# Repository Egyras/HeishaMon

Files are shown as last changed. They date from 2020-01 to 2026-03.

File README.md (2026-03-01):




# Panasonic H, J, K & L Series Aquarea air-water heat pump protocol

This project makes it possible to read information from Panasonic Aquarea heat pump and report the data either to an MQTT server or as JSON format over HTTP.

Eine deutschsprachige [README_DE.md](README_DE.md) findest du hier. \
Een nederlandse vertaling [README_NL.md](README_NL.md) vind je hier. \
Suomen kielellä [README_FI.md](README_FI.md) luettavissa täällä.

*Help on translation to other languages is welcome.*

# Current releases
Latest release is available [here](https://github.com/Egyras/HeishaMon/releases). The ESP8266 compiled binary can be installed on a Wemos D1 mini, on the HeishaMon PCB and generally on any ESP8266 based board compatible with Wemos build settings (at least 4MB flash). You can also download the code and compile it yourself (see required libraries below). The ESP32-S3 binary is for the newer, large, version of heishamon.

# Using the software
HeishaMon is able to communicate with the Panasonic Aquarea H, J, K and L&series. [Confirmed by users types of HP you can find here](HeatPumpType.md) \
If you want to compile this image yourself be sure to use the mentioned libraries and support for a filesystem on the esp8266 so select the correct flash option in arduino ide for that.

When starting, without a configured wifi, an open-wifi-hotspot will be visible allowing you to configure your wifi network and your MQTT server. Configuration page will be located at http://192.168.4.1 . \

After configuring and booting the image will be able to read and talk to your heatpump. The GPIO13/GPIO15 connection will be used for communications so you can keep your computer/uploader connected to the board if you want. \
Serial 1 (GPIO2) can be used to connect another serial line (GND and TX from the board only) to read some debugging data.

All received data will be sent to different MQTT topics (see below for topic descriptions). There is also a 'panasonic_heat_pump/log' MQTT topic which provides debug logging and a hexdump of the received packets (if enabled in the web portal).

You can connect a 1wire network on GPIO4 which will report in seperate MQTT topics (panasonic_heat_pump/1wire/sensorid).

The software is also able to measure Watt on a S0 port of two kWh meters. You only need to connect GPIO12 and GND to the S0 of one kWh meter and if you need a second kWh meter use GPIO14 and GND. It will report on MQTT topic panasonic_heat_pump/s0/Watt/1 and panasonic_heat_pump/s0/Watt/2 and also in the JSON output. You can replace 'Watt' in the previous topic with 'Watthour' to get consumption counter in WattHour (per mqtt message) or to 'WatthourTotal' to get the total consumption measured in WattHour. To sync the WatthourTotal with your kWh-meter, publish the correct value to MQTT to the panasonic_heat_pump/s0/WatthourTotal/1 or panasonic_heat_pump/s0/WatthourTotal/2 topic with the 'retain' option while heishamon is rebooting. Upon reboot, heishamon reads this value as the last known value to you can sync using this method.

Updating the firmware is as easy as going to the firmware menu and, after authentication with username 'admin' and password 'heisha' (or other provided during setup), uploading the binary there.

A json output of all received data (heatpump and 1wire) is available at the url http://heishamon.local/json (replace heishamon.local with the ip address of your heishamon device if MDNS is not working for you).

Within the 'integrations' folder you can find examples how to connect your automation platform to the HeishaMon.

# Rules functionality
The rules functionality allows you to control the heatpump from within the HeishaMon itself. Which makes it much more reliable then having to deal with external domotica over WiFi. When posting a new ruleset, it is immidiatly validated and when valid used. When a new ruleset is invalid it will be ignored and the old ruleset will be loaded again. You can check the console for feedback on this. If somehow a new valid ruleset crashes the HeishaMon, it will be automatically disabled the next reboot, allowing you to make changes. This prevents the HeishaMon getting into a boot loop.

The techniques used in the rule library allows you to work with very large rulesets, but best practice is to keep it below 10.000 bytes.

Notice that sending commands to the heatpump is done asynced. So, commands sent to the heatpump at the beginning of your syntax will not immediatly be reflected in the values from the heatpump later on. Therefor, heatpump values should be read from the heatpump itself instead of those based on the values you keep yourself.

## Syntax
Two general rules are that spaces are mandatory and semicolons are used as end-of-line character.

### Variables
The ruleset uses the following variable structure:

- `#`: Globals
These variables can be accessed throughout the ruleset but have to defined inside a rule block. Don't use globals for all your variables, because it will persistently use memory.

- `$`: Locals
These variables live inside a rule block. When a rule block finishes, these variables will be cleaned up, freeing any memory used.

- `@`: Heatpump parameters
These are the same as listed in the Manage Topics documentation page and as found on the HeishaMon homepage. The ruleset also follows the R/W logic as used through the MQTT and REST API. That means that the read topics differ from the write topics. So reading the heatpump state is done through `@Heatpump_State`, changing the heatpump state through `@SetHeatpump`.

- `%`: Datetime variables
These can be used for date and time based rules. Currently `%hour` (0 - 23), `%minute` (0 - 59), `%month` (1 - 12), and `day` (1 - 7)  are supported. All are plain integers. A proper NTP configuration is needed to set the correct system date and time on the HeishaMon.

- `?`: Thermostat parameters
These variables reflect parameters read from the connected thermostat when using the OpenTherm functionality. When OpenTherm is supported this documentation will be extended with more precise information. The can check the opentherm tab for the variables that can be used. The names are the same for reading and writing, but not all values support reading and/or writing. The opentherm tab also lists this.

- `ds18b20#2800000000000000`: Dallas 1-wire temperature values
Use these variables to read the temperature of the connected sensors. These values are of course readonly. The id of the sensor should be placed after the hashtag.

- `s0#watt[hour[total]]_?`: The S0 values for port 1 and 2. Replace the question mark with the port number.
For example s0#watt_1 to get watt from port 1 and s0#watthourtotal_2 to get total watthours from port 2

When a variable is called but not yet set to a value, the value will be `NULL`.

Variables can be of boolean (`1` or `0`), float (`3.14`), integer (`10`), and string type. Defining strings is done with single or double quotes.

### Events or functions
Rules are written in `event` or `function` blocks. These are blocks that are triggered when something happened; either a new heatpump or thermostat value has been received or a timer fired. Or can be used as plain functions

```
on [event] then
  [...]
end

on [name] then
  [...]
end
```

Events can be Heatpump or thermostat parameters or timers:
```
on @Heatpump_State then
  [...]
end

on ?setpoint then
  [...]
end

on timer=1 then
  [...]
end
```

When defining functions, you just name your block and then you can call it from anywhere else:
```
on foobar then
  [...]
end

on @Heatpump_State then
  foobar();
end
```

Functions can have parameters which you can call:
```
on foobar($a, $b, $c) then
  [...]

on @Heatpump_State then
  foobar(1, 2, 3);
end
```

If you call a function less values then the function takes, all other parameters will have a NULL value.

There is currently one special function that calls when the system is booted on when a new ruleset is saved:
```
on System#Boot then
  [...]
end
```

This special function can be used to initially set your globals or certain timers.

### Operators
Regular operators are supported with their standard associativity and precedence. This allows you to also use regular math.
- `&&`: And
- `||`: Or
- `==`: Equals`
- `>=`: Greater or equal then
- `>`: Greater then
- `<`: Lesser then
- `<=`: Lesser or equal then
- `-`: Minus
- `%`: Modulus
- `*`: Multiply
- `/`: Divide
- `+`: Plus
- `^`: Power

Parenthesis can be used to prioritize operators as it would work in regular math.

### Functions
- `coalesce`
Returns the first value not `NULL`. E.g., `$b = NULL; $a = coalesce($b, 1);` will return 1. This function accepts an unlimited number of arguments.

- `max`
Returns the maximum value of the input parameters.

- `min`
Returns the minimum value of the input parameters.

- `isset`
Return boolean true when the input variable is still `NULL` in any other cases it will return false.

- `round`
Rounds the input float to the nearest integer.

- `floor`
The largest integer value less than or equal to the input float.

- `ceil`
The smallest integer value greater than or equal to the input float.

- `setTimer`
Sets a timer to trigger in X seconds. The first parameter is the timer number and the second parameters the number of seconds before it fires. A timer only fires once so it has to be re-set for recurring events. When a timer triggers it will can the timer event as described above. E.g.

- `print`
Prints a value to the console.

- `concat`
Concatenates various values into a combined string. E.g.: `@SetCurves = concat('{zone1:{heat:{target:{high:', @Z1_Heat_Curve_Target_High_Temp, ',low:32}}}}');`

- `gpio`
Allows setting or getting a GPIO state. When called with a single argument, a GPIO state is returned. When called with two arguments the state of a GPIO is set. This function only sets digital pins so the state can only be 0 or 1. The two relays on the large heishamon are gpio21 and gpio47. See the example to switch them each two seconds.

```
on System#Boot then
   setTimer(10, 2);
end

on timer=10 then
   setTimer(20, 2);
   gpio(21,0);
   gpio(47,1);
end

on timer=20 then
   setTimer(10, 2);
   gpio(21,1);
   gpio(47,0);
end
```

### Conditions
The only supported conditions are `if`, `else`, and `elseif`:

```
if [condition] then
  [...]
else
  if [condition] then
    [...]
  end
end
```

```
if [condition] then
  [...]
elseif [condition] then
  if [condition] then
    [...]
  else
    [...]
  end
elseif [condition] then
  [...]
else
  [...]
end
```

### Examples
Once the rules system is in used by more and more users, additional examples will be added to the documentation.

*Calculating WAR*
```
on calcWar($Ta1, $Tb1, $Ta2, $Tb2) then
	#maxTa = $Ta1;

	if @Outside_Temp >= $Tb1 then
		#maxTa = $Ta1;
	elseif @Outside_Temp <= $Tb2 then
		#maxTa = $Ta2;
	else
		#maxTa = $Ta1 + (($Tb1 - @Outside_Temp) * ($Ta2 - $Ta1) / ($Tb1 - $Tb2));
	end
end
```

*Thermostat setpoint*
```
on ?roomTemp then
	calcWar(32, 14, 41, -4);

	$margin = 0.25;

	if ?roomTemp > (?roomTempSet + $margin) then
		if @Heatpump_State == 1 then
			@SetHeatpump = 0;
		end
	elseif ?roomTemp < (?roomTempSet - $margin) then
		if @Heatpump_State == 0 then
			@SetHeatpump = 1;
		end
	else
		@SetZ1HeatRequestTemperature = round(#maxTa);
	end
end
```

# Factory reset
A factory reset can be performed on the web interface but if the web interface is unavailable you can perform a double reset. The double reset should be performed not too fast but also not too slow. Usually halve a second between both resets should do the trick. To indicate that the double reset performed a factory reset, the blue led will flash rapidly (You need to press reset again now to restart HeishaMon back to normal where a WiFi hotspot should be visible again).

# Further information
Below you can find some technical details about the project. How to build your own cables. How to build your own PCB etc.

## Connection details:
Communication can be established thru one of the two sockets: CN-CNT or CN-NMODE. If you have an existing Panasonic CZ-TAW1 WiFi interface that you want to replace with HeishaMon, it is only a matter of plugging the cable out from CZ-TAW1 and reconnecting to your HeishaMon device. However it is not possible to use HeishaMon and the original CZ-TAW1 module together as an active device. It is however possible to put HeishaMon on "Listen Only" mode which will allow HeishaMon and the original CZ-TAW1 module to co-exist. The only downside to this is that HeishaMon is unable to send commands and use the optional PCB option.

Communication parameters: TTL 5V UART 9600,8,E,1  \
 \
CN-CNT Pin-out (from top to bottom) \
1 - +5V (250mA)  \
2 - 0-5V TX (from heatpump) \
3 - 0-5V RX (to heatpump)\
4 - +12V (250mA) \
5 - GND \
 \
CN-NMODE Pin-out (from left to right) \
"Warning! As printed on the PCB, the left pin is pin 4 and right pin is pin 1. Do not count 1 to 4 from left!  \
4 - +5V (250mA)  \
3 - 0-5V TX (from heatpump) \
2 - 0-5V RX (to heatpump) \
1 - GND

HeishaMon will receive power from the Panasonic over the cable (5v power).

## Long distance connection
It it possible to connect the HeishaMon over a long distance. Up to 5 meter is working with normal cabling. For longer distances a TTL-to-RS485 configuration as show in the picture below is possible. The however requires HeishaMon to be powered externally using 5v power (for example from an USB cable).

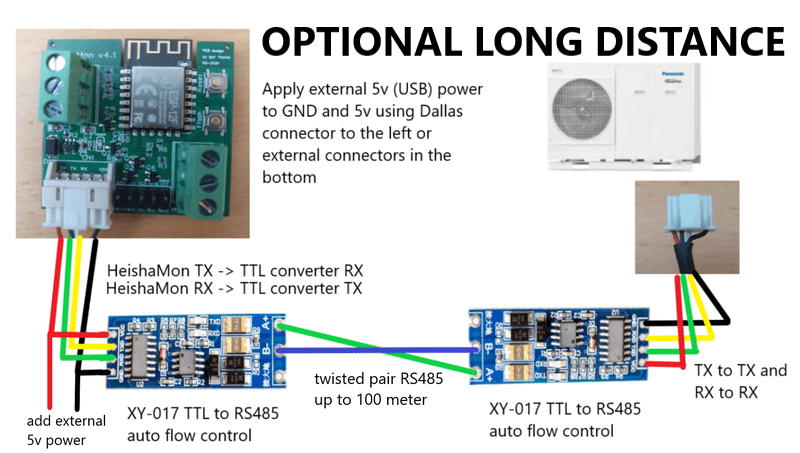
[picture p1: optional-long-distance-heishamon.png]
TTL-over-RS485 HeishaMon long distance


## Where to get connectors
[RS-Online orders](Connectors_RSO.md)

[Conrad orders](Connectors_Conrad.md)

Use some 24 AWG shielded 4-conductors cable.

## The HeishaMon hardware itself
The PCB's needed to connect to the heatpump are designed by project members and are listed below. The most important part of the hardware is a level shifting between 5v from the Panasonic to 3.3v of the HeishaMon and a GPIO13/GPIO15 enable line after boot. \
[PCD Designs from the project members](PCB_Designs.md) \
[Picture Wemos D1 beta](WEMOSD1.JPG) \
[Picture ESP12-F](NewHeishamon.JPG)

To make things easy you can order a completed PCB from some project members: \
[Tindie shop](https://www.tindie.com/stores/thehognl/) from Igor Ybema (aka TheHogNL) based in the Netherlands

## Building the arduino image yourself
boards: \
esp8266 by esp8266 community version 3.0.2 [Arduino](https://github.com/esp8266/Arduino/releases/tag/3.0.2)

All the [libs we use](LIBSUSED.md) necessary for compiling.

## MQTT topics
[Current list of documented MQTT topics can be found here](MQTT-Topics.md)

## Communication reliability
Messages from HeishaMon to the heatpump will occasionally be dropped, especially if multiple settings are changed within a short time. It's not feasible for HeishaMon to retry all dropped messages, so users should implement their own retry logic.

The suggested retry logic is as follows:
1. After changing a heatpump setting via HeishaMon, you should wait for HeishaMon to report that the setting has been changed.
2. If the setting isn't updated after 10 seconds, set it again.

This can be implemented on the HeishaMon itself using Rules if you wish, as in this example:
```
on StopExternalControl then
  if @External_Control != 0 then
    @SetExternalControl = 0;
    settimer(9,10);
  end
end

on timer=9 then
  if @External_Control != 0 then
    @SetExternalControl = 0;
  end
end
```

## EEPROM warning
As until today we don't know how the commands sent to the heatpump are processed in the heatpump itself. Most probably a lot of commands are written to EEPROM to be stored and available after a power failure, like setting the DHW temp. An EEPROM can facility a lot of writes but there is a limit. And we don't know the limit either. So make sure you don't overload the heatpump with too many commands. Every second is way too much. Just a few per hour, per settings, should probably be fine. Anyway, an heatpump is a slow heating(cooling) device so making changes that often is probably not even going to make any sense either.

## DS18b20 1-wire support
The software also supports ds18b20 1-wire temperature sensors reading. A proper 1-wire configuration (with 4.7kohm pull-up resistor) connected to GPIO4 will be read each configured secs (minimal 5) and send at the panasonic_heat_pump/1wire/"sensor-hex-address" topic. On the pre-made boards this 4.7kohm resistor is already installed.

## Large board relay control
The newer, large, heishamon contains two onboard relays which can be switched on and off using MQTT commands. The relays can be used for any contact switching, even 230V mains (max 5A). For example to switch the 230V contacts in the heatpump for controlling the 'external thermostat', switching a pump on or off or other lower power devices. I do not recommend to use the relay as a switch for a electric heater as they use too much power. To control the relay just send a value of 1 or 0 to the MQTT topic "panasonic_heat_pump/gpio/relay/one" for relay one or "panasonic_heat_pump/gpio/relay/two" for relay two.

## Opentherm support
If your heishamon board supports opentherm the software can also be used to bridge opentherm information from a compatible thermostat to your home automation over MQTT or JSON and as mentioned above it can also be connected directly in the rules to connect opentherm information to the heatpump and back, for example to display the outside temperature from the heatpump on your opentherm thermostat. If you enable opentherm support in settings there will be a new tab visible in the web page. On that tab you will see opentherm values. Some are of type R(ead) and some are W(rite), and some are both. Read means that the thermostat can read that information from the heishamon. You provide that information over MQTT (or using the rules) by updating this value on the mqtt 'opentherm/read' topic, for example 'panasonic_heat_pump/opentherm/read/outsideTemp'. The write values are information from the thermostat, like 'roomTemp'. These are available on mqtt topic 'opentherm/write'. You can use these values to change the heatpump behaviour in anyway you want using your home automation and mqtt set-commands to heishamon on using the internal rules.

The available opentherm variables are:
### WRITE values
- chEnable which is a boolean showing if central heating shoud be enabled. This is often used when the thermostat wants to heat up your house.
- dhwEnable which is a boolean showing if the dhw heating should be enabled. Often used as a user option on the thermostat to disable DHW heating during vacation
- coolingEnable which is a boolean showing if  cooling should be enabled. Amount of cooling is request in 'coolingControl', see below.
- roomTemp is the floating point value of the measured room temp by thermostat
- roomTempSet is the floating point value of the requested room temp setpoint on the thermostat
- chSetpoint is the floating point value of the calculated water setpoint by thermostat. Opentherm thermostats try to set this chSetpoint to not overshoot the room setpoint. Could be used to set the water setpoint on the heatpump but most thermostats are too fast responding compared to how heatpumps work
- maxRelativeModulation is the amount of modulation (0-100%) the heatpump (opentherm slave) is allowed to use (see relativeModulation in READ values, which should always be equal or lower than this max)
- coolingControl is the amount of cooling (0-100%) the thermostat requests from the heatpump. Requires an opentherm thermostat with cooling support.
### READ AND WRITE values
- dhwSetpoint is the floating point value which is the current DHW setpoint by thermostat, but can also be set by heishamon to override it. Not all thermostat support this though. It should not be set higher than dhwSetUppBound, see below.
- maxTSet is the floating point value which defines the maximum water setpoint. The user can set this on the thermostat or can also set from heishamon. It should not be set higher than chSetUppBound, see below.
### READ values
- chPressure is the floating point value which defines measured water pressure of central heating provided by heishamon
- outsideTemp is the floating point value which defines measured outside temperature of central heating provided by heishamon
- inletTemp is the floating point value which defines measured water inlet temperature of central heating provided by heishamon
- outletTemp is the floating point value which defines measured water outlet temperature of central heating provided by heishamon
- dhwTemp is the floating point value which defines measured dhw temperature of central heating provided by heishamon
- relativeModulation is the amount (0-100%) of modulation the heatpump (opentherm slave) is currently running on, should always be lower or equal than the maxRelativeModulation set by the thermostat
- flameState is a boolean value (send 'true', 'on' or '1' to enable) which defines if the central heating is providing heat central
- chState is a boolean value (send 'true', 'on' or '1' to enable) which defines if the heatpump is on room/central heating mode (for example 3-way valve on room, in heating mode)
- dhwState is a boolean value (send 'true', 'on' or '1' to enable) which defines if the heatpump is on DHW mode (for example 3-way valve on dhw)
- coolingState is a boolean value (send 'true', 'on' or '1' to enable) which defines if the heatpump is on room/central cooling mode (for example 3-way valve on room, in cooling mode)
- dhwSetUppBound is a integer value from 0 to 127 which sets the max DHW temperature supported so the thermostat can not request a dhwSetpoint higher than this. Default is set to 75. To override, send a MQTT message to this topic and make it retained so heishamon receives it again after reboot.
- dhwSetLowBound is a integer value from 0 to 127 which sets the min DHW temperature supported so the thermostat can not request a dhwSetpoint lower than this. Default is set to 40. To override, send a MQTT message to this topic and make it retained so heishamon receives it again after reboot.
- chSetUppBound is a integer value from 0 to 127 which sets the max CH (heating water) temperature supported so the thermostat can not request a chSetpoint higher than this. Default is set to 65. To override, send a MQTT message to this topic and make it retained so heishamon receives it again after reboot.
- chSetLowBound is a integer value from 0 to 127 which sets the min CH (heating water) temperature supported so the thermostat can not request a chSetpoint lower than this. Default is set to 20. To override, send a MQTT message to this topic and make it retained so heishamon receives it again after reboot.

## Protocol byte decrypt info:
[Current list of documented bytes decrypted can be found here](ProtocolByteDecrypt.md)

## MQTT TLS support:
TLS support or MQTT is currently implemented only for the ESP32 version. TLS is disabled by default and can be enabled in the settings. When enabling, make sure that your MQTT broker accepts secure connection from heishamon, including setting up a PEM CA certificate (e.g. self-signed). Such a certificate will roughly look as follows (the x's being seemingly random characters... the BEGIN and END lines belong to the certificate):
-----BEGIN CERTIFICATE-----
xxxxxxxxxxxxxxxxxxxxxxxxxxxxxxxxxxxxxxxxxxxxxxxxxxxxxxxxxxxxxxxxxxxxxxxxxxxxxxxx
xxxxxxxxxxxxxxxxxxxxxxxxxxxxxxxxxxxxxxxxxxxxxxxxxxxxxxxxxxxxxxxxxxxxxxxxxxxxxxxx
xxxxxxxxxxxxxxxxxxxxxxxxxxxxxxxxxxxxxxxxxxxxxxxxxxxxxxxxxxxxxxxxxxxxxxxxxxxxxxxx
===========THIS=====IS====JUST===A====PLACEHOLDER===============================
xxxxxxxxxxxxxxxxxxxxxxxxxxxxxxxxxxxxxxxxxxxxxxxxxxxxxxxxxxxxxxxxxxxxxxxxxxxxxxxx
xxxxxxxxxxxxxxxxxxxxxxxxxxxxxxxxxxxxxxxxxxxxxxxxxxxxxxxxxxxxxxxxxxxxxxxxxxxxxxxx
xxxxxxxxxxxxxxxxxxxxxxxxxxxxxxxxxxxxxxxxxxxxxxxxxxxxxxxxxxxxxxxxxxxxxxxxxxxxxxxx
-----END CERTIFICATE-----
Upolad a text file (plain text with suffix pem, e.g. "CA.pem") of the certificate to heishamon in the setting screen. If the syntaxt is correct it will be stored, otherwise discarded. After having uploaded the certificate, activate TLS support and (in usual setups) switch the MQTT port to 8883. !!There will be no support for TLS problems!! Google can help you with problems. In case of problems, first try without TLS support and only after that works try to switch TLS support on.
Currently, there is no possibility to delete a once-uploaded CA certificate. So if you want to remove your certificate, simply upload the dummy/sample above.

## Integration Examples for Opensource automation systems
[Openhab2](Integrations/Openhab2)

[Home Assistant](Integrations/Home%20Assistant)

[IOBroker Manual](Integrations/ioBroker_manual)

[Domoticz](Integrations/Domoticz)

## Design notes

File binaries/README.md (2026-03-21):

This directory contains released and test versions for the HeishaMon software. 

The latest production release is v4.1. 

Make sure you use the correct firmware for your model. The 'small' version is for the HeishaMon PCB which has the ESP8266 chip. The 'large' version is for the newer ESP32-S3 HeishaMon PCB. You can recognize the 'large' version as the one with optional ethernet support and the two blue relays. The large board is about 10x10cm while the small version is about 4x4cm (without OT) or 4x5cm(with OT).

If you upload the wrong firmware you can brick your HeishaMon and you need to recover it using a USB-TTL cable for the small version and a USB-C cable for the large version.

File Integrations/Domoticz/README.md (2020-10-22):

# Heishamon in Domoticz

There are two options to integrate HeishaMon into Domoticz. You can choose for the domoticz plugin or a nodered flow. The domoticz plugin is plug-and-play but the nodered flow will allow you to more fine tune your system to your needs.

## Plugin option

A domoticz plugin (https://github.com/MarFanNL/HeishamonMQTT) is available which, once installed, will create the necessary device and will talk to mqtt for you.

## Nodered option

Prerequisite:
- Domoticz with mqtt setup
- node-red with mosquitto (optionally with https://flows.nodered.org/node/node-red-contrib-influxdb installed)
- Working PCB with Heishamon firmware installed

Installation instructions:

In Influx:
- create a database called "Panasonic" (go to SSH console -> typ "influx" -> typ "create database Panasonic" -> typ "show databases" and see if Panasonic is listed)

In Node-red:
- import the 'json' file 
- adjust the IDX values in the Node-Red function 'global setup' to the IDX values of your install. 
- note: you have to adjust values under "SensorMapping" (values from Panasonic to Domoticz) and "ActionMapping" (Domoticz commands to Panasonic). These IDX values can be the same. 
- If nodered is on other server then the influx or MQTT server then change these IP addresses in the outgoing and incoming nodes.
- If you are not using influx out open the "influx out" node and disable it (bottom of the screen)

For example create these devices in Domoticz:
- Create the following dummy sensors in Domoticz and use the IDX values in the corresponding lines in the setup node.
  Temperature:
  - Outlet
  - Inlet
  - Outdoor
  Percentage:
  - Pumpspeed 
  - Compressor frequency
  Counter:
  - startstops 
  - working hours
  
- Create the following switches:
  - On Off switch (switch heatpump on/off)
  - Selector switch (to set the silent mode: Off, silent 1, Silent 2, Silent 3)
  - Thermostat Setpoint (to set the heatpump setpoint or temperature shift)

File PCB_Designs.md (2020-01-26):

## PCB designs

### (beta) production 2019 / 2020

| Soldering technique | Type | Link | Status |
| ----- | ---- | --- | ---: |
| Through hole soldering | Wemos shield type. With basic components (resistors and transistors)| https://easyeda.com/igor_6537/panasonic-cn-cnt-to-wemos-through-hole | beta |
| SMD+PCB delivering, only pin headers soldering | Wemos shield type. With SMD components (mosfet instead of transistors) | https://easyeda.com/igor_6537/panasonic-cn-cnt-to-wemos | beta |
| SMD+PCB delivering, only pin headers soldering  | Wemos shield type. Adding extra features (1wire, s0, relay) | https://easyeda.com/igor_6537/panasonic-cn-cnt-to-wemos_copy  | beta |
| Requires SMD soldering | ESP-12f type | https://easyeda.com/kompiuteriu/new-cn-cnt| beta |
| Requires SMD soldering | ESP-12f type with 1wire support| https://easyeda.com/kompiuteriu/new-cn-cnt_copy | beta |

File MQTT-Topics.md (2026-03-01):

# MQTT Topics for HeishaMon

## Availability Topic:

ID | Topic | Response
--- | --- | ---
|| LWT | Online/Offline (automatically returns to Offline if connection with the HeishaMon lost)

## Log Topic:

ID | Topic | Response
--- | --- | ---
LOG1 | log | response from headpump (level switchable)

## Sensor Topics:

ID | Topic | Response/Description
:--- | --- | ---
TOP0 | main/Heatpump_State | Heatpump state (0=off, 1=on)
TOP1 | main/Pump_Flow | Pump flow (l/min)
TOP2 | main/Force_DHW_State | DHW status (0=off, 1=on)
TOP3 | main/Quiet_Mode_Schedule | Quiet mode schedule (0=inactive, 1=active)
TOP4 | main/Operating_Mode_State | Operating mode (0=Heat only, 1=Cool only, 2=Auto(Heat), 3=DHW only, 4=Heat+DHW, 5=Cool+DHW, 6=Auto(Heat)+DHW, 7=Auto(Cool), 8=Auto(Cool)+DHW)
TOP5 | main/Main_Inlet_Temp | Main inlet water temperature (°C)
TOP6 | main/Main_Outlet_Temp | Main outlet water temperature (°C)
TOP7 | main/Main_Target_Temp | Main outlet water target temperature (°C)
TOP8 | main/Compressor_Freq | Compressor frequency (Hz)
TOP9 | main/DHW_Target_Temp | DHW target temperature (°C)
TOP10 | main/DHW_Temp | Actual DHW temperature (°C)
TOP11 | main/Operations_Hours | Heatpump operating time (Hours)
TOP12 | main/Operations_Counter | Heatpump starts (counter)
TOP13 | main/Main_Schedule_State | Main thermostat schedule state (0=inactive, 1=active)
TOP14 | main/Outside_Temp | Outside ambient temperature (°C)
TOP15 | main/Heat_Power_Production | Thermal heat power production (Watt)
TOP16 | main/Heat_Power_Consumption | Elektrical heat power consumption at heat mode (Watt)
TOP17 | main/Powerful_Mode_Time | Powerful state in minutes (0, 1, 2 or 3 x 30min)
TOP18 | main/Quiet_Mode_Level | Quiet mode level (0=off, 1=less power, 2=even less power, 3=least power)
TOP19 | main/Holiday_Mode_State | Holiday mode (0=off, 1=scheduled, 2=active)
TOP20 | main/ThreeWay_Valve_State | 3-way valve mode (0=Room, 1=DHW)
TOP21 | main/Outside_Pipe_Temp | Outside pipe temperature (°C)
TOP22 | main/DHW_Heat_Delta | DHW heating delta (-12 to -2) (K)
TOP23 | main/Heat_Delta | Heat delta (K)
TOP24 | main/Cool_Delta | Cool delta (K)
TOP25 | main/DHW_Holiday_Shift_Temp | DHW Holiday shift temperature  (-15 to +15)
TOP26 | main/Defrosting_State | Defrost state (0=off, 1=on)
TOP27 | main/Z1_Heat_Request_Temp | Zone 1 Heat Requested shift temp (-5 to 5) or direct heat temp (20 to max)
TOP28 | main/Z1_Cool_Request_Temp | Zone 1 Cool Requested shift temp (-5 to 5) or direct cool temp (5 to 20)
TOP29 | main/Z1_Heat_Curve_Target_High_Temp | Target temperature at lowest point on the heating curve (°C)
TOP30 | main/Z1_Heat_Curve_Target_Low_Temp | Target temperature at highest point on the heating curve (°C)
TOP31 | main/Z1_Heat_Curve_Outside_High_Temp | Lowest outside temperature on the heating curve (°C)
TOP32 | main/Z1_Heat_Curve_Outside_Low_Temp | Highest outside temperature on the heating curve (°C)
TOP33 | main/Room_Thermostat_Temp | Remote control thermostat temp (°C)
TOP34 | main/Z2_Heat_Request_Temp | Zone 2 Heat Requested shift temp (-5 to 5) or direct heat temp (20 to max)
TOP35 | main/Z2_Cool_Request_Temp | Zone 2 Cool Requested shift temp (-5 to 5) or direct cool temp (5 to 20)
TOP36 | main/Z1_Water_Temp | Zone 1 Water outlet temperature (°C)
TOP37 | main/Z2_Water_Temp | Zone 2 Water outlet temperature (°C)
TOP38 | main/Cool_Power_Production | Thermal cooling power production (Watt)
TOP39 | main/Cool_Power_Consumption | Elektrical cooling power consumption (Watt)
TOP40 | main/DHW_Power_Production | Thermal DHW power production (Watt)
TOP41 | main/DHW_Power_Consumption | Elektrical DHW power consumption (Watt)
TOP42 | main/Z1_Water_Target_Temp | Zone 1 water target temperature (°C)
TOP43 | main/Z2_Water_Target_Temp | Zone 2 water target temperature (°C)
TOP44 | main/Error | Last active Error from Heat Pump
TOP45 | main/Room_Holiday_Shift_Temp | Room heating Holiday shift temperature (-15 to 15)
TOP46 | main/Buffer_Temp | Actual Buffer temperature (°C)
TOP47 | main/Solar_Temp | Actual Solar temperature (°C)
TOP48 | main/Pool_Temp | Actual Pool temperature (°C)
TOP49 | main/Main_Hex_Outlet_Temp | Outlet 2, after heat exchanger water temperature (°C)
TOP50 | main/Discharge_Temp | Discharge Temperature (°C)
TOP51 | main/Inside_Pipe_Temp | Inside pipe temperature (°C)
TOP52 | main/Defrost_Temp | Defrost temperature (°C)
TOP53 | main/Eva_Outlet_Temp | Eva Outlet temperature (°C)
TOP54 | main/Bypass_Outlet_Temp | Bypass Outlet temperature (°C)
TOP55 | main/Ipm_Temp | Ipm temperature (°C)
TOP56 | main/Z1_Temp | Zone1: Actual Temperature (°C) 
TOP57 | main/Z2_Temp | Zone2: Actual Temperature (°C) 
TOP58 | main/DHW_Heater_State | When enabled, backup/booster heater can be used for DHW heating (0=disabled, 1=enabled)
TOP59 | main/Room_Heater_State | When enabled, backup heater can be used for room heating (0=disabled, 1=enabled)
TOP60 | main/Internal_Heater_State | Internal backup heater state (0=inactive, 1=active)
TOP61 | main/External_Heater_State | External backup/booster heater state (0=inactive, 1=active)
TOP62 | main/Fan1_Motor_Speed | Fan 1 Motor rotation speed (R/Min)
TOP63 | main/Fan2_Motor_Speed | Fan 2 Motor rotation speed (R/Min)
TOP64 | main/High_Pressure | High Pressure (Kgf/Cm2)
TOP65 | main/Pump_Speed | Pump Rotation Speed (R/Min)
TOP66 | main/Low_Pressure | Low Pressure (Kgf/Cm2)
TOP67 | main/Compressor_Current | Compressor/Outdoor unit Current (Ampere)
TOP68 | main/Force_Heater_State | Force heater status (0=inactive, 1=active)
TOP69 | main/Sterilization_State | Sterilisation State (0=inactive, 1=active)
TOP70 | main/Sterilization_Temp | Sterilisation Temperature (°C)
TOP71 | main/Sterilization_Max_Time | Sterilisation maximum time (minutes)
TOP72 | main/Z1_Cool_Curve_Target_High_Temp | Target temperature at highest point on the cooling curve (°C)
TOP73 | main/Z1_Cool_Curve_Target_Low_Temp | Target temperature at lowest point on the cooling curve (°C)
TOP74 | main/Z1_Cool_Curve_Outside_High_Temp | Highest outside temperature on the cooling curve (°C)
TOP75 | main/Z1_Cool_Curve_Outside_Low_Temp | Lowest outside temperature on the cooling curve (°C)
TOP76 | main/Heating_Mode | Compensation / Direct mode for heat (0 = compensation curve, 1 = direct)
TOP77 | main/Heating_Off_Outdoor_Temp | Above this outdoor temperature all heating is turned off(5 to 35 °C)
TOP78 | main/Heater_On_Outdoor_Temp | Below this temperature the backup heater is allowed to be used by heatpump heating logic(-15 to 20 °C)
TOP79 | main/Heat_To_Cool_Temp | Outdoor temperature to switch from heat to cool mode when in auto setting(°C)
TOP80 | main/Cool_To_Heat_Temp | Outdoor temperature to switch from cool to heat mode when in auto setting (°C)
TOP81 | main/Cooling_Mode | Compensation / Direct mode for cool (0 = compensation curve, 1 = direct)
TOP82 | main/Z2_Heat_Curve_Target_High_Temp | Target temperature at lowest point on the heating curve (°C)
TOP83 | main/Z2_Heat_Curve_Target_Low_Temp | Target temperature at highest point on the heating curve (°C)
TOP84 | main/Z2_Heat_Curve_Outside_High_Temp | Lowest outside temperature on the heating curve (°C)
TOP85 | main/Z2_Heat_Curve_Outside_Low_Temp | Highest outside temperature on the heating curve (°C)
TOP86 | main/Z2_Cool_Curve_Target_High_Temp | Target temperature at highest point on the cooling curve (°C)
TOP87 | main/Z2_Cool_Curve_Target_Low_Temp | Target temperature at lowest point on the cooling curve (°C)
TOP88 | main/Z2_Cool_Curve_Outside_High_Temp | Highest outside temperature on the cooling curve (°C)
TOP89 | main/Z2_Cool_Curve_Outside_Low_Temp | Lowest outside temperature on the cooling curve (°C)
TOP90 | main/Room_Heater_Operations_Hours | Electric heater operating time for Room (Hour)
TOP91 | main/DHW_Heater_Operations_Hours | Electric heater operating time for DHW (Hour)
TOP92 | main/Heat_Pump_Model | Heat pump model, all values in HeatPumpType.md
TOP93 | main/Pump_Duty | Pump duty
TOP94 | main/Zones_State | Zones state (0 = zone1 active, 1 = zone2 active, 2 = zone1 and zone2 active)
TOP95 | main/Max_Pump_Duty | Max pump duty configured
TOP96 | main/Heater_Delay_Time | Heater delay time (J-series only)
TOP97 | main/Heater_Start_Delta | Heater start delta (J-series only)
TOP98 | main/Heater_Stop_Delta | Heater stop delta (J-series only)
TOP99 | main/Buffer_Installed | Buffer tank installed
TOP100 | main/DHW_Installed | DHW tank installed
TOP101 | main/Solar_Mode | Solar mode (disabled, to buffer, to DHW)
TOP102 | main/Solar_On_Delta | Solar heating delta on
TOP103 | main/Solar_Off_Delta | solar heating delta off
TOP104 | main/Solar_Frost_Protection | Solar frost protection temp
TOP105 | main/Solar_High_Limit | Solar max temp limit
TOP106 | main/Pump_Flowrate_Mode | Settings for pump flow rate (0=DeltaT, 1=Maximum flow, J-series only)
TOP107 | main/Liquid_Type | Type of liquid in settings (Water / Glycol)
TOP108 | main/Alt_External_Sensor | If external outdoor sensor is selected
TOP109 | main/Anti_Freeze_Mode | Is anti freeze mode enabled or disabled
TOP110 | main/Optional_PCB | If the optional PCB is enabled (if installed)
TOP111 | main/Z2_Sensor_Settings | Setting of the sensor for zone 2 (0=water, 1=ext thermostat, 2=int. thermostat or thermistor)
TOP112 | main/Z1_Sensor_Settings | Setting of the sensor for zone 1 (0=water, 1=ext thermostat, 2=int. thermostat or thermistor)
TOP113 | main/Buffer_Tank_Delta | Delta of buffer tank setting in Kelvin
TOP114 | main/External_Pad_Heater | If the external pad heater is enabled (if installed)
TOP115 | main/Water_Pressure | Water Pressure in bar (K/L series)
TOP116 | main/Second_Inlet_Temp | Water Inlet 2 Temperature(K/L series)
TOP117 | main/Economizer_Outlet_Temp | Economizer Outlet Temperature (K/L series)
TOP118 | main/Second_Room_Thermostat_Temp | Remote control 2 thermostat temp (°C)
TOP119 | main/External_Control | Is the external control switch enabled
TOP120 | main/External_Heat_Cool_Control | Is the heat/cool control switch enabled (optional pcb setting)
TOP121 | main/External_Error_Signal | Is the external error signal enabled
TOP122 | main/External_Compressor_Control | Is the external compressor control enabled (optional pcb setting)
TOP123 | main/Z1_Pump_State | Zone 1 Pump State
TOP124 | main/Z2_Pump_State | Zone 2 Pump State
TOP125 | main/TwoWay_Valve_State | 2-Way Valve State
TOP126 | main/ThreeWay_Valve_State2 | 3-Way Valve State (2nd definition)
TOP127 | main/Z1_Valve_PID | PID Value for Zone 1 mixing valve
TOP128 | main/Z2_Valve_PID | PID Value for Zone 2 mixing valve
TOP129 | main/Bivalent_Control | Bivalent control (0=disable, 1=enable)
TOP130 | main/Bivalent_Mode	 | Bivalent mode (0=Alternative, 1=Parallel, 2=Advanced Parallel)
TOP131 | main/Bivalent_Start_Temp		 | Bivalent start temperature
TOP132 | main/Bivalent_Advanced_Heat	 | Bivalent adv. par. heat control (disable/enable)
TOP133 | main/Bivalent_Advanced_DHW	 	 | Bivalent adv. par. DHW control (disable/enable)
TOP134 | main/Bivalent_Advanced_Start_Temp	 | Bivalent adv. par. heat start temp
TOP135 | main/Bivalent_Advanced_Stop_Temp	 | Bivalent adv. par. heat stop temp
TOP136 | main/Bivalent_Advanced_Start_Delay	 | Bivalent adv. par. heat start delay
TOP137 | main/Bivalent_Advanced_Stop_Delay	 | Bivalent adv. par. heat stop delay
TOP138 | main/Bivalent_Advanced_DHW_Delay	 | Bivalent adv. par. DHW delay
TOP139 | main/Heating_Control | Heating Control
TOP140 | main/Smart_DHW | Smart DHW
TOP141 | main/Quiet_Mode_Priority | Quiet Mode Priority (0=sound, 1=capacity)
TOP142 | main/Expansion_Valve | Expansion Valve (Steps)

All Topics related with state can have also value -1 - unknown - but only in abnormal situations.

## Option PCB Topics:
The following topics are actions from the heatpump to the optional pcb (for example, start pump on zone 2). This is only available if you have enable optional pcb emulation.
These values are not visible if you have the real optional pcb installed.

ID | Topic | Response/Description
:--- | --- | ---
OPT0 | optional/Z1_Water_Pump | Z1 water pump action request (0=off, 1=on)
OPT1 | optional/Z1_Mixing_Valve | Z1 mixing valve action request (0=off, 1=decrease, 2=increase)
OPT2 | optional/Z2_Water_Pump | Z2 water pump action request (0=off, 1=on)
OPT3 | optional/Z2_Mixing_Valve | Z2 mixing valve action request (0=off, 1=decrease, 2=increase)
OPT4 | optional/Pool_Water_Pump | Pool water pump action request (0=off, 1=on)
OPT5 | optional/Solar_Water_Pump | Solar water pump action request (0=off, 1=on)
OPT6 | optional/Alarm_State | Alarm state (0=off, 1=on)

## Command Topics:

These topics are commands through heishamon to set modes and values on the heatpump and they can be set by either using:

MQTT: send mqtt message to base_topic/commands/SetTopic (e.g.: panasonic_heat_pump/commands/SetHeatpump)

HTTP REST API: http://x.x.x.x/command?[topic]=[value]&[topic]=[value] (e.g.: http://x.x.x.x/command?SetQuietMode=3&SetZ1HeatRequestTemperature=21_

 ID |Topic | Description | Value/Range
:--- | :--- | --- | ---
SET1  | SetHeatpump | Set heatpump on or off | 0=off, 1=on
SET2  | SetHolidayMode | Set holiday mode on or off | 0=off, 1=on
SET3  | SetQuietMode | Set quiet mode level | 0=off, 1=less power, 2=even less power, 3=least power
SET4  | SetPowerfulMode | Set powerful mode run time in minutes | 0=off, 1=30, 2=60 or 3=90
SET5  | SetZ1HeatRequestTemperature | Set Z1 heat shift or direct heat temperature | -5 to 5 or 20 to max
SET6  | SetZ1CoolRequestTemperature | Set Z1 cool shift or direct cool temperature | -5 to 5 or 20 to max
SET7  | SetZ2HeatRequestTemperature | Set Z2 heat shift or direct heat temperature | -5 to 5 or 20 to max
SET8  | SetZ2CoolRequestTemperature | Set Z2 cool shift or direct cool temperature | -5 to 5 or 20 to max
SET9  | SetOperationMode | Sets operating mode | 0=Heat only, 1=Cool only, 2=Auto, 3=DHW only, 4=Heat+DHW, 5=Cool+DHW, 6=Auto+DHW
SET10 | SetForceDHW | Forces DHW (Operating mode should be set first to inlcude DWH mode (operation mode 3,4,5 or 6) to be effective. Please look at SET9 )  | 0, 1
SET11 | SetDHWTemp | Set DHW target temperature | 40 - 75
SET12 | SetForceDefrost | Forces defrost routine | 0, 1
SET13 | SetForceSterilization | Forces DHW sterilization routine | 0, 1
SET14 | SetPump | Set Water Pump to service mode, max speed | 0, 1
SET15 | SetMaxPumpDuty | Set max Water Pump duty in service menu | decimal value translate to hexadecimal in service menu <br/>64 to 254
SET16 | SetCurves | Set zones heat/cool curves | JSON document (see below)
SET17 | SetZones | Set zones to active | 0 = zone 1 active, 1 = zone2 active, 2 = zone1 and zone2 active
SET18 | SetFloorHeatDelta | Set floor heating delta in Kelvin | 1-15
SET19 | SetFloorCoolDelta | Set floor cooling delta in Kelvin | 1-15
SET20 | SetDHWHeatDelta | Set DHW heating delta in Kelvin | -12 to -2 (negative value)
SET21 | SetHeaterDelayTime | Set heater start delay time (only J-series) | in minutes
SET22 | SetHeaterStartDelta | Set heater start delta T (only J-series) | in kelvin
SET23 | SetHeaterStopDelta | Set heater stop delta T (only J-series) | in kelvin
SET24 | SetMainSchedule | Set weekly schedule | 0=off, 1=on
SET25 | SetAltExternalSensor | Set the alternative external outdoor sensor | 0=disabled, 1=enabled
SET26 | SetExternalPadHeater | Set the external pad heater | 0=disabled, 1=type-A, 2=type-B
SET27 | SetBufferDelta | Set buffer tank delta | 0 - 10
SET28 | SetBuffer | Set buffer installed | 0=not installed, 1=installed
SET29 | SetHeatingOffOutdoorTemp | Set Outdoor Temperature to stop heating | 5 to 35
SET30 | SetExternalControl | Set external control switch | 0=disabled, 1=enabled
SET31 | SetExternalError | Set external error signal| 0=disabled, 1=enabled
SET32 | SetExternalCompressorControl | Set external compressor control switch | 0=disabled, 1=enabled
SET33 | SetExternalHeatCoolControl | Set external heat/cool control switch | 0=disabled, 1=enabled
SET34 | SetBivalentControl | Set bivalent control switch | 0=disabled, 1=enabled
SET35 | SetBivalentMode | Set bivalent mode | 0=alternative, 1=parallel, 2=advanced parallel
SET36 | SetBivalentStartTemp | Set bivalent start temp | -15 to 35
SET37 | SetBivalentAPStartTemp | Set bivalent adv. par. start temp | -15 to 35
SET38 | SetBivalentAPStopTemp | Set bivalent adv. par. stop temp | -15 to 35
SET39 | SetHeatingControl | Set heating control | 0=comfort, 1=efficiency
SET40 | SetSmartDHW | Set SmartDHW | 0=variable, 1=standard
SET41 | SetQuietModePriority | Set Quiet Mode Priority | 0=sound, 1=capacity
SET42 | SetPumpFlowrateMode | Set Pump Flowrate Mode | 0=deltaT, 1=max. duty

*If you operate your heatpump in water mode with direct temperature setup: topics ending xxxRequestTemperature will set the absolute target temperature.*

*But if you operature your heatpump in internal/external thermostat or thermistor mode with direct temperature, you can not use these SET15 and other topics to set the direct temperature. The direct temperature in that modes is stored in the high target compenstation curve value. So to change the requested direct temperature in those modes, use the SET16 to set this value. Maybe this weird behaviour is different for newer heatpump types. So if your heatpump works different, please feel free to updates this note in github.*

*To send Heating/Cooling Curves on topic SET16 you need to send a flattened JSON document. For example:*

```{"zone1":{"heat":{"target":{"high":35,"low":25},"outside":{"high":15,"low":-15}},"cool":{"target":{"high":35,"low":25},"outside":{"high":15,"low":-15}}},"zone2":{"heat":{"target":{"high":35,"low":25},"outside":{"high":15,"low":-15}},"cool":{"target":{"high":35,"low":25},"outside":{"high":15,"low":-15}}}}```

*The structure of the JSON document:*

```json
{
	"zone1": {
		"heat": {
			"target": {
				"high": 35,
				"low": 25
			},
			"outside": {
				"high": 15,
				"low": -15
			}
		},
		"cool": {
			"target": {
				"high": 35,
				"low": 25
			},
			"outside": {
				"high": 15,
				"low": -15
			}
		}
	},
	"zone2": {
		"heat": {
			"target": {
				"high": 35,
				"low": 25
			},
			"outside": {
				"high": 15,
				"low": -15
			}
		},
		"cool": {
			"target": {
				"high": 35,
				"low": 25
			},
			"outside": {
				"high": 15,
				"low": -15
			}
		}
	}
}
```
*But you are free to set only the value you need, for example:*

```json
{
  "zone1": {
    "heat": {
      "outside": {
        "low": -15
      }
    }
  }
}
```

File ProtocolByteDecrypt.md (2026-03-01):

## Protocol byte decrypt info:

|  Topic# | Byte# | Possible Value | Value decrypt | Value Description |
| :---- | ---- | ---- | ----- | ----:|
| | 00 | 71 | | Header  |
| | 01 | c8 | Data length ( Packet length = Data length + 3 )  |  Header |
| | 02 | 01| | Header  |
| | 03 | 10 | | Header |
|  TOP0+TOP2 | 04 | 56 | Force DHW status 56=off,96=on, 55 = heat pump off, 56= heat pump on, Service Setup: Water pump on=65, Air Purge=75, Pump Down=F0?| Force dhw, Heat pump on/off, Service setup (Water Flow, Air Purge , Pump Down) |
|  TOP19+TOP13+TOP68 | 05 | 55 | Holiday mode off/on (bit3and4), weekly shedule off/on (bit 1and2) force heater off/on (bit5and6) Dry Concrete off/on (bit7and8) | Holiday mode, Sheduler status, force heater state , Dry Concrete |
|  TOP94+TOP4 | 06 | 62 | 1st Bit = Zone2<br/> 2nd Bit = Zone1<br/>3rd & 4th bit = b01 DHW off ,b10 DHW on<br/> 5th ,6th,7th & 8th bit = b0001 - only DHW , b0010 - Heat , b0011 - Cool , b1001 - Auto(Heat) , b1010 - Auto(Cool) | Zone on/off <br/>Mode status |
|  TOP18+TOP17 | 07 | 49 | Left 5 bits = quiet level (0b01001 = Off, 0b01010 = level 1, 0b01011 = level 2, 0b01100 - level 3, 0b10001 = scheduled) last 3 bits is powermode level (0b001= Off, 0b010 - power mode 30min, 0b011 -60min, 0b100-90 min) | Quiet Mode status + Powerful mode status |
|  TOP | 08 | 00 | | 0 byte |
|  TOP58+TOP59 | 09 | 05 | 3rd & 4th bit = b01 Standard, b10 - DHW Standard/Variable (J-series only)<br/>5th & 6th bit = b01 DHW heater off, b10 - DHW heater on<br/>7rd & 8th bit = b01 Water heater off, b10 - Water heater on | DHW capacity (J-series only)<br/>Heaters enable allowed status|
|  TOP | 10 | 00 | | 0 byte |
|  TOP141 | 11 | 00 | 3rd & 4th bit = b01 - Sound , b10 - Capacity <br/> 7th & 8th bit = b01 - DHW Top sensor , b10 - DHW Center Sensor | Quiet Mode Priority (K/L series) <br/> Only All-In-One |
|  TOP | 12 | 00 | | 0 byte |
|  TOP | 13 | 00 | | 0 byte |
|  TOP | 14 | 00 | | 0 byte |
|  TOP | 15 | 00 | | 0 byte |
|  TOP | 16 | 00 | | 0 byte |
|  TOP | 17 | 00 | | 0 byte |
|  TOP | 18 | 00 | | 0 byte |
|  TOP | 19 | 00 | | 0 byte |
|  TOP107/108/109/110 | 20 | 19 | 1st Bit = b0 Water , b1 Glycol<br/>3rd & 4th bit = b01 Alternative Sensor Off ,b10 Alternative Sensor On<br/>5rd & 6th bit = b01 Antifreezing Off ,b10 Antifreezing on<br/>7rd & 8th bit = b01 Optional PCB Off ,b10 Optional PCB on<br/>| Circulation liquid<br/> ,Alternative outdoor temp sensor<br/> Anti freezing<br/> Optional PCB |
|  TOP | 21 | 15 |  (hex) 15 - One  Zone and Z1 as room , 19 - One Zone and Z1 as pool, 16 - Two Zones and Z2 as room, 26 - Two Zones ,Z2 as pool| No. of Zones and Zone Destination |
|  TOP111+TOP112 | 22 | 11 |First digit -Z2 ,Second digit Z1 (hex) 1 - water temperature,2 - External Thermostat, 3 - Internal Thermostat, , 4 - Thermistor  | Zone & sensor settings ( system setup - Installer ) | 
| TOP119/120/121/122 | 23 | 55 | 1st/2nd bit = external compressor control, 3rd/4th bit = external error signal, 5th/6h bit = heat/cool-switch, 7th/8th bit = external control switch | External control, heat/cool switch, error signal and External compressor control switch (menu settings)|
|  TOP140+TOP99+TOP100+TOP101 | 24 | 16 | 1st & 2nd bit Smart DHW (L series) (b01=Variable, b10=Standard) <br/> 3rd & 4th bit = solar buffer (0b01=no solar, 0b10=solar buffer, 0b11=solar dhw) <br/> 5th & 6th bit = buffer installed <br/> 7th & 8th bit = DHW installed |
|  TOP114 | 25 | 5e | 1st & 2nd bit = 10 <br/> 3rd & 4th bit = b01 no Pad Heater, b10 - Type A, b11 Type B <br/> 5th & 6th bit = b01 - Internal Heater 3kW, b10 - 6kW, b11 - 9kW <br/> 7th & 8th bit = b01 DHW Internal Heater , b10 - DHW External Heater | External Pad Heater <br/> Power of internal heater <br/> DHW heater Internal/External |
|  TOP129/130/13/132 | 26 | 55 | (hex) Bivalent control, mode and ap settings. | Bivalent settings |
|  TOP | 27 | 05 | SG Ready Control on/off (bit5and6) ,Demand Control on/off (bit7and8)  | SG Ready Control, Demand Control |
|  TOP76+TOP81 | 28 | 09 | (hex) 09 - Compensation curve heat and direct cool, 05 - both compensation curves , 0a - direct heat and direct cool, 06 - heat direct, cool compensation curve  | Operation Setup -Installer -water temperature heating on status and cooling |
|  TOP106 | 29 | 00 | 3rd & 4th bit = b01 - deltaT , b10 - Max. Duty | Pump flowrate (J/K/L series) |
|  TOP139 | 30 | 00 |  5th & 6th bit = Heating Control (b01=Comfort, b10=Efficiency) <br/> 7th & 8th bit = DHW Defrost (b01=No, b10=Yes) | Heating Control (K/L series) <br/> DHW Defrost (K/L series) |
|  TOP | 31 | 00 | | 0 byte |
|  TOP | 32 | 00 | | 0 byte |
|  TOP | 33 | 00 | | 0 byte |
|  TOP | 34 | 00 | | 0 byte |
|  TOP | 35 | 00 | | 0 byte |
|  TOP | 36 | 00 | | 0 byte |
|  TOP | 37 | 00 | | 0 byte |
|  TOP27 | 38 | 80 | Convert to DEC 128-128 = 0  | Zone 1 water shift set or direct mode value Temperature For Heat Mode [°C] |
|  TOP28 | 39 | 8f | Convert to DEC 143-128 = 15 in direct mode set temp or shift value  | Zone 1 water shift set Temperature For Cool Mode [°C] |
|  TOP34 | 40 | 80 | Convert to DEC 128-128 = 0  | Zone 2 water shift or direct mode set Temperature For Heat Mode [°C] |
|  TOP35 | 41 | 8a | Convert to DEC 138-128 = 10  | Zone 2 water shift or direct mode set Temperature For Cool Mode [°C] |
|  TOP9 | 42 | b2 | Convert to DEC 178-128 = 50  | DHW Target Temperature [°C] |
|  TOP45 | 43 | 71 | Convert to DEC 113-128 =-15 | Heat Shift for Holiday mode [°K]  |
|  TOP25 | 44 | 71 | Convert to DEC 113-128 =-15  | Heat Shift for DHW mode [°K] |
|  TOP95 | 45 | 97 | (hex) 96 = 97  | Maximum set pump speed |
|  TOP | 46 | 99 | Convert to DEC 153-128 = 25  | Dry concrete target temperature for actual stage [°C] |
|  TOP | 47 | 00 | | 0 byte |
|  TOP | 48 | 00 | | 0 byte |
|  TOP | 49 | 00 | | 0 byte |
|  TOP | 50 | 00 | | 0 byte |
|  TOP | 51 | 00 | | 0 byte |
|  TOP | 52 | 00 | | 0 byte |
|  TOP | 53 | 00 | | 0 byte |
|  TOP | 54 | 00 | | 0 byte |
|  TOP | 55 | 00 | | 0 byte |
|  TOP | 56 | 00 | | 0 byte |
|  TOP | 57 | 00 | | 0 byte |
|  TOP | 58 | 80 | Convert to DEC-128 | Delta T for Pool [°K] |
|  TOP113 | 59 | 85 | Convert to DEC-128  | Delta T for buffer tank [°K]|
|  TOP | 60 | 15 | Convert to DEC X-1 | Time set for external heaters 20min-3h, step 5min. |
|  TOP102 | 61 | 8a | Convert to DEC-128  | Solar Connection Set delta T for tank ON (DHW or Buffer) |
|  TOP103 | 62 | 85 | Convert to DEC-128 | Solar Connection Set delta T for tank OFF (DHW or Buffer)| 
|  TOP104 | 63 | 85 | Convert to DEC-128 | Set Antifreeze for solar |
|  TOP105 | 64 | d0 | Convert to DEC-128 | Set Hi limit for solar |
|  TOP131 | 65 | 7b | Convert to DEC-128  | Outdoor Temperature to turn on Bivalent device -15-35[°C]|
|  TOP134 | 66 | 78 | Convert to DEC-128  | Control pattern in Bivalent set temperature source to start the bivalent heat source |
|  TOP135 | 67 | 1f | Convert to DEC X-1  | Bivalent Delay timer to start the bivalent heat source |
|  TOP136 | 68 | 7e | Convert to DEC-128  | Control pattern in Bivalent set temperature source to stop the bivalent heat source |
|  TOP137 | 69 | 1f | Convert to DEC X-1  | Bivalent Delay timer to stop the bivalent heat source |
|  TOP138 | 70 | 1f | Convert to DEC X-1  | Bivalent Control pattern for DHW delay timer to start the bivalent source  |
|  TOP | 71 | 79 | Convert to DEC X-1  |SG Setting 1 Heating Capacity  |
|  TOP | 72 | 79 | Convert to DEC X-1  |SG Setting 1 DHW Capacity  |
|  TOP | 73 | 8d | Convert to DEC X-1  |SG Setting 2 Heating Capacity  |
|  TOP | 74 | 8d | Convert to DEC X-1  |SG Setting 2 DHW Capacity  |
|  TOP29 | 75 | 9e | Convert to DEC 158-128 =30 | Z1 Heating Curve Outlet Water Temperature Highest Set [°C] |
|  TOP30 | 76 | 96 | Convert to DEC 150-128 =22 | Z1 Heating Curve Outlet Water Temperature Lowest Set [°C] |
|  TOP32 | 77 | 71 | Convert to DEC 113-128 =-15 | Z1 Heating Curve Outside Temperature Lowest Set [°C] |
|  TOP31 | 78 | 8f | Convert to DEC 143-128 =15  | Z1 Heating Curve Outside Temperature Highest Set [°C] |
|  TOP82 | 79 | b7 | Convert to DEC 183-128 =55  | Z2 Heating Curve Outlet Water Temperature Highest Set [°C] |
|  TOP84 | 80 | a3 | Convert to DEC-128 | Z2 Heating Curve Outlet Water Temperature Lowest Set [°C] |
|  TOP83 | 81 | 7b | Convert to DEC-128 | Z2 Heating Curve Outside Temperature Lowest Set [°C] |
|  TOP85 | 82 | 8f | Convert to DEC-128 | Z2 Heating Curve Outside Temperature Highest Set [°C] |
|  TOP77 | 83 | 8e | Convert to DEC-128  | Outdoor Temperature to stop heating 5-35 [°C] |
|  TOP23 | 84 | 80 | Convert to DEC 133-128 =5 | Floor heating set Delta [°K] |
|  TOP78 | 85 | 80 | Convert to DEC 128-128=0 | Outdoor temperature for heater ON [°C]  |
|  TOP72 | 86 | 8f | Convert to DEC-128 | Z1 Cooling Curve Outlet Water Temperature Highest Set [°C]|
|  TOP73 | 87 | 8a | Convert to DEC-128 | Z1 Cooling Curve Outlet Water Temperature Lowest Set [°C]|
|  TOP75 | 88 | 94 | Convert to DEC-128 | Z1 Cooling Curve Outside Temperature Lowest Set [°C] |
|  TOP74 | 89 | 9e | Convert to DEC-128 | Z1 Cooling Curve Outside Temperature Highest Set [°C] |
|  TOP86 | 90 | 8a | Convert to DEC-128 | Z2 Cooling Curve Outlet Water Temperature Highest Set [°C]|
|  TOP87 | 91 | 8a | Convert to DEC-128 | Z2 Cooling Curve Outlet Water Temperature Lowest Set [°C]|
|  TOP89 | 92 | 94 | Convert to DEC-128 | Z2 Cooling Curve Outside Temperature Lowest Set [°C] |
|  TOP88 | 93 | 9e | Convert to DEC-128 | Z2 Cooling Curve Outside Temperature Highest Set [°C] |
|  TOP24 | 94 | 82 | Convert to DEC 130-128 =2  | Floor cooling set delta [°C] |
|  TOP79 | 95 |  90  | Convert to DEC 144-128=16|  Outdoor temperature for (heat to cool) [°C]  |
|  TOP80 | 96 | 8b | Convert to DEC 139-128=11|  Outdoor temperature for (cool to heat) [°C] |
|  TOP | 97 | 05 | Donvert to DEC (X-1) x 30 | DHW settings - Room operation max time [min] |
|  TOP | 98 | 65 | Convert to DEC 101-1=100 | DHW heat up time (max) [min] |
|  TOP22 | 99 | 78 | Convert to DEC 120-128=-8 | DHW Delta for re-heat  [°K] |
|  TOP70 | 100 | c1 |  Convert to DEC 193-128=65  | Sterilization boiling temperature [°C] |
|  TOP71 | 101 | 0b |  Convert to DEC 11 - 1 = 10 | Sterilization max operation time [min] |
|  TOP | 102 | 00 | | 0 byte |
|  TOP | 103 | 00 | | 0 byte |
|  TOP96 | 104 | 00 | Convert to DEC X-1  | Delay timer to start internal heater (J/K/L series) |
|  TOP97 | 105 | 00 | Convert to DEC-128 | Delta to start internal heater for room heating (J/K/L series) |  
|  TOP98 | 106 | 00 | Convert to DEC-128 | Delta to stop internal heater for room heating (J/K/L series) |
|  TOP | 107 | 00 | | 0 byte |
|  TOP | 108 | 00 | | 0 byte |
|  TOP | 109 | 00 | | 0 byte |
|  TOP | 110 | 55 | 1st & 2nd bit - Quiet mode <br/> 3rd&4th bit -  Powerful <br/> 5th & 6th bit - Heat-Cool SW b10 - Cool <br/> 7th & 8th bit - External SW b10-Open  | Actual/Real states of <br/> Quiet <br/> Powerful <br/> Heat-Cool SW <br/> External SW |
|  TOP20+TOP26 | 111 | 56 |  right 2 bits: 0b10=DHW 0b01=Room 3-Way Valve. Next 2 bits (from right) is defrosting state (0b01 = defrosting not active, 0b10 = defrosting active) | 3 way valve + Defrost status |
|  TOP60+TOP61 | 112 | 55 | 1st & 2nd bit - Boiler Contact  <br/> 5th & 6th bit - External Heater <br/> 7th & 8th bit - Internal Heater (room or DHW)  <br/> ( b01 - OFF, b10 - ON )| Real status of Bivalent Boiler contact and Heaters relays (Line under icons)  |
|  TOP44 | 113 | 21 | Hex B1 - F type error, A1 - H type error. After H error reset value 21, F error reset 31  | Error code type |
|  TOP44 | 114 | 53 | F45 error in HEX 56, calulation 45 treat as HEX and convert to DEC 69 + 17 = 86 (Hex 56) | Error code number |
|  TOP | 115 | 15 | | ? |
|  TOP123/124/125/126 | 116 | 5a | 1st & 2nd bit Zone 2 Pump ( b01 - OFF, b10 - ON ) ,  3rd & 4th bit = Zone 1 Pump ( b01 - OFF, b10 - ON ), 5th & 6th bit = 2way Valve ( b01 - Cooling, b10 - Heating) , 7th & 8th bit = 3way Valve ( b01 - Room, b10 - Tank)  | Z1 & Z2 Pump 2way & 3wa Valve staus |
|  TOP69 | 117 | 05 | Sterilization on/off (bit5and6)  , Z2 active (bit7) ,Z1 active (bit8)| Sterilization status Zone active information (look byte #6) |
|  TOP | 118 | 12 | | fractional info for TOP5 and TOP6 values |
|  TOP | 119 | 12 | | ? |
|  TOP | 120 | 19 | 3rd & 4th bit = b01 Heater Inactive ,b10 Heater Active<br/> 5th & 6th bit = b01 Cooling Inactive ,b10 Cooling Active<br/> | Custom menu settings<br/>Back-up Heater<br/>Cool Mode |
|  TOP | 121 | 00 | | 0 byte |
|  TOP | 122 | 00 | | 0 byte |
|  TOP | 123 | 00 | | 0 byte |
|  TOP | 124 | 00 | | 0 byte |
|  TOP | 125 | 00 | Convert to (DEC-1)/50  | Water Pressure [bar] (K/L series) |
|  TOP | 126 | 00 | Convert to DEC-128 | Water Inlet 2 Temperature [°C] (L series) |
|  TOP | 127 | 00 | Convert to DEC-128 | Economizer Outlet Temperature [°C] (K/L series) |
|  TOP | 128 | 00 | | 0 byte |
|  TOP92 | 129 | e2 | look in HeatPumpType.md  | Heat pump model |
|  TOP92 | 130 | ce | look in HeatPumpType.md  | Heat pump model |
|  TOP92 | 131 | 0d | look in HeatPumpType.md  | Heat pump model |
|  TOP92 | 132 | 71 |  look in HeatPumpType.md | Heat pump model |
|  TOP92 | 133 | 81 | look in HeatPumpType.md  | Heat pump model |
|  TOP92 | 134 | 72 | look in HeatPumpType.md  | Heat pump model |
|  TOP92 | 135 | ce | look in HeatPumpType.md  | Heat pump model |
|  TOP92 | 136 | 0c | look in HeatPumpType.md  | Heat pump model |
|  TOP92 | 137 | 92 | look in HeatPumpType.md  | Heat pump model |
|  TOP92 | 138 | 81 | look in HeatPumpType.md  | Heat pump model |
|  TOP56 | 139 | b0 |  Convert to DEC-128 | Zone1: Actual (Zone 1) Temperature [°C] |
|  TOP57 | 140 | 00 |  Convert to DEC-128 |  Zone2: Actual (Zone 2) Temperature [°C] |
|  TOP10 | 141 | aa |  Convert to DEC-128 | Actual DHW Temperature [°C] |
|  TOP14 | 142 | 7c |  Convert to DEC-128 | Actual Outdoor Temperature [°C] |
|  TOP5 | 143 | ab |  Convert to DEC-128 | Inlet Water Temperature [°C] |
|  TOP6 | 144 | b0 |  Convert to DEC-128 | Outlet Water Temperature [°C] |
|  TOP36 | 145 | 32 |  Convert to DEC-128 | Zone1: Water Temperature [°C] |
|  TOP37 | 146 | 32 |  Convert to DEC-128 | Zone2: Water Temperature [°C] |
|  TOP42 | 147 | 9c |  Convert to DEC-128 | Zone1: Water Temperature (Target) [°C] |
|  TOP43 | 148 | b6 |  Convert to DEC-128 | Zone2: Water Temperature (Target) [°C]  |
|  TOP46 | 149 | 32 |  Convert to DEC-128 | Buffer: Water Temperature [°C] |
|  TOP47 | 150 | 32 |  Convert to DEC-128 | Solar: Water Temperature [°C]  |
|  TOP48 | 151 | 32 |  Convert to DEC-128| Pool: Water Temperature [°C] |
|  TOP | 152 | 80 | Convert to DEC 128-128 = 0  | Water shift set or direct mode value Temperature For Heat Mode [°C] including Delta T for Buffer |
|  TOP7 | 153 | b7 |  Convert to DEC-128 | Outlet Water Temperature (Target) [°C] |
|  TOP49 | 154 | af |  Convert to DEC-128 | Outlet 2 heat exchanger water temperature [°C] |
|  TOP50 | 155 | cd |  Convert to DEC-128 | Discharge Temperature [°C] |
|  TOP33 | 156 | 9a |  Convert to DEC-128 | RC-1:Room Thermostat Internal Sensor Temperature [°C] |
|  TOP51 | 157 | ac |  Convert to DEC-128 | Indoor Piping Temperature [°C] |
|  TOP21 | 158 | 79 |  Convert to DEC-128 | Outdoor Piping Temperature [°C] |
|  TOP52 | 159 | 80 |  Convert to DEC-128 | Defrost Temperature [°C] |
|  TOP53 | 160 | 77 |  Convert to DEC-128 | Eva Outlet Temperature [°C] |
|  TOP54 | 161 | 80 |  Convert to DEC-128 | Bypass Outlet Temperature [°C] |
|  TOP55 | 162 | ff |  Convert to DEC-128 | Ipm Temperature [°C]  |
|  TOP64 | 163 | 91 |  Convert to DEC (x-1)/5 | High Pressure [kgf/cm2] |
|  TOP66 | 164 | 01 |  Convert to DEC (x-1)/5 | Low Pressure [kgf/cm2] |
|  TOP67 | 165 | 29 |  Convertto DEC (X-1)/5 | Outdoor Current [A] |
|  TOP8 | 166 | 59 | Convert to DEC x-1  | Compressor Frequency [Hz] |
|  TOP | 167 | 00 | | 0 byte |
|  TOP | 168 | 00 | | 0 byte |
|  TOP1 | 169 | 3b | Convert to DEC (X -1)/256 | 2nd Value for Pump Flow Rate [L/Min]  |
|  TOP1 | 170 | 0b | Convert to DEC | 1st Value for Pump Flow Rate [L/Min] |
|  TOP65 | 171 | 1c | Convert to DEC (X-1) X 50 | Pump Speed [R/Min] |
|  TOP93 | 172 | 51 | Convert to DEC X-1 | Pump Duty [duty] |
|  TOP62 | 173 | 59 | Convert to DEC (X-1) X10  | Fan 1 Motor Speed [R/Min] |
|  TOP63 | 174 | 01 | Convert to DEC (X-1) X10  | Fan 2 Motor Speed [R/Min] |
|  TOP142 | 175 | 36 | Convert to DEC -1  | Expansion Valve [Steps] |
|  TOP | 176 | 79 | Convert to DEC -1  | ?Possible ByPass valve |
|  TOP127 | 177 | 01 | Convert to DEC -1  | 2 Zone mixing valve PID |
|  TOP128 | 178 | 01 | Convert to DEC -1  | 1 Zone mixing valve PID |
|  TOP12 | 179 | c3 | combine both bytes (180 byte) 08 (179 byte) be = 08be= 2238(DEC) - 1 = 2237  | number of operations |
|  TOP12 | 180 | 02 |  look at 179 | number of operations |
|  TOP | 181 | 00 | | 0 byte |
|  TOP11 | 182 | dd | combine both bytes (183) 0b  (182) 25 = 2853 - 1 = 2852  | Operating time in h |
|  TOP11 | 183 | 02 | look at 182  | Operating time in h |
|  TOP | 184 | 00 | | 0 byte |
|  TOP90 | 185 | 05 | combine both bytes (186) 00  (185) 0005 = 5 - 1 = 4  | Room Heater operation time in h |
|  TOP90 | 186 | 00 |  look at 185 | Room Heater operation time in h |
|  TOP | 187 | 00 | | 0 byte |
|  TOP91 | 188 | 01 | combine both bytes (189) 00  (188) 0001 = 1 - 1 = 0 | DHW Heater operation time in h  |
|  TOP91 | 189 | 00 | look at 188 | DHW Heater operation time in h |
|  TOP | 190 | 00 | | 0 byte |
|  TOP | 191 | 06 | Convert to DEC X-1  | Heat pump power in Kw |
|  TOP | 192 | 01 | (hex) simple model=1, T-CAP=2  | ? Possible Heat pump indicator for T-CAP  |
|  TOP16 | 193 | 01 | Convert to DEC (x-1) / 5 | Power Consumption for Heat in [kw]  |
|  TOP15 | 194 | 01 | Convert to DEC (x-1) / 5 | Power Generation for Heat in [kw] |
|  TOP38 | 195 | 01 | Convert to DEC (x-1) / 5 | Power Consumption for Cool in [kw] |
|  TOP39 | 196 | 01 | Convert to DEC (x-1) / 5 | Power Generation for Cool in [kw] |
|  TOP40 | 197 | 0a | Convert to DEC (x-1) / 5 | Power Consumption for DHW in [kw] |
|  TOP41 | 198 | 14 | Convert to DEC (x-1) / 5 | Power Generation for DHW in [kw] |
|  TOP | 199 | 00 | | If value equal or greather '=>' then 0x03 CZ-TAW1 starts asking for <a href="https://github.com/Egyras/HeishaMon/blob/master/ProtocolByteDecrypt-extra.md">extra query</a> |
|  TOP | 200 | 00 |  Convert to DEC-128 | RC-2:Room Thermostat Internal Sensor Temperature [°C] (K/L series) |
|  TOP | 201 | 00 | | byte 0 |
|  TOP | 202 | 79 |  CHECKSUM |  |

To get decimal values you must convert from hexadecimal and do some calulation depending on value. Most of them need just -128(DEC). \
As example 43 byte value to get DHW set temperature b1 (HEX) = 177(DEC) - 128 = 49 C  \s
Panasonic query, answer and commands are using 8-bit Checksum to verify serial data ( sum(all bytes) & 0xFF == 0 ). Last byte is checksum value.

## Query Examples:

Panasonic query:

`71 6c 01 10 00 00 00 00 00 00 00 00 00 00 00 00
00 00 00 00 00 00 00 00 00 00 00 00 00 00 00 00
00 00 00 00 00 00 00 00 00 00 00 00 00 00 00 00
00 00 00 00 00 00 00 00 00 00 00 00 00 00 00 00
00 00 00 00 00 00 00 00 00 00 00 00 00 00 00 00
00 00 00 00 00 00 00 00 00 00 00 00 00 00 00 00
00 00 00 00 00 00 00 00 00 00 00 00 00 00 12`

Panasonic answer example:

`71 c8 01 10 56 55 62 49 00 05 00 00 00 00 00 00
00 00 00 00 19 15 11 55 16 5e 55 05 09 00 00 00
00 00 00 00 00 00 80 8f 80 8a b2 71 71 97 99 00
00 00 00 00 00 00 00 00 00 00 80 85 15 8a 85 85
d0 7b 78 1f 7e 1f 1f 79 79 8d 8d 9e 96 71 8f b7
a3 7b 8f 8e 85 80 8f 8a 94 9e 8a 8a 94 9e 82 90
8b 05 65 78 c1 0b 00 00 00 00 00 00 00 00 55 56
55 21 53 15 5a 05 12 12 19 00 00 00 00 00 00 00
00 e2 ce 0d 71 81 72 ce 0c 92 81 b0 00 aa 7c ab
b0 32 32 9c b6 32 32 32 80 b7 af cd 9a ac 79 80
77 80 ff 91 01 29 59 00 00 3b 0b 1c 51 59 01 36
79 01 01 c3 02 00 dd 02 00 05 00 00 01 00 00 06
01 01 01 01 01 0a 14 00 00 00 77`

Quiet mode 1

`f1 6c 01 10 00 00 00 10 00 00 00 00 00 00 00 00
00 00 00 00 00 00 00 00 00 00 00 00 00 00 00 00
00 00 00 00 00 00 00 00 00 00 00 00 00 00 00 00
00 00 00 00 00 00 00 00 00 00 00 00 00 00 00 00
00 00 00 00 00 00 00 00 00 00 00 00 00 00 00 00
00 00 00 00 00 00 00 00 00 00 00 00 00 00 00 00
00 00 00 00 00 00 00 00 00 00 00 00 00 00 82`

Quiet mode 2

`f1 6c 01 10 00 00 00 18 00 00 00 00 00 00 00 00
00 00 00 00 00 00 00 00 00 00 00 00 00 00 00 00
00 00 00 00 00 00 00 00 00 00 00 00 00 00 00 00
00 00 00 00 00 00 00 00 00 00 00 00 00 00 00 00
00 00 00 00 00 00 00 00 00 00 00 00 00 00 00 00
00 00 00 00 00 00 00 00 00 00 00 00 00 00 00 00
00 00 00 00 00 00 00 00 00 00 00 00 00 00 7a`

Quiet mode 3

`f1 6c 01 10 00 00 00 20 00 00 00 00 00 00 00 00
00 00 00 00 00 00 00 00 00 00 00 00 00 00 00 00
00 00 00 00 00 00 00 00 00 00 00 00 00 00 00 00
00 00 00 00 00 00 00 00 00 00 00 00 00 00 00 00
00 00 00 00 00 00 00 00 00 00 00 00 00 00 00 00
00 00 00 00 00 00 00 00 00 00 00 00 00 00 00 00
00 00 00 00 00 00 00 00 00 00 00 00 00 00 72`

Quiet off

`f1 6c 01 10 00 00 00 08 00 00 00 00 00 00 00 00
00 00 00 00 00 00 00 00 00 00 00 00 00 00 00 00
00 00 00 00 00 00 00 00 00 00 00 00 00 00 00 00
00 00 00 00 00 00 00 00 00 00 00 00 00 00 00 00
00 00 00 00 00 00 00 00 00 00 00 00 00 00 00 00
00 00 00 00 00 00 00 00 00 00 00 00 00 00 00 00
00 00 00 00 00 00 00 00 00 00 00 00 00 00 8a`

Set -2C

`f1 6c 01 10 00 00 00 00 00 00 00 00 00 00 00 00
00 00 00 00 00 00 00 00 00 00 00 00 00 00 00 00
00 00 00 00 00 00 7e 00 00 00 00 00 00 00 00 00
00 00 00 00 00 00 00 00 00 00 00 00 00 00 00 00
00 00 00 00 00 00 00 00 00 00 00 00 00 00 00 00
00 00 00 00 00 00 00 00 00 00 00 00 00 00 00 00
00 00 00 00 00 00 00 00 00 00 00 00 00 00 14`

set -1C

`f1 6c 01 10 00 00 00 00 00 00 00 00 00 00 00 00
00 00 00 00 00 00 00 00 00 00 00 00 00 00 00 00
00 00 00 00 00 00 7f 00 00 00 00 00 00 00 00 00
00 00 00 00 00 00 00 00 00 00 00 00 00 00 00 00
00 00 00 00 00 00 00 00 00 00 00 00 00 00 00 00
00 00 00 00 00 00 00 00 00 00 00 00 00 00 00 00
00 00 00 00 00 00 00 00 00 00 00 00 00 00 13`

Set 0C

`f1 6c 01 10 00 00 00 00 00 00 00 00 00 00 00 00
00 00 00 00 00 00 00 00 00 00 00 00 00 00 00 00
00 00 00 00 00 00 80 00 00 00 00 00 00 00 00 00
00 00 00 00 00 00 00 00 00 00 00 00 00 00 00 00
00 00 00 00 00 00 00 00 00 00 00 00 00 00 00 00
00 00 00 00 00 00 00 00 00 00 00 00 00 00 00 00
00 00 00 00 00 00 00 00 00 00 00 00 00 00 12`

set -3C

`f1 6c 01 10 00 00 00 00 00 00 00 00 00 00 00 00
00 00 00 00 00 00 00 00 00 00 00 00 00 00 00 00
00 00 00 00 00 00 7d 00 00 00 00 00 00 00 00 00
00 00 00 00 00 00 00 00 00 00 00 00 00 00 00 00
00 00 00 00 00 00 00 00 00 00 00 00 00 00 00 00
00 00 00 00 00 00 00 00 00 00 00 00 00 00 00 00
00 00 00 00 00 00 00 00 00 00 00 00 00 00 15`

set -4C

`f1 6c 01 10 00 00 00 00 00 00 00 00 00 00 00 00
00 00 00 00 00 00 00 00 00 00 00 00 00 00 00 00
00 00 00 00 00 00 7c 00 00 00 00 00 00 00 00 00
00 00 00 00 00 00 00 00 00 00 00 00 00 00 00 00
00 00 00 00 00 00 00 00 00 00 00 00 00 00 00 00
00 00 00 00 00 00 00 00 00 00 00 00 00 00 00 00
00 00 00 00 00 00 00 00 00 00 00 00 00 00 16`

Set -5C

`f1 6c 01 10 00 00 00 00 00 00 00 00 00 00 00 00
00 00 00 00 00 00 00 00 00 00 00 00 00 00 00 00
00 00 00 00 00 00 7b 00 00 00 00 00 00 00 00 00
00 00 00 00 00 00 00 00 00 00 00 00 00 00 00 00
00 00 00 00 00 00 00 00 00 00 00 00 00 00 00 00
00 00 00 00 00 00 00 00 00 00 00 00 00 00 00 00
00 00 00 00 00 00 00 00 00 00 00 00 00 00 17`

set +1C

`f1 6c 01 10 00 00 00 00 00 00 00 00 00 00 00 00
00 00 00 00 00 00 00 00 00 00 00 00 00 00 00 00
00 00 00 00 00 00 81 00 00 00 00 00 00 00 00 00
00 00 00 00 00 00 00 00 00 00 00 00 00 00 00 00
00 00 00 00 00 00 00 00 00 00 00 00 00 00 00 00
00 00 00 00 00 00 00 00 00 00 00 00 00 00 00 00
00 00 00 00 00 00 00 00 00 00 00 00 00 00 11`

set +2C

`f1 6c 01 10 00 00 00 00 00 00 00 00 00 00 00 00
00 00 00 00 00 00 00 00 00 00 00 00 00 00 00 00
00 00 00 00 00 00 82 00 00 00 00 00 00 00 00 00
00 00 00 00 00 00 00 00 00 00 00 00 00 00 00 00
00 00 00 00 00 00 00 00 00 00 00 00 00 00 00 00
00 00 00 00 00 00 00 00 00 00 00 00 00 00 00 00
00 00 00 00 00 00 00 00 00 00 00 00 00 00 10`

set +3C

`f1 6c 01 10 00 00 00 00 00 00 00 00 00 00 00 00
00 00 00 00 00 00 00 00 00 00 00 00 00 00 00 00
00 00 00 00 00 00 83 00 00 00 00 00 00 00 00 00
00 00 00 00 00 00 00 00 00 00 00 00 00 00 00 00
00 00 00 00 00 00 00 00 00 00 00 00 00 00 00 00
00 00 00 00 00 00 00 00 00 00 00 00 00 00 00 00
00 00 00 00 00 00 00 00 00 00 00 00 00 00 0f`

set +4C

`f1 6c 01 10 00 00 00 00 00 00 00 00 00 00 00 00
00 00 00 00 00 00 00 00 00 00 00 00 00 00 00 00
00 00 00 00 00 00 84 00 00 00 00 00 00 00 00 00
00 00 00 00 00 00 00 00 00 00 00 00 00 00 00 00
00 00 00 00 00 00 00 00 00 00 00 00 00 00 00 00
00 00 00 00 00 00 00 00 00 00 00 00 00 00 00 00
00 00 00 00 00 00 00 00 00 00 00 00 00 00 0e`

set +5C

`f1 6c 01 10 00 00 00 00 00 00 00 00 00 00 00 00
00 00 00 00 00 00 00 00 00 00 00 00 00 00 00 00
00 00 00 00 00 00 85 00 00 00 00 00 00 00 00 00
00 00 00 00 00 00 00 00 00 00 00 00 00 00 00 00
00 00 00 00 00 00 00 00 00 00 00 00 00 00 00 00
00 00 00 00 00 00 00 00 00 00 00 00 00 00 00 00
00 00 00 00 00 00 00 00 00 00 00 00 00 00 0d`

set DHW to 48C

`f1 6c 01 10 00 00 00 00 00 00 00 00 00 00 00 00
00 00 00 00 00 00 00 00 00 00 00 00 00 00 00 00
00 00 00 00 00 00 00 00 00 00 b0 00 00 00 00 00
00 00 00 00 00 00 00 00 00 00 00 00 00 00 00 00
00 00 00 00 00 00 00 00 00 00 00 00 00 00 00 00
00 00 00 00 00 00 00 00 00 00 00 00 00 00 00 00
00 00 00 00 00 00 00 00 00 00 00 00 00 00 e2`

set DHW to 47C

`f1 6c 01 10 00 00 00 00 00 00 00 00 00 00 00 00
00 00 00 00 00 00 00 00 00 00 00 00 00 00 00 00
00 00 00 00 00 00 00 00 00 00 af 00 00 00 00 00
00 00 00 00 00 00 00 00 00 00 00 00 00 00 00 00
00 00 00 00 00 00 00 00 00 00 00 00 00 00 00 00
00 00 00 00 00 00 00 00 00 00 00 00 00 00 00 00
00 00 00 00 00 00 00 00 00 00 00 00 00 00 e3`

set DHW to 49C

`f1 6c 01 10 00 00 00 00 00 00 00 00 00 00 00 00
00 00 00 00 00 00 00 00 00 00 00 00 00 00 00 00
00 00 00 00 00 00 00 00 00 00 b1 00 00 00 00 00
00 00 00 00 00 00 00 00 00 00 00 00 00 00 00 00
00 00 00 00 00 00 00 00 00 00 00 00 00 00 00 00
00 00 00 00 00 00 00 00 00 00 00 00 00 00 00 00
00 00 00 00 00 00 00 00 00 00 00 00 00 00 e1`

set DHW to 40C

`f1 6c 01 10 00 00 00 00 00 00 00 00 00 00 00 00
00 00 00 00 00 00 00 00 00 00 00 00 00 00 00 00
00 00 00 00 00 00 00 00 00 00 a8 00 00 00 00 00
00 00 00 00 00 00 00 00 00 00 00 00 00 00 00 00
00 00 00 00 00 00 00 00 00 00 00 00 00 00 00 00
00 00 00 00 00 00 00 00 00 00 00 00 00 00 00 00
00 00 00 00 00 00 00 00 00 00 00 00 00 00 ea`

set DHW to max 75C

`f1 6c 01 10 00 00 00 00 00 00 00 00 00 00 00 00
00 00 00 00 00 00 00 00 00 00 00 00 00 00 00 00
00 00 00 00 00 00 00 00 00 00 ca 00 00 00 00 00
00 00 00 00 00 00 00 00 00 00 00 00 00 00 00 00
00 00 00 00 00 00 00 00 00 00 00 00 00 00 00 00
00 00 00 00 00 00 00 00 00 00 00 00 00 00 00 00
00 00 00 00 00 00 00 00 00 00 00 00 00 00 c8`

heat on - DHW off

`f1 6c 01 10 02 00 52 00 00 00 00 00 00 00 00 00
00 00 00 00 00 00 00 00 00 00 00 00 00 00 00 00
00 00 00 00 00 00 00 00 00 00 00 00 00 00 00 00
00 00 00 00 00 00 00 00 00 00 00 00 00 00 00 00
00 00 00 00 00 00 00 00 00 00 00 00 00 00 00 00
00 00 00 00 00 00 00 00 00 00 00 00 00 00 00 00
00 00 00 00 00 00 00 00 00 00 00 00 00 00 3e`

heat off - DHW off (all off command)

`f1 6c 01 10 01 00 00 00 00 00 00 00 00 00 00 00
00 00 00 00 00 00 00 00 00 00 00 00 00 00 00 00
00 00 00 00 00 00 00 00 00 00 00 00 00 00 00 00
00 00 00 00 00 00 00 00 00 00 00 00 00 00 00 00
00 00 00 00 00 00 00 00 00 00 00 00 00 00 00 00
00 00 00 00 00 00 00 00 00 00 00 00 00 00 00 00
00 00 00 00 00 00 00 00 00 00 00 00 00 00 91`

heat off - DHW on

`f1 6c 01 10 02 00 21 00 00 00 00 00 00 00 00 00
00 00 00 00 00 00 00 00 00 00 00 00 00 00 00 00
00 00 00 00 00 00 00 00 00 00 00 00 00 00 00 00
00 00 00 00 00 00 00 00 00 00 00 00 00 00 00 00
00 00 00 00 00 00 00 00 00 00 00 00 00 00 00 00
00 00 00 00 00 00 00 00 00 00 00 00 00 00 00 00
00 00 00 00 00 00 00 00 00 00 00 00 00 00 6f`

heat on - DHW on

`f1 6c 01 10 02 00 62 00 00 00 00 00 00 00 00 00
00 00 00 00 00 00 00 00 00 00 00 00 00 00 00 00
00 00 00 00 00 00 00 00 00 00 00 00 00 00 00 00
00 00 00 00 00 00 00 00 00 00 00 00 00 00 00 00
00 00 00 00 00 00 00 00 00 00 00 00 00 00 00 00
00 00 00 00 00 00 00 00 00 00 00 00 00 00 00 00
00 00 00 00 00 00 00 00 00 00 00 00 00 00 2e`

set cool to 19C

`f1 6c 01 10 00 00 00 00 00 00 00 00 00 00 00 00
00 00 00 00 00 00 00 00 00 00 00 00 00 00 00 00
00 00 00 00 00 00 00 93 00 00 00 00 00 00 00 00
00 00 00 00 00 00 00 00 00 00 00 00 00 00 00 00
00 00 00 00 00 00 00 00 00 00 00 00 00 00 00 00
00 00 00 00 00 00 00 00 00 00 00 00 00 00 00 00
00 00 00 00 00 00 00 00 00 00 00 00 00 00 ff`

set cool to 18C

`f1 6c 01 10 00 00 00 00 00 00 00 00 00 00 00 00
00 00 00 00 00 00 00 00 00 00 00 00 00 00 00 00
00 00 00 00 00 00 00 92 00 00 00 00 00 00 00 00
00 00 00 00 00 00 00 00 00 00 00 00 00 00 00 00
00 00 00 00 00 00 00 00 00 00 00 00 00 00 00 00
00 00 00 00 00 00 00 00 00 00 00 00 00 00 00 00
00 00 00 00 00 00 00 00 00 00 00 00 00 00 00`

set cool to 6C 

`f1 6c 01 10 00 00 00 00 00 00 00 00 00 00 00 00
00 00 00 00 00 00 00 00 00 00 00 00 00 00 00 00
00 00 00 00 00 00 00 86 00 00 00 00 00 00 00 00
00 00 00 00 00 00 00 00 00 00 00 00 00 00 00 00
00 00 00 00 00 00 00 00 00 00 00 00 00 00 00 00
00 00 00 00 00 00 00 00 00 00 00 00 00 00 00 00
00 00 00 00 00 00 00 00 00 00 00 00 00 00 0c`

cool mode

`f1 6c 01 10 00 00 03 00 00 00 00 00 00 00 00 00
00 00 00 00 00 00 00 00 00 00 00 00 00 00 00 00
00 00 00 00 00 00 00 00 00 00 00 00 00 00 00 00
00 00 00 00 00 00 00 00 00 00 00 00 00 00 00 00
00 00 00 00 00 00 00 00 00 00 00 00 00 00 00 00
00 00 00 00 00 00 00 00 00 00 00 00 00 00 00 00
00 00 00 00 00 00 00 00 00 00 00 00 00 00 8f`

auto mode

`f1 6c 01 10 00 00 08 00 00 00 00 00 00 00 00 00
00 00 00 00 00 00 00 00 00 00 00 00 00 00 00 00
00 00 00 00 00 00 00 00 00 00 00 00 00 00 00 00
00 00 00 00 00 00 00 00 00 00 00 00 00 00 00 00
00 00 00 00 00 00 00 00 00 00 00 00 00 00 00 00
00 00 00 00 00 00 00 00 00 00 00 00 00 00 00 00
00 00 00 00 00 00 00 00 00 00 00 00 00 00 8a`

heat mode

`f1 6c 01 10 00 00 02 00 00 00 00 00 00 00 00 00
00 00 00 00 00 00 00 00 00 00 00 00 00 00 00 00
00 00 00 00 00 00 00 00 00 00 00 00 00 00 00 00
00 00 00 00 00 00 00 00 00 00 00 00 00 00 00 00
00 00 00 00 00 00 00 00 00 00 00 00 00 00 00 00
00 00 00 00 00 00 00 00 00 00 00 00 00 00 00 00
00 00 00 00 00 00 00 00 00 00 00 00 00 00 90`

From service cloud commands:

DHW mode only

`f1 6c 01 10 42 54 21 49 00 05 00 00 00 00 00 00
00 00 00 00 00 00 00 00 00 00 00 00 00 00 00 00
00 00 00 00 00 00 80 94 00 00 b1 71 71 00 00 00
00 00 00 00 00 00 00 00 00 00 00 00 00 00 00 00
00 00 00 00 00 00 00 00 00 00 00 00 00 00 00 00
00 00 00 00 00 00 00 00 00 00 00 00 00 00 00 00
00 00 00 00 00 00 00 00 00 00 00 00 00 00 e6`

heat only

`f1 6c 01 10 42 54 12 49 00 05 00 00 00 00 00 00
00 00 00 00 00 00 00 00 00 00 00 00 00 00 00 00
00 00 00 00 00 00 80 94 00 00 b1 71 71 00 00 00
00 00 00 00 00 00 00 00 00 00 00 00 00 00 00 00
00 00 00 00 00 00 00 00 00 00 00 00 00 00 00 00
00 00 00 00 00 00 00 00 00 00 00 00 00 00 00 00
00 00 00 00 00 00 00 00 00 00 00 00 00 00 f5`

cool only

`f1 6c 01 10 42 54 13 49 00 05 00 00 00 00 00 00
00 00 00 00 00 00 00 00 00 00 00 00 00 00 00 00
00 00 00 00 00 00 80 94 00 00 b1 71 71 00 00 00
00 00 00 00 00 00 00 00 00 00 00 00 00 00 00 00
00 00 00 00 00 00 00 00 00 00 00 00 00 00 00 00
00 00 00 00 00 00 00 00 00 00 00 00 00 00 00 00
00 00 00 00 00 00 00 00 00 00 00 00 00 00 f4`

auto

`f1 6c 01 10 42 54 18 49 00 05 00 00 00 00 00 00
00 00 00 00 00 00 00 00 00 00 00 00 00 00 00 00
00 00 00 00 00 00 80 94 00 00 b1 71 71 00 00 00
00 00 00 00 00 00 00 00 00 00 00 00 00 00 00 00
00 00 00 00 00 00 00 00 00 00 00 00 00 00 00 00
00 00 00 00 00 00 00 00 00 00 00 00 00 00 00 00
00 00 00 00 00 00 00 00 00 00 00 00 00 00 ef`

heat + dhw

`f1 6c 01 10 42 54 22 49 00 05 00 00 00 00 00 00
00 00 00 00 00 00 00 00 00 00 00 00 00 00 00 00
00 00 00 00 00 00 80 94 00 00 b1 71 71 00 00 00
00 00 00 00 00 00 00 00 00 00 00 00 00 00 00 00
00 00 00 00 00 00 00 00 00 00 00 00 00 00 00 00
00 00 00 00 00 00 00 00 00 00 00 00 00 00 00 00
00 00 00 00 00 00 00 00 00 00 00 00 00 00 e5`

cool + dhw

`f1 6c 01 10 42 54 23 49 00 05 00 00 00 00 00 00
00 00 00 00 00 00 00 00 00 00 00 00 00 00 00 00
00 00 00 00 00 00 80 94 00 00 b1 71 71 00 00 00
00 00 00 00 00 00 00 00 00 00 00 00 00 00 00 00
00 00 00 00 00 00 00 00 00 00 00 00 00 00 00 00
00 00 00 00 00 00 00 00 00 00 00 00 00 00 00 00
00 00 00 00 00 00 00 00 00 00 00 00 00 00 e4`

auto + dhw

`f1 6c 01 10 42 54 28 49 00 05 00 00 00 00 00 00
00 00 00 00 00 00 00 00 00 00 00 00 00 00 00 00
00 00 00 00 00 00 80 94 00 00 b1 71 71 00 00 00
00 00 00 00 00 00 00 00 00 00 00 00 00 00 00 00
00 00 00 00 00 00 00 00 00 00 00 00 00 00 00 00
00 00 00 00 00 00 00 00 00 00 00 00 00 00 00 00
00 00 00 00 00 00 00 00 00 00 00 00 00 00 df`

holiday mode ON

`f1 6c 01 10 42 64 22 49 00 05 00 00 00 00 00 00
00 00 00 00 00 00 00 00 00 00 00 00 00 00 00 00
00 00 00 00 00 00 80 94 00 00 b1 71 71 00 00 00
00 00 00 00 00 00 00 00 00 00 00 00 00 00 00 00
00 00 00 00 00 00 00 00 00 00 00 00 00 00 00 00
00 00 00 00 00 00 00 00 00 00 00 00 00 00 00 00
00 00 00 00 00 00 00 00 00 00 00 00 00 00 d5`

holiday mode OFF

`f1 6c 01 10 42 54 22 49 00 05 00 00 00 00 00 00
00 00 00 00 00 00 00 00 00 00 00 00 00 00 00 00
00 00 00 00 00 00 80 94 00 00 b1 71 71 00 00 00
00 00 00 00 00 00 00 00 00 00 00 00 00 00 00 00
00 00 00 00 00 00 00 00 00 00 00 00 00 00 00 00
00 00 00 00 00 00 00 00 00 00 00 00 00 00 00 00
00 00 00 00 00 00 00 00 00 00 00 00 00 00 e5`

powerful 30 min

`f1 6c 01 10 42 54 22 4a 00 05 00 00 00 00 00 00
00 00 00 00 00 00 00 00 00 00 00 00 00 00 00 00
00 00 00 00 00 00 80 94 00 00 b1 71 71 00 00 00
00 00 00 00 00 00 00 00 00 00 00 00 00 00 00 00
00 00 00 00 00 00 00 00 00 00 00 00 00 00 00 00
00 00 00 00 00 00 00 00 00 00 00 00 00 00 00 00
00 00 00 00 00 00 00 00 00 00 00 00 00 00 e4`

powerful 60 min

`f1 6c 01 10 42 54 22 4b 00 05 00 00 00 00 00 00
00 00 00 00 00 00 00 00 00 00 00 00 00 00 00 00
00 00 00 00 00 00 80 94 00 00 b1 71 71 00 00 00
00 00 00 00 00 00 00 00 00 00 00 00 00 00 00 00
00 00 00 00 00 00 00 00 00 00 00 00 00 00 00 00
00 00 00 00 00 00 00 00 00 00 00 00 00 00 00 00
00 00 00 00 00 00 00 00 00 00 00 00 00 00 e3`

powerful 90 min

`f1 6c 01 10 42 54 22 4c 00 05 00 00 00 00 00 00
00 00 00 00 00 00 00 00 00 00 00 00 00 00 00 00
00 00 00 00 00 00 80 94 00 00 b1 71 71 00 00 00
00 00 00 00 00 00 00 00 00 00 00 00 00 00 00 00
00 00 00 00 00 00 00 00 00 00 00 00 00 00 00 00
00 00 00 00 00 00 00 00 00 00 00 00 00 00 00 00
00 00 00 00 00 00 00 00 00 00 00 00 00 00 e2`

powerful off

`f1 6c 01 10 42 54 22 49 00 05 00 00 00 00 00 00
00 00 00 00 00 00 00 00 00 00 00 00 00 00 00 00
00 00 00 00 00 00 80 94 00 00 b1 71 71 00 00 00
00 00 00 00 00 00 00 00 00 00 00 00 00 00 00 00
00 00 00 00 00 00 00 00 00 00 00 00 00 00 00 00
00 00 00 00 00 00 00 00 00 00 00 00 00 00 00 00
00 00 00 00 00 00 00 00 00 00 00 00 00 00 e5`

force DHW on

`f1 6c 01 10 82 54 21 49 00 05 00 00 00 00 00 00
00 00 00 00 00 00 00 00 00 00 00 00 00 00 00 00
00 00 00 00 00 00 80 94 00 00 b1 71 71 00 00 00
00 00 00 00 00 00 00 00 00 00 00 00 00 00 00 00
00 00 00 00 00 00 00 00 00 00 00 00 00 00 00 00
00 00 00 00 00 00 00 00 00 00 00 00 00 00 00 00
00 00 00 00 00 00 00 00 00 00 00 00 00 00 a6`

Force DHW OFF

`f1 6c 01 10 42 54 21 49 00 05 00 00 00 00 00 00
00 00 00 00 00 00 00 00 00 00 00 00 00 00 00 00
00 00 00 00 00 00 80 94 00 00 b1 71 71 00 00 00
00 00 00 00 00 00 00 00 00 00 00 00 00 00 00 00
00 00 00 00 00 00 00 00 00 00 00 00 00 00 00 00
00 00 00 00 00 00 00 00 00 00 00 00 00 00 00 00
00 00 00 00 00 00 00 00 00 00 00 00 00 00 e6`

Heat pump Power ON

`f1 6c 01 10 42 54 12 49 00 05 00 00 00 00 00 00
00 00 00 00 00 00 00 00 00 00 00 00 00 00 00 00
00 00 00 00 00 00 94 9c 00 00 b1 80 80 00 00 00
00 00 00 00 00 00 00 00 00 00 00 00 00 00 00 00
00 00 00 00 00 00 00 00 00 00 00 00 00 00 00 00
00 00 00 00 00 00 00 00 00 00 00 00 00 00 00 00
00 00 00 00 00 00 00 00 00 00 00 00 00 00 bb`

Heat pump Power OFF

`f1 6c 01 10 41 54 22 49 00 05 00 00 00 00 00 00
00 00 00 00 00 00 00 00 00 00 00 00 00 00 00 00
00 00 00 00 00 00 80 8a 00 00 b1 80 80 00 00 00
00 00 00 00 00 00 00 00 00 00 00 00 00 00 00 00
00 00 00 00 00 00 00 00 00 00 00 00 00 00 00 00
00 00 00 00 00 00 00 00 00 00 00 00 00 00 00 00
00 00 00 00 00 00 00 00 00 00 00 00 00 00 d2`

Command sequence to set Zone & Sensor

Set Internal Thermostat

`f1 6c 01 10 01 00 00 00 00 00 00 00 00 00 00 00
00 00 00 00 00 00 00 00 00 00 00 00 00 00 00 00
00 00 00 00 00 00 00 00 00 00 00 00 00 00 00 00
00 00 00 00 00 00 00 00 00 00 00 00 00 00 00 00
00 00 00 00 00 00 00 00 00 00 00 00 00 00 00 00
00 00 00 00 00 00 00 00 00 00 00 00 00 00 00 00
00 00 00 00 00 00 00 00 00 00 00 00 00 00 91`

`f1 6c 01 10 00 00 00 00 00 00 00 00 00 00 00 00
00 00 00 00 19 05 03 55 16 12 55 05 00 00 00 00
00 00 00 00 00 00 00 00 00 00 00 00 00 00 00 00
00 00 00 00 00 00 00 00 00 00 00 00 15 8a 85 85
d0 7b 78 1f 7e 1f 1f 79 79 8d 8d 00 00 00 00 00
00 00 00 00 00 00 00 00 00 00 00 00 00 00 00 00
00 00 00 00 00 00 00 00 00 00 00 00 00 00 47`

`f1 6c 01 10 00 00 00 00 00 00 00 00 00 00 00 00
00 00 00 00 19 05 03 55 16 12 55 05 00 00 00 00
00 00 00 00 00 00 00 00 00 00 00 00 00 00 00 00
00 00 00 00 00 00 00 00 00 00 00 00 15 8a 85 85
d0 7b 78 1f 7e 1f 1f 79 79 8d 8d 00 00 00 00 00
00 00 00 00 00 00 00 00 00 00 00 00 00 00 00 00
00 00 00 00 00 00 00 00 00 00 00 00 00 00 47`

`f1 6c 01 10 00 00 00 00 00 00 00 00 00 00 00 00
00 00 00 00 00 00 00 00 00 00 00 00 00 00 00 00
00 00 00 00 00 00 00 00 00 00 00 00 00 00 00 00
00 00 00 00 00 00 00 00 00 00 00 00 00 00 00 00
00 00 00 00 00 00 00 00 00 00 00 00 00 00 00 00
00 00 00 00 00 00 00 00 00 00 00 00 00 00 00 00
00 00 00 00 00 00 00 00 00 00 00 00 00 00 92`

Set Water Temperature

sends off command  (same pattern with other setting commands)

`f1 6c 01 10 01 00 00 00 00 00 00 00 00 00 00 00
00 00 00 00 00 00 00 00 00 00 00 00 00 00 00 00
00 00 00 00 00 00 00 00 00 00 00 00 00 00 00 00
00 00 00 00 00 00 00 00 00 00 00 00 00 00 00 00
00 00 00 00 00 00 00 00 00 00 00 00 00 00 00 00
00 00 00 00 00 00 00 00 00 00 00 00 00 00 00 00
00 00 00 00 00 00 00 00 00 00 00 00 00 00 91`

sets value

`f1 6c 01 10 00 00 00 00 00 00 00 00 00 00 00 00
00 00 00 00 19 05 01 55 16 12 55 05 00 00 00 00
00 00 00 00 00 00 00 00 00 00 00 00 00 00 00 00
00 00 00 00 00 00 00 00 00 00 00 00 15 8a 85 85
d0 7b 78 1f 7e 1f 1f 79 79 8d 8d 00 00 00 00 00
00 00 00 00 00 00 00 00 00 00 00 00 00 00 00 00
00 00 00 00 00 00 00 00 00 00 00 00 00 00 49`

this should be confirmation (same pattern with other setting commands)

`f1 6c 01 10 00 00 00 00 00 00 00 00 00 00 00 00
00 00 00 00 00 00 00 00 00 00 00 00 00 00 00 00
00 00 00 00 00 00 00 00 00 00 00 00 00 00 00 00
00 00 00 00 00 00 00 00 00 00 00 00 00 00 00 00
00 00 00 00 00 00 00 00 00 00 00 00 00 00 00 00
00 00 00 00 00 00 00 00 00 00 00 00 00 00 00 00
00 00 00 00 00 00 00 00 00 00 00 00 00 00 92`

Room Sensor External

`f1 6c 01 10 00 00 00 00 00 00 00 00 00 00 00 00
00 00 00 00 19 05 02 55 16 12 55 05 00 00 00 00
00 00 00 00 00 00 00 00 00 00 00 00 00 00 00 00
00 00 00 00 00 00 00 00 00 00 00 00 15 8a 85 85
d0 7b 78 1f 7e 1f 1f 79 79 8d 8d 00 00 00 00 00
00 00 00 00 00 00 00 00 00 00 00 00 00 00 00 00
00 00 00 00 00 00 00 00 00 00 00 00 00 00 48`

Room Sensor Thermistor

`f1 6c 01 10 00 00 00 00 00 00 00 00 00 00 00 00
00 00 00 00 19 05 04 55 16 12 55 05 00 00 00 00
00 00 00 00 00 00 00 00 00 00 00 00 00 00 00 00
00 00 00 00 00 00 00 00 00 00 00 00 15 8a 85 85
d0 7b 78 1f 7e 1f 1f 79 79 8d 8d 00 00 00 00 00
00 00 00 00 00 00 00 00 00 00 00 00 00 00 00 00
00 00 00 00 00 00 00 00 00 00 00 00 00 00 46`

Operation Setup --> Installer

Water temperature for heating on Compensationio Curve

`f1 6c 01 10 00 00 00 00 00 00 00 00 00 00 00 00
00 00 00 00 00 00 00 00 00 00 00 00 09 00 00 00
00 00 00 00 00 00 00 00 00 00 00 00 00 00 00 00
00 00 00 00 00 00 00 00 00 00 00 00 00 00 00 00
00 00 00 00 00 00 00 00 00 00 00 9e 96 71 8f 00
00 00 00 89 85 80 8a 8a 94 9e 8a 00 00 00 82 94
8b 05 65 78 c1 0b 00 00 00 00 00 00 00 00 a8`

Heat Direct

`f1 6c 01 10 00 00 00 00 00 00 00 00 00 00 00 00
00 00 00 00 00 00 00 00 00 00 00 00 0a 00 00 00
00 00 00 00 00 00 00 00 00 00 00 00 00 00 00 00
00 00 00 00 00 00 00 00 00 00 00 00 00 00 00 00
00 00 00 00 00 00 00 00 00 00 00 9e 96 71 8f b7
00 00 00 89 85 80 8a 8a 94 9e 8a 00 00 00 82 94
8b 05 65 78 c1 0b 00 00 00 00 00 00 00 00 f0`

Water temperature for Cooling on Compensation curve set

`f1 6c 01 10 00 00 00 00 00 00 00 00 00 00 00 00
00 00 00 00 00 00 00 00 00 00 00 00 05 00 00 00
00 00 00 00 00 00 00 00 00 00 00 00 00 00 00 00
00 00 00 00 00 00 00 00 00 00 00 00 00 00 00 00
00 00 00 00 00 00 00 00 00 00 00 9e 96 71 8f 00
00 00 00 89 85 80 8a 8a 94 9e 00 00 00 00 82 94
8b 05 65 78 c1 0b 00 00 00 00 00 00 00 00 36`

Cool Direct

`f1 6c 01 10 00 00 00 00 00 00 00 00 00 00 00 00
00 00 00 00 00 00 00 00 00 00 00 00 09 00 00 00
00 00 00 00 00 00 00 00 00 00 00 00 00 00 00 00
00 00 00 00 00 00 00 00 00 00 00 00 00 00 00 00
00 00 00 00 00 00 00 00 00 00 00 9e 96 71 8f 00
00 00 00 89 85 80 8a 8a 94 9e 8f 00 00 00 82 94
8b 05 65 78 c1 0b 00 00 00 00 00 00 00 00 a3`

set Delta T for heating 6c

`f1 6c 01 10 00 00 00 00 00 00 00 00 00 00 00 00
00 00 00 00 00 00 00 00 00 00 00 00 09 00 00 00
00 00 00 00 00 00 00 00 00 00 00 00 00 00 00 00
00 00 00 00 00 00 00 00 00 00 00 00 00 00 00 00
00 00 00 00 00 00 00 00 00 00 00 9e 96 71 8f 00
00 00 00 89 86 80 8a 8a 94 9e 8f 00 00 00 82 94
8b 05 65 78 c1 0b 00 00 00 00 00 00 00 00 a2`

outdoor temperature for heating off 10C

`f1 6c 01 10 00 00 00 00 00 00 00 00 00 00 00 00
00 00 00 00 00 00 00 00 00 00 00 00 09 00 00 00
00 00 00 00 00 00 00 00 00 00 00 00 00 00 00 00
00 00 00 00 00 00 00 00 00 00 00 00 00 00 00 00
00 00 00 00 00 00 00 00 00 00 00 9e 96 71 8f 00
00 00 00 8a 85 80 8a 8a 94 9e 8f 00 00 00 82 94
8b 05 65 78 c1 0b 00 00 00 00 00 00 00 00 a2`

delta T for cooling 3C

`f1 6c 01 10 00 00 00 00 00 00 00 00 00 00 00 00
00 00 00 00 00 00 00 00 00 00 00 00 09 00 00 00
00 00 00 00 00 00 00 00 00 00 00 00 00 00 00 00
00 00 00 00 00 00 00 00 00 00 00 00 00 00 00 00
00 00 00 00 00 00 00 00 00 00 00 9e 96 71 8f 00
00 00 00 8a 85 80 8a 8a 94 9e 8f 00 00 00 83 94
8b 05 65 78 c1 0b 00 00 00 00 00 00 00 00 a1`

cool zone1 temperature set dircet 20C

`f1 6c 01 10 00 00 00 00 00 00 00 00 00 00 00 00
00 00 00 00 00 00 00 00 00 00 00 00 09 00 00 00
00 00 00 00 00 00 00 00 00 00 00 00 00 00 00 00
00 00 00 00 00 00 00 00 00 00 00 00 00 00 00 00
00 00 00 00 00 00 00 00 00 00 00 9e 96 71 8f 00
00 00 00 8a 85 80 94 8a 94 9e 8f 00 00 00 83 94
8b 05 65 78 c1 0b 00 00 00 00 00 00 00 00 97`

Auto mode
Outdoor temperature mode for (heat to cool) 21C

`f1 6c 01 10 00 00 00 00 00 00 00 00 00 00 00 00
00 00 00 00 00 00 00 00 00 00 00 00 09 00 00 00
00 00 00 00 00 00 00 00 00 00 00 00 00 00 00 00
00 00 00 00 00 00 00 00 00 00 00 00 00 00 00 00
00 00 00 00 00 00 00 00 00 00 00 9e 96 71 8f 00
00 00 00 8a 85 80 8a 8a 94 9e 8f 00 00 00 83 95
8b 05 65 78 c1 0b 00 00 00 00 00 00 00 00 a0`

for cool to heat set 12C

`f1 6c 01 10 00 00 00 00 00 00 00 00 00 00 00 00
00 00 00 00 00 00 00 00 00 00 00 00 09 00 00 00
00 00 00 00 00 00 00 00 00 00 00 00 00 00 00 00
00 00 00 00 00 00 00 00 00 00 00 00 00 00 00 00
00 00 00 00 00 00 00 00 00 00 00 9e 96 71 8f 00
00 00 00 8a 85 80 8a 8a 94 9e 8f 00 00 00 83 95
8c 05 65 78 c1 0b 00 00 00 00 00 00 00 00 9f`

DHW settings

Room Operation time maximum 90 min

`f1 6c 01 10 00 00 00 00 00 00 00 00 00 00 00 00
00 00 00 00 00 00 00 00 00 00 00 00 09 00 00 00
00 00 00 00 00 00 00 00 00 00 00 00 00 00 00 00
00 00 00 00 00 00 00 00 00 00 00 00 00 00 00 00
00 00 00 00 00 00 00 00 00 00 00 9e 96 71 8f 00
00 00 00 8a 85 80 8a 8a 94 9e 8f 00 00 00 83 95
8c 04 65 78 c1 0b 00 00 00 00 00 00 00 00 a0`

DHW heat up DHW maximum 105 min

`f1 6c 01 10 00 00 00 00 00 00 00 00 00 00 00 00
00 00 00 00 00 00 00 00 00 00 00 00 09 00 00 00
00 00 00 00 00 00 00 00 00 00 00 00 00 00 00 00
00 00 00 00 00 00 00 00 00 00 00 00 00 00 00 00
00 00 00 00 00 00 00 00 00 00 00 9e 96 71 8f 00
00 00 00 8a 85 80 8a 8a 94 9e 8f 00 00 00 83 95
8c 05 6a 78 c1 0b 00 00 00 00 00 00 00 00 9a`

sterilization boiling temp set 66C

`f1 6c 01 10 00 00 00 00 00 00 00 00 00 00 00 00
00 00 00 00 00 00 00 00 00 00 00 00 09 00 00 00
00 00 00 00 00 00 00 00 00 00 00 00 00 00 00 00
00 00 00 00 00 00 00 00 00 00 00 00 00 00 00 00
00 00 00 00 00 00 00 00 00 00 00 9e 96 71 8f 00
00 00 00 8a 85 80 8a 8a 94 9e 8f 00 00 00 83 95
8c 05 6a 78 c2 0b 00 00 00 00 00 00 00 00 99`

set sterilization time 15 min

`f1 6c 01 10 00 00 00 00 00 00 00 00 00 00 00 00
00 00 00 00 00 00 00 00 00 00 00 00 09 00 00 00
00 00 00 00 00 00 00 00 00 00 00 00 00 00 00 00
00 00 00 00 00 00 00 00 00 00 00 00 00 00 00 00
00 00 00 00 00 00 00 00 00 00 00 9e 96 71 8f 00
00 00 00 8a 85 80 8a 8a 94 9e 8f 00 00 00 83 95
8c 05 6a 78 b7 10 00 00 00 00 00 00 00 00 9f`

better to use these instead from user cloud

quiet off

`f1 6c 01 10 42 54 22 49 00 05 00 00 00 00 00 00
00 00 00 00 00 00 00 00 00 00 00 00 00 00 00 00
00 00 00 00 00 00 80 94 00 00 b1 71 71 00 00 00
00 00 00 00 00 00 00 00 00 00 00 00 00 00 00 00
00 00 00 00 00 00 00 00 00 00 00 00 00 00 00 00
00 00 00 00 00 00 00 00 00 00 00 00 00 00 00 00
00 00 00 00 00 00 00 00 00 00 00 00 00 00 e5`

quiet 1

`f1 6c 01 10 42 54 22 51 00 05 00 00 00 00 00 00
00 00 00 00 00 00 00 00 00 00 00 00 00 00 00 00
00 00 00 00 00 00 80 94 00 00 b1 71 71 00 00 00
00 00 00 00 00 00 00 00 00 00 00 00 00 00 00 00
00 00 00 00 00 00 00 00 00 00 00 00 00 00 00 00
00 00 00 00 00 00 00 00 00 00 00 00 00 00 00 00
00 00 00 00 00 00 00 00 00 00 00 00 00 00 dd`

quiet 2

`f1 6c 01 10 42 54 22 59 00 05 00 00 00 00 00 00
00 00 00 00 00 00 00 00 00 00 00 00 00 00 00 00
00 00 00 00 00 00 80 94 00 00 b1 71 71 00 00 00
00 00 00 00 00 00 00 00 00 00 00 00 00 00 00 00
00 00 00 00 00 00 00 00 00 00 00 00 00 00 00 00
00 00 00 00 00 00 00 00 00 00 00 00 00 00 00 00
00 00 00 00 00 00 00 00 00 00 00 00 00 00 d5`

quiet 3

`f1 6c 01 10 42 54 22 61 00 05 00 00 00 00 00 00
00 00 00 00 00 00 00 00 00 00 00 00 00 00 00 00
00 00 00 00 00 00 80 94 00 00 b1 71 71 00 00 00
00 00 00 00 00 00 00 00 00 00 00 00 00 00 00 00
00 00 00 00 00 00 00 00 00 00 00 00 00 00 00 00
00 00 00 00 00 00 00 00 00 00 00 00 00 00 00 00
00 00 00 00 00 00 00 00 00 00 00 00 00 00 cd`

Force defrost request

`f1 6c 01 10 42 54 22 49 02 05 00 00 00 00 00 00
00 00 00 00 00 00 00 00 00 00 00 00 00 00 00 00
00 00 00 00 00 00 80 94 00 00 b1 71 71 00 00 00
00 00 00 00 00 00 00 00 00 00 00 00 00 00 00 00
00 00 00 00 00 00 00 00 00 00 00 00 00 00 00 00
00 00 00 00 00 00 00 00 00 00 00 00 00 00 00 00
00 00 00 00 00 00 00 00 00 00 00 00 00 00 e3`

Sterilization request

`f1 6c 01 10 42 54 22 49 04 05 00 00 00 00 00 00
00 00 00 00 00 00 00 00 00 00 00 00 00 00 00 00
00 00 00 00 00 00 80 94 00 00 b1 71 71 00 00 00
00 00 00 00 00 00 00 00 00 00 00 00 00 00 00 00
00 00 00 00 00 00 00 00 00 00 00 00 00 00 00 00
00 00 00 00 00 00 00 00 00 00 00 00 00 00 00 00
00 00 00 00 00 00 00 00 00 00 00 00 00 00 e1`

Weekly timer on (byte 5 changes)

`f1 6c 01 10 42 94 22 49 00 05 00 00 00 00 00 00
00 00 00 00 00 00 00 00 00 00 00 00 00 00 00 00
00 00 00 00 00 00 7b 94 00 00 b1 71 71 00 00 00
00 00 00 00 00 00 00 00 00 00 00 00 00 00 00 00
00 00 00 00 00 00 00 00 00 00 00 00 00 00 00 00
00 00 00 00 00 00 00 00 00 00 00 00 00 00 00 00
00 00 00 00 00 00 00 00 00 00 00 00 00 00 aa`

Weekly timer off (byte 5 changes)

`f1 6c 01 10 42 54 22 49 00 05 00 00 00 00 00 00
00 00 00 00 00 00 00 00 00 00 00 00 00 00 00 00
00 00 00 00 00 00 7b 94 00 00 b1 71 71 00 00 00
00 00 00 00 00 00 00 00 00 00 00 00 00 00 00 00
00 00 00 00 00 00 00 00 00 00 00 00 00 00 00 00
00 00 00 00 00 00 00 00 00 00 00 00 00 00 00 00
00 00 00 00 00 00 00 00 00 00 00 00 00 00 ea`

Quiet timer on (byte 7 changes)

`f1 6c 01 10 42 94 22 89 00 05 00 00 00 00 00 00
00 00 00 00 00 00 00 00 00 00 00 00 00 00 00 00
00 00 00 00 00 00 7b 94 00 00 b1 71 71 00 00 00
00 00 00 00 00 00 00 00 00 00 00 00 00 00 00 00
00 00 00 00 00 00 00 00 00 00 00 00 00 00 00 00
00 00 00 00 00 00 00 00 00 00 00 00 00 00 00 00
00 00 00 00 00 00 00 00 00 00 00 00 00 00 6a`

Quiet timer off (byte 7 changes)

`f1 6c 01 10 42 54 22 49 00 05 00 00 00 00 00 00
00 00 00 00 00 00 00 00 00 00 00 00 00 00 00 00
00 00 00 00 00 00 7b 94 00 00 b1 71 71 00 00 00
00 00 00 00 00 00 00 00 00 00 00 00 00 00 00 00
00 00 00 00 00 00 00 00 00 00 00 00 00 00 00 00
00 00 00 00 00 00 00 00 00 00 00 00 00 00 00 00
00 00 00 00 00 00 00 00 00 00 00 00 00 00 ea`

DHW heater on (byte 9 changes)

`f1 6c 01 10 42 54 22 49 00 09 00 00 00 00 00 00
00 00 00 00 00 00 00 00 00 00 00 00 00 00 00 00
00 00 00 00 00 00 7b 94 00 00 b1 71 71 00 00 00
00 00 00 00 00 00 00 00 00 00 00 00 00 00 00 00
00 00 00 00 00 00 00 00 00 00 00 00 00 00 00 00
00 00 00 00 00 00 00 00 00 00 00 00 00 00 00 00
00 00 00 00 00 00 00 00 00 00 00 00 00 00 e6`

DHW heater off (byte 9 changes)

`f1 6c 01 10 42 54 22 49 00 05 00 00 00 00 00 00
00 00 00 00 00 00 00 00 00 00 00 00 00 00 00 00
00 00 00 00 00 00 7b 94 00 00 b1 71 71 00 00 00
00 00 00 00 00 00 00 00 00 00 00 00 00 00 00 00
00 00 00 00 00 00 00 00 00 00 00 00 00 00 00 00
00 00 00 00 00 00 00 00 00 00 00 00 00 00 00 00
00 00 00 00 00 00 00 00 00 00 00 00 00 00 ea`

Error reset (reboot)

`f1 6c 01 10 00 00 00 00 01 00 00 00 00 00 00 00
00 00 00 00 00 00 00 00 00 00 00 00 00 00 00 00
00 00 00 00 00 00 00 00 00 00 00 00 00 00 00 00
00 00 00 00 00 00 00 00 00 00 00 00 00 00 00 00
00 00 00 00 00 00 00 00 00 00 00 00 00 00 00 00
00 00 00 00 00 00 00 00 00 00 00 00 00 00 00 00
00 00 00 00 00 00 00 00 00 00 00 00 00 00 91
`

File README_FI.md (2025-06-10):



# Panasonic Aquarea H-, J-, K- ja L-sarjan vesi-ilmalämpöpumpun protokollaa lukeva IoT-laite

Tämä ESP8266-projekti mahdollistaa Panasonic Aquarea vesi-ilmalämpöpumppujen toimittamien tietojen raportoimisen MQTT-palvelimelle. Se tarjoaa myös JSON-muotoisen tiedon, jota voit pollata, jos et halua käyttää MQTT:tä. Myös ESP32 on tuettu.

Ajantasainen, englanninkielinen [README.md](README.md) löytyy täältä.

# Julkaistu versio

Viimeisin julkaistu versio on saatavilla [täältä](https://github.com/Egyras/HeishaMon/releases) Se voidaan asentaa Wemos D1 minille, Heishamon PCB:lle tai luultavasti mille tahansa muulle ESP8266-pohjaiselle kehitysalustalle (ei takuita toimivuudesta, joidenkin Wemos-kopioiden kanssa ollut ongelmia). Voit myös ladata lähdekoodin ja kääntää omat binäärit (katso tarvittavat kirjastot alta). ESP32-S3 binääri on tarkoitettu uudelle, hieman suuremmalle Heishamon PCB:lle.

# Käyttö

Nykyinen Arduino-softa pystyy kommunikoimaan Panasonicin Aquarea H/J/K/L-sarjan vesi-ilmalämpöpumppujen kanssa. \
Jos haluat kääntää softan itse, niin lataa kaikki tarvittavat kirjastot ja muista myös filesystem-tuki ESP8266:lle Arduino IDE:ssä.

Kun ensimmäisen kerran kytket virrat laitteeseen, kytkeydy HeishaMonin tarjoamaan avoimeen WiFi-hotspotiin, jota käytetään ensimmäisen käynnistyksen yhteydessä asetusten tekemiseen. Asetussivu löytyy osoitteesta http://192.168.4.1 ja sieltä voit määrittää WiFi-verkon ja MQTT-palvelimen asetukset.

Laitteen voi palauttaa tehdasasetuksille painamalla kaksi kertaa reset-nappia nopeasti. Silloin tiedostojärjestelmä tyhjennetään ja WiFi-asetukset palautetaan ennalleen ja voit taas liittyä avoimeen WiFi-verkkoon asetusten tekemistä varten.

Kun olet tehnyt asetukset, laite käynnistyy uudestaan ja liittyy määrittelemääsi WiFi-verkkoon. Se alkaa kyselemään lämpöpumpulta tietoja säännöllisesti ja raportoi tiedot MQTT-palvelimelle. GPIO13/GPIO15-pinnejä käytetään tiedonsiirtoon ja voit pitää tietokoneesi kytkettynä USB-portissa, jos haluat lukea debug-tietoja tai päivittää firmwarea.

Kaikki vastaanotettu tieto raportoidaan eri MQTT-aiheiden alle (katso koko lista alempaa). Web UI:n kautta voi myös kytkeä päälle lokituksen ja viestien hexadumppauksen, jolloin nämä tiedot raportoidaan aiheen 'panasonic_heat_pump/log' alle.

Voit myös liittää 1-wire sensorin GPIO4-liitäntään ja sen arvo raporoidaan omassa MQTT-aiheessaan (panasonic_heat_pump/1wire/sensorid).

HeishaMon voi myös lukea kahden kWh-mittarin S0-portista sähkönkulutusta. Kytke GPIO12 ja GND kWh-mittarin S0-liitäntään ja jos tarvitset vielä toisen liitännän käytä GPIO14:ta siihen. Kulutus raportoidaan MQTT-aiheiden 'panasonic_heat_pump/s0/Watt/1' ja 'panasonic_heat_pump/s0/Watt/2' alla sekä JSON-tulosteessa. Hetkellisen tehon sijasta näet kulutuksen (kWh), jos vaihdat topiciin 'Watt'in sijasta 'Watthour'.

Firmwaren voi päivittää laitteen konfigurointisivun kautta kirjautumalla tunnuksella 'admin' ja valitsemallasi salasanalla (oletus on heisha).

JSON-muodossa lämpöpumpun tilan voi hakea osoitteesta http://heishamon.local/json (korvaa heishamon.local laitteesi IP-osoitteella, jos MDNS ei toimi verkossasi).

'integrations' hakemistosta löydät esimerkkejä laitteen integroimisesta erilaisiin kotiautomaatiojärjestelmiin.

# Lisätietoa

Alla vielä hieman teknisiä lisätietoja projektista, kuten esimerkiksi kaapelinrakennusohjeet ja apua piirilevyn suunnitteluun.

## Yhteys lämpöpumppuun

Yhteys voidaan muodostaa CN-CNT tai CN-NMODE liitäntöjen kautta. Molempia ei voida käyttää samanaikaisesti. Huomaa, että jos sinulla on Panasonicin CZ-TAW1 WiFi-sovitin käytössäsi, voit vain kytkeä HeishaMon-laitteen sen sijasta käyttäen samaa kaapelia.

Yhteysasetukset: TTL 5V UART 9600,8,E,1 \
\
CN-CNT Pin-out (ylhäältä alas) \
1 - +5V (250mA)  \
2 - 0-5V TX  \
3 - 0-5V RX  \
4 - +12V (250mA) \
5 - GND \
 \
CN-NMODE Pin-out (vasemmalta oikealle) \
"Huom! Kuten piirilevyllä sanotaan, vasen pinni on numero 4 ja oikealla reunassa on pinni 1. \
4 - +5V (250mA)  \
3 - 0-5V TX  \
2 - 0-5V RX  \
1 - GND

Heishamon saa virtansa Aquarea-lämpöpumpulta, erillistä virtalähdettä ei tarvita.

## Mistä ostaa liittimiä 
[RS-Online orders](Connectors_RSO.md)

[Conrad orders](Connectors_Conrad.md)

Käytä 24 AWG suojattua 4-johtimista kaapelia.

## Piirilevyn valmistaminen 
The PCB's needed to connect to the heatpump are designed by project members and are listed below. \
[PCD Designs from the project members](PCB_Designs.md) \
[Picture Wemos D1 beta](WEMOSD1.JPG) \
[Picture ESP12-F](NewHeishamon.JPG)

Jos haluat päästä helpolla, voit myös ostaa valmiin piirilevyn tai kaapelin, joita projektin jäsenet ovat tehneet: \
[Tindie shop](https://www.tindie.com/stores/thehognl/) - Igor Ybema (aka TheHogNL) Hollannissa

## Arduino-imagen kääntäminen 
boards: \
esp8266 by esp8266 community version 3.0.2 [Arduino](https://github.com/esp8266/Arduino/releases/tag/3.0.2)

[Käytetyt kirjastot](LIBSUSED.md)

## MQTT-aiheet 
[Lista tämän hetkisistä MQTT-aiheista](MQTT-Topics.md)

## DS18b20 1-wire tuki

Softa tukee myös DS18B20 1-wire lämpötilasensoreita. Kunnollinen 1-wire sensori (sis. 4.7 kOhm pull-up vastuksen) liitettynä GPIO4-liitäntään luetaan joka 30 sekunnin välein ja tieto palautetaan 'panasonic_heat_pump/1wire/"sensor-hex-address"' aiheessa.
 
## Protocol info -paketti:
Saadaksesi tietoa pumpulta, täytyy sille lähettää "magic" paketti:

`71 6c 01 10 00 00 00 00 00 00 00 00 00 00 00 00 00 00 00 00 00 00 00 00 00 00 00 00 00 00 00 00 00 00 00 00 00 00 00 00 00 00 00 00 00 00 00 00 00 00 00 00 00 00 00 00 00 00 00 00 00 00 00 00 00 00 00 00 00 00 00 00 00 00 00 00 00 00 00 00 00 00 00 00 00 00 00 00 00 00 00 00 00 00 00 00 00 00 00 00 00 00 00 00 00 00 00 00 00 00 12`

## Viestin formaatti: 
[Current list of documented bytes decrypted can be found here](ProtocolByteDecrypt.md)

## Integraatio-esimerkkejä Open Source -kotiautomaatioon
[Openhab2](Integrations/Openhab2)

[Home Assistant](https://github.com/Egyras/HeishaMon/tree/master/Integrations/Home%20Assistant)

[IOBroker Manual](Integrations/ioBroker_manual)

[Domoticz](Integrations/Domoticz)

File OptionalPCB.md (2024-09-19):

## Optional PCB:

Optional PCB is also connected to HP via the CN-CNT ( in case using it and CZ-TAW1 ,Optional PCB is connected to HP , and on Optional PCB there is another CN-CNT to connect CZ-TAW1).
In this way Optional PCB communicate with HP in similar way to CZ-TAW1 - Next to(between) standard Magic Packets there specific commands from Optional PCB to HP ,and next to (between) answers from HP there is a answer/confirmation to Optional PCB.

### Optional PCB emulation support:
Recent firmware allows (experimental) support for optional PCB emulation. This allows you to set SmartGrid or Demand Control values without having the optional pcb installed. Also you can send the temperatures normally connected to that board to the heatpump.

You can publish mqtt messages towards the 'topic base/commands/pcb_topic', so for example "panasonic_heat_pump/commands/SetSolarTemp". For temperatures you just send the real temperature (the hexadecimal value will be calculated for your). For SmartGrid and Demand control you send the decimal representation of the hex value you want to send (see below for the possible hex values).

Remark 1: You need to set in HP Service settings Optional PCB to YES ,and appropriate function as well to have effect in sending MQTT topics.

Remark 2: Turning on Optional PCB in HP's options will couse ,that Room Thermo 1 input will not work anymore (H/J series only). It is now possible to use PCB topics "SetExternalThermostat1State" (with substitute Room Thermo 1 now)  and "SetExternalThermostat2State".

Remark 3: Setting in HP Service settings Optional PCB to YES gives expectation ,that Optional PCB emulator ( HeishaMon) will sent continuously Optional PCB Set Command. When communication disappear (for around 40s) HP generates H74 error and switches off to StandBy. So ensure continiues communication is very important , be aware during switch off , factory default of HeishaMon , or similar action.

Remark 4: If you enable optional pcb emulation the HeishaMon not boot into a wifi config hotspot if it can not connect to your previously configured wifi during boot. Also during wifi failures it will keep running and try to reconnect to the wifi instead of rebooting into wifi hotspotconfig. It is important to send often optional pcb commands to the heatpump and therefore it can not react on wifi failures like that. So if you have a running wifi and heishamon and need to reconfigure your wifi ssid or password you first need to factory reset your heishamon. Or if you need to reconfigure your HeishaMon in such situation you need the double reset factory reset trick to clear the config on the Heishamon.

### Set command byte decrypt:

| PCB Topic |Topic value| Byte# | Possible Value | Value decrypt | Value Description |
|:---- | ---- | ---- | ---- | ----- | ----:|
| |-| 00 | F1 | | Header  |
| |-| 01 | 11 | Data length ( Packet length = Data length + 3 ) |  Header |
| |-| 02 | 01 | | Header  |
| |-| 03 | 50 | | Header  |
| |-| 04 | 00 | | Acknowledge for Z1/Z2/Pool Water Pump & Mixing valves state  |
| |-| 05 | 00 | | Acknowledge for Alarm  |
| SetHeatCoolMode<br/>SetCompressorState<br/>SetSmartGridMode<br/>SetExternalThermostat1State<br/>SetExternalThermostat2State |0/1<br/>0/1<br/>0/1/2/3<br/>0/1/2/3<br/>0/1/2/3<br/>| 06 | 40 | 1st bit = Heat/Cool<br/>2nd bit = Compressor state<br/>3rd/4th bit == SmartGrid Mode (00 = normal, 10 = HP/DHW off, 01 = Capacity 1, 11 = Capacity 2)<br/>5th/6th bit = Thermostat 1 (00 = no demand, 01 = cool demand, 10 = heat demand, 11 = heat and cool demand)<br/>7th/8th bit = Thermostat 2 (00 = no demand, 01 = cool demand, 10 = heat demand, 11 = heat and cool demand)  | SG ready values , External Compressor SW , Heat/Cool SW, Thermostat 1 (H/J series only), Thermostat 2 |
| SetPoolTemp |Temp [C]| 07 | FF |  NTC 6,5kOhm resistance characteristic value | Temp. Pool  |
| SetBufferTemp |Temp [C]| 08 | FF |  NTC 6,5kOhm resistance characteristic value | Temp. Buffer<br/>(H/J series only) |
| |-| 09 | E5 but also93,92,91 (90) ,A2 | | ?  |
| SetZ1RoomTemp |Temp [C]| 10 | FF |  NTC 6,5kOhm resistance characteristic value | Temp. Z1_Room<br/>(H/J series only)  |
| SetZ2RoomTemp |Temp [C]| 11 | FF |  NTC 6,5kOhm resistance characteristic value | Temp. Z2_Room |
| |-| 12 | 00 | | 0 byte  |
| SetSolarTemp |Temp [C]| 13 | FF |  NTC 6,5kOhm resistance characteristic value | Temp. Solar  |
| SetDemandControl |from<br/>43 -5%<br/> to <br/>234 - 100%| 14 | EA | HEX:  EB-100% ,B8 - 75% ,85 -50%,52 - 25% ,2B - 5% | Demand Control |
| SetZ2WaterTemp |Temp [C]| 15 | FF |  NTC 6,5kOhm resistance characteristic value | Temp. Z2_Water |
| SetZ1WaterTemp |Temp [C] | 16 | FF |  NTC 6,5kOhm resistance characteristic value | Temp. Z1_Water |
| |-| 17 | 00 | | 0 byte  |
| |-| 18 | 00 | | 0 byte  |
| |-| 19 | 2C |  CHECKSUM |  |

### Answer/confirmation from HP to Optional PCB 

Answer/confirmation contains also steering parameters :

`71 11 01 50 00 00 00 00 00 00 00 00 00 00 00 00 00 00 00 2D`

| Byte# | Possible Value | Value decrypt | Value Description |
|:---- | ---- | ----- | ----:|
| 04 | C4 |1st bit = Z1 Water pump <br/> 2nd bit = Z1 Mixing Valve + <br/> 3rd bit = Z1 Mixing Valve - <br/> 4th bit = Z2 Water pump <br/> 5th bit = Z2 Mixing Valve + <br/> 6th bit = Z2 Mixing Valve - <br/> 7th bit = Pool Water pump <br/> 8th bit = Solar Water pump <br/> |  |
| 05 | 01 | 00 - No Alarm </br> 01 - Alarm | |

## NTC 6,5kOhm characteristic:

Values are direct measurement of NTC thermistor conected to Optional PCB.
It can be approximate by function : Uref * (RT / (Rf + RT)) where Uref = 255 and Rf=6480. RT is calculated as R25 * exp(constant * (1 / (temp + K) - 1 / (T25 + K))) where R25 = 6340, T25=25, K=273.15, constant=3695 and temp the input temperature.

#### Exact values table 

| HEX Val. | Temp [C] | HEX Val. | Temp [C] | Hex Val. | Temp [C] | Hex Val. | Temp [C] |
|--- | --- | --- | --- | --- | --- | ---- | --- |
| 00 | 120 | 40 | 53 | 80 | 24 | C0 | 0 |
| 01 | 120 | 41 | 53 | 81 | 24 | C1 | 0 |
| 02 | 120 | 42 | 52 | 82 | 24 | C2 | -1 |
| 03 | 120 | 43 | 51 | 83 | 23 | C3 | -1 |
| 04 | 120 | 44 | 51 | 84 | 23 | C4 | -2 |
| 05 | 120 | 45 | 50 | 85 | 22 | C5 | -2 |
| 06 | 120 | 46 | 50 | 86 | 22 | C6 | -3 |
| 07 | 120 | 47 | 49 | 87 | 22 | C7 | -3 |
| 08 | 120 | 48 | 49 | 88 | 21 | C8 | -4 |
| 09 | 120 | 49 | 48 | 89 | 21 | C9 | -4 |
| 0A | 120 | 4A | 48 | 8A | 21 | CA | -4 |
| 0B | 120 | 4B | 47 | 8B | 20 | CB | -5 |
| 0C | 117 | 4C | 47 | 8C | 20 | CC | -5 |
| 0D | 114 | 4D | 46 | 8D | 19 | CD | -6 |
| 0E | 111 | 4E | 45 | 8E | 19 | CE | -6 |
| 0F | 108 | 4F | 45 | 8F | 19 | CF | -7 |
| 10 | 106 | 50 | 44 | 90 | 18 | D0 | -7 |
| 11 | 103 | 51 | 44 | 91 | 18 | D1 | -8 |
| 12 | 101 | 52 | 44 | 92 | 18 | D2 | -8 |
| 13 | 99 | 53 | 43 | 93 | 17 | D3 | -9 |
| 14 | 97 | 54 | 43 | 94 | 17 | D4 | -9 |
| 15 | 95 | 55 | 42 | 95 | 17 | D5 | -10 |
| 16 | 93 | 56 | 42 | 96 | 16 | D6 | -10 |
| 17 | 92 | 57 | 41 | 97 | 16 | D7 | -11 |
| 18 | 90 | 58 | 41 | 98 | 15 | D8 | -12 |
| 19 | 88 | 59 | 40 | 99 | 15 | D9 | -12 |
| 1A | 87 | 5A | 40 | 9A | 15 | DA | -13 |
| 1B | 86 | 5B | 39 | 9B | 14 | DB | -13 |
| 1C | 84 | 5C | 39 | 9C | 14 | DC | -14 |
| 1D | 83 | 5D | 38 | 9D | 14 | DD | -15 |
| 1E | 82 | 5E | 38 | 9E | 13 | DE | -15 |
| 1F | 80 | 5F | 38 | 9F | 13 | DF | -16 |
| 20 | 79 | 60 | 37 | A0 | 12 | E0 | -16 |
| 21 | 78 | 61 | 37 | A1 | 12 | E1 | -17 |
| 22 | 77 | 62 | 36 | A2 | 12 | E2 | -18 |
| 23 | 76 | 63 | 36 | A3 | 11 | E3 | -18 |
| 24 | 75 | 64 | 35 | A4 | 11 | E4 | -19 |
| 25 | 74 | 65 | 35 | A5 | 11 | E5 | -20  |
| 26 | 73 | 66 | 35 | A6 | 10 | E6 | -21 |
| 27 | 72 | 67 | 34 | A7 | 10 | E7 | -21 |
| 28 | 71 | 68 | 34 | A8 | 9 | E8 | -22 |
| 29 | 70 | 69 | 33 | A9 | 9 | E9 | -23 |
| 2A | 69 | 6A | 33 | AA | 9 | EA | -24 |
| 2B | 68 | 6B | 32 | AB | 8 | EB | -25 |
| 2C | 67 | 6C | 32 | AC | 8 | EC | -26 |
| 2D | 66 | 6D | 32 | AD | 8 | ED | -27 |
| 2E | 66 | 6E | 31 | AE | 7 | EE | -28 |
| 2F | 65 | 6F | 31 | AF | 7 | EF | -29 |
| 30 | 64 | 70 | 30 | B0 | 6 | F0 | -30 |
| 31 | 63 | 71 | 30 | B1 | 6 | F1 | -31 |
| 32 | 62 | 72 | 30 | B2 | 6 | F2 | -32 |
| 33 | 62 | 73 | 29 | B3 | 5 | F3 | -33 |
| 34 | 61 | 74 | 29 | B4 | 5 | F4 | -35 |
| 35 | 60 | 75 | 28 | B5 | 4 | F5 | -36 |
| 36 | 60 | 76 | 28 | B6 | 4 | F6 | -38 |
| 37 | 59 | 77 | 28 | B7 | 4 | F7 | -40 |
| 38 | 58 | 78 | 27 | B8 | 3 | F8 | -41 |
| 39 | 58 | 79 | 27 | B9 | 3 | F9 | -44 |
| 3A | 57 | 7A | 27 | BA | 2 | FA | -46 |
| 3B | 56 | 7B | 26 | BB | 2 | FB | -49 |
| 3C | 56 | 7C | 26 | BC | 2 | FC | -53 |
| 3D | 55 | 7D | 25 | BD | 1 | FD | -57 |
| 3E | 54 | 7E | 25 | BE | 1 | FE | -64 |
| 3F | 54 | 7F | 25 | BF | 0 | FF | -78 |

### To do:

- Byte #9 decode ( probably connected with Buffer)

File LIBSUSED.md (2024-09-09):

## libs used

**Note:** 

This is just a user friendly display of commands used in build action https://github.com/Egyras/HeishaMon/blob/master/.github/workflows/main.yml

Only actual code in build action is relevant!

| lib | version | download |
| ---- | ---- | ---- |
|pubsubclient by nick o'leary | 2.8.0 | https://github.com/knolleary/pubsubclient/releases/tag/v2.8 |
|arduinojson by benoit blanchon | 6.19.4 | https://github.com/bblanchon/ArduinoJson/releases/tag/v6.19.4 |
|dallastemperature | 3.9.0 | https://github.com/milesburton/Arduino-Temperature-Control-Library/releases/tag/3.9.0 |
|onewire | 2.3.5 | https://www.pjrc.com/teensy/td_libs_OneWire.html |

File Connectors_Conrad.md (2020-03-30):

## For Conrad orders

| JST Type | Conrad article number | Description |
| ----- | ----: | ----- |
|B05B-XASK-1| 741366 | Header matching CZ-TAW1, for soldering on PCB. S05B-XASK-1 (not orderable at conrad) is the side-ways version	|
|B05B-PASK-1| 1426194 | Header matching CN-CNT (that what is on the heatpump itself). Only need this if you want to build a proxy-forward PCB|
|XAP-05V-1| 741233 | Cable connector on CZ-TAW1/PCB side |
|PAP-05V-1| 1426227 | Cable connector on CN-CNT side | 
|BXA-01T-P0.6| 741295 |Connector pins on CZ-TAW1/PCB side|
|SPHD-002T-P0.5| 1426240 | Connector pins on CN-CNT side |
|PHR-4| 740614 | CN-NMode 4-pin connector housing |
|SPH-002T-P0.5S| 741135 | CN-NMode connector pins |

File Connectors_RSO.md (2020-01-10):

## For RS-Online orders

| JST Type | RS-Online article number | Description |
| ----- | ---- | ----- |
|CN-CNT female connector PAP-05V-S | [4766768](https://uk.rs-online.com/web/p/pcb-connector-housings/4766798/) | JST Female Connector Housing - PA, 2mm Pitch, 5 Way, 1 Row |
|CZ-TAW1 male header JST B05B-XASK-1 | [6027679](https://uk.rs-online.com/web/p/pcb-headers/6027679/) |  |
|Pre-made crimp leads 150 mm | [5128726](https://uk.rs-online.com/web/p/pre-crimped-leads/5128721/)| crimp-free end lead PA 2.0 can be used |

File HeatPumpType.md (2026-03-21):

## HeatPumpType:

Assuming that bytes from #129 to #138 are unique for each model of Aquarea heat pump:

| Value |  Bytes 129 - 138 | IDU | ODU | KIT | Power [kW] | 1ph/3ph | T-CAP/HP |
| ---| --- | --- | --- | --- | --- | --- | ---|
| 0 | E2 CF 0B 13 33 32 D1 0C 16 33 | Monoblock | WH-MDC05H3E5 | Monoblock | 5 | 1ph | HP |
| 1 | E2 CF 0B 14 33 42 D1 0B 17 33 | Monoblock | WH-MDC07H3E5 | Monoblock | 7 | 1ph | HP |
| 2 | E2 CF 0D 77 09 12 D0 0B 05 11 | WH-SXC09H3E5 | WH-UX09HE5 | KIT-WXC09H3E5 | 9 | 1ph | T-CAP |
| 3 | E2 CF 0C 88 05 12 D0 0B 97 05 | WH-SDC09H3E8 | WH-UD09HE8 | KIT-WC09H3E8 | 9 | 3ph | HP |
| 4 | E2 CF 0D 85 05 12 D0 0C 94 05 | WH-SXC09H3E8 | WH-UX09HE8 | KIT-WXC09H9E8 | 9 | 3ph | T-CAP |
| 5 | E2 CF 0D 86 05 12 D0 0C 95 05 | WH-SXC12H9E8 | WH-UX12HE8 | KIT-WXC12H9E8 | 12 | 3ph | T-CAP |
| 6 | E2 CF 0D 87 05 12 D0 0C 96 05 | WH-SXC16H9E8 | WH-UX16HE8 | KIT-WXC16H9E8 | 16 | 3ph | T-CAP |
| 7 | E2 CE 0D 71 81 72 CE 0C 92 81 | WH-SDC05H3E5 | WH-UD05HE5 | KIT-WC05H3E5  | 5 | 1ph | HP |
| 8 | 62 D2 0B 43 54 42 D2 0B 72 66 | WH-SDC0709J3E5 | WH-UD09JE5 | KIT-WC09J3E5 | 9 | 1ph | HP |
| 9 | C2 D3 0B 33 65 B2 D3 0B 94 65 | Monoblock | WH-MDC05J3E5 | Monoblock | 5 | 1ph | HP |
|10 | E2 CF 0B 15 33 42 D1 0B 18 33 | Monoblock | WH-MDC09H3E5 | Monoblock | 9 | 1ph | HP |
|11 | E2 CF 0B 41 34 82 D1 0B 31 35 | Monoblock | WH-MXC09H3E5 | Monoblock | 9 | 1ph | T-CAP |
|12 | 62 D2 0B 45 54 42 D2 0B 47 55 | WH-ADC0309J3E5 | WH-UD09JE5 | KIT-ADC09JE5 | 9 | 1ph | HP - All-In-One |
|13 | E2 CF 0C 74 09 12 D0 0D 95 05 | WH-ADC0916H9E8 | WH-UX12HE8 | KIT-AXC12HE8 | 12 | 3ph | T-CAP - All-In-One |
|14 | E2 CF 0B 82 05 12 D0 0C 91 05 | WH-SQC09H3E8 | WH-UQ09HE8 | KIT-WQC09H3E8 | 9 | 3ph | T-CAP - Super Quiet |
|15 | E2 CF 0C 55 14 12 D0 0B 15 08 | WH-SDC09H3E5 | WH-UD09HE5 | KIT-WC09H3E5 | 9 | 1 ph | HP |
|16 | E2 CF 0C 43 00 12 D0 0B 15 08 | WH-ADC0309H3E5 | WH-UD09HE5 | KIT-ADC09HE5 | 9 | 1 ph | HP - All-In-One |
|17 | 62 D2 0B 45 54 32 D2 0C 45 55 | WH-ADC0309J3E5 | WH-UD05JE5 | KIT-ADC05JE5 | 5 | 1ph | HP - All-In-One |
|18 | 62 D2 0B 43 54 42 D2 0C 46 55 | WH-SDC0709J3E5 | WH-UD07JE5 | KIT-WC07J3E5 | 7 | 1 ph | HP |
|19 | E2 CF 0C 54 14 12 D0 0B 14 08 | WH-SDC07H3E5-1 | WH-UD07HE5-1 | KIT-WC07H3E5-1 | 7 | 1 ph | HP |
|20 | C2 D3 0B 34 65 B2 D3 0B 95 65 | Monoblock | WH-MDC07J3E5 | Monoblock | 7 | 1ph | HP |
|21 | C2 D3 0B 35 65 B2 D3 0B 96 65 | Monoblock | WH-MDC09J3E5 | Monoblock | 9 | 1ph | HP |
|22 | 62 D2 0B 41 54 32 D2 0C 45 55 | WH-SDC0305J3E5 | WH-UD05JE5 | KIT-WC05J3E5 | 5 | 1ph | HP |
|23 | 32 D4 0B 87 84 73 90 0C 84 84 | Monoblock | WH-MXC09J3E8 | Monoblock | 9 | 3ph | T-CAP |
|24 | 32 D4 0B 88 84 73 90 0C 85 84 | Monoblock | WH-MXC12J9E8 | Monoblock | 12 | 3ph | T-CAP |
|25 | E2 CF 0B 75 09 12 D0 0C 06 11 | WH-ADC1216H6E5 | WH-UD12HE5 | KIT-ADC12HE5 | 12 | 1ph | T-CAP |
|26 | 42 D4 0B 83 71 42 D2 0C 46 55 | WH-ADC0309J3E5C | WH-UD07JE5 | KIT-ADC07JE5C | 7 | 1ph | HP - All-In-One Compact |
|27 | C2 D3 0C 34 65 B2 D3 0B 95 65 | Monoblock | WH-MDC07J3E5 | Monoblock | 7 | 1ph | HP (new version) |
|28 | C2 D3 0C 33 65 B2 D3 0B 94 65 | Monoblock | WH-MDC05J3E5 | Monoblock | 5 | 1ph | HP (new version) |
|29 | E2 CF 0B 83 05 12 D0 0D 92 05 | WH-SQC12H9E8 | WH-UQ12HE8 | KIT-WQC12H9E8 | 12 | 3ph | T-CAP - Super Quiet |
|30 | E2 CF 0C 78 09 12 D0 0B 06 11 | WH-SXC12H6E5 | WH-UX12HE5 | KIT-WXC12H6E5 | 12 | 1ph | T-CAP |
|31 | C2 D3 0C 35 65 B2 D3 0B 96 65 | Monoblock | WH-MDC09J3E5 | Monoblock | 9 | 1ph | HP (new version?) |
|32 | 32 D4 0B 99 77 62 90 0B 01 78 | Monoblock | WH-MXC09J3E5 | Monoblock | 9 | 1ph | T-CAP |
|33 | 42 D4 0B 15 76 12 D0 0B 10 11 | WH-ADC1216H6E5C | WH-UD12HE5 | KIT-ADC12HE5C-CL | 12 | 1ph| HP - All-In-One Compact |
|34 | E2 D5 0C 29 99 83 92 0C 28 98 | WH-ADC0509L3E5 | WH-WDG07LE5 | KIT-ADC07L3E5 | 7 | 1ph | HP - All-In-One L-series |
|35 | E2 CF 0D 85 05 12 D0 0E 94 05 | WH-SXC09H3E8 | WH-UX09HE8 | KIT-WXC09H3E8 | 9 | 3ph | T-CAP - new version |
|36 | E2 D5 0D 36 99 02 D6 0F 67 95 | WH-ADC0309K3E5AN | WH-UDZ07KE5 | KIT-ADC07K3E5AN | 7 | 1ph | HP - All-In-One K-series - AN |
|37 | E2 D5 0B 08 95 02 D6 0E 66 95 | WH-SDC0309K3E5 | WH-UDZ05KE5 | KIT-WC05K3E5 | 5 | 1ph | HP - split K-series |
|38 | E2 D5 0B 34 99 83 92 0C 29 98 | WH-SDC0509L3E5 |  WH-WDG09LE5 | KIT-WC09L3E5 | 9 | 1 ph | HP - split L-series 3kW elec heating |
|39 | E2 CF 0C 89 05 12 D0 0C 98 05 | WH-SDC12H9E8 | WH-UD12HE8 | KIT-WC12H9E8 | 12 | 3ph | HP |
|40 | E2 D5 0B 08 95 02 D6 0E 67 95 | WH-SDC0309K3E5 | WH-UDZ07KE5 | KIT-WC07K3E5 | 7 | 1ph | HP - split K-series |
|41 | E2 CF 0C 74 09 12 D0 0C 96 05 | WH-ADC0916H9E8 | WH-UX16HE8 | KIT-AXC16HE8 | 16 | 3ph | T-CAP - All-In-One |
|42 | E2 CF 0C 74 09 12 D0 0E 95 05 | WH-ADC0912H9E8 | WH-UX12HE8 | KIT-AXC12HE8 | 12 | 3ph | T-CAP - All-In-One |
|43 | 32 D4 0B 89 84 73 90 0C 86 84 | Monoblock | WH-MXC16J9E8 | Monoblock | 16 | 3ph | T-CAP |
|44 | 32 D4 0B 00 78 62 90 0B 02 78 | Monoblock | WH-MXC12J6E5 | Monoblock | 12 | 1ph | T-CAP |
|45 | E2 CF 0B 82 05 12 D0 0D 91 05 | WH-SQC09H3E8 | WH-UQ09HE8 | KIT-WQC09H3E8 | 9 | 3ph | T-CAP - Super Quiet revised model |
|46 | E2 D5 0D 99 94 02 D6 0D 68 95 | WH-ADC0309K3E5 | WH-UDZ09KE5 | KIT-ADC09K3E5 | 9 | 1ph | HP - K-series All-in-One R32 |
|47 | E2 CF 0C 74 09 12 D0 0C 95 05 | WH-ADC0916H9E8 | WH-UX12HE8 | KIT-AXC12HE8 | 12 | 3ph | T-CAP - All-In-One |
|48 | E2 D5 0B 34 99 83 92 0C 28 98 | WH-SDC0509L3E5 |  WH-WDG07LE5 | KIT-WC07L3E5 | 7 | 1 ph | HP - split L-series 3kW elec heating |
|49 | E2 CF 0D 77 09 12 D0 0C 05 11 | WH-SXC09H3E5 | WH-UX09HE5 | KIT-WXC09H3E5 | 9 | 1ph | T-CAP |
|50 | E2 CF 0B 44 34 12 D0 0C 34 35 | Monoblock | WH-MXC12H9E8 | Monoblock | 12 | 3ph | T-CAP |
|51 | E2 D5 0C 67 00 83 92 0C 27 98 | WH-ADC0509L3E5AN | WH-WDG05LE5 | KIT-ADC05L3E5AN | 5 | 1ph | HP - split L-series 3kW elec heating - AN |
|52 | E2 D5 0B 34 99 83 92 0C 27 98 | WH-SDC0509L3E5 | WH-WDG05LE5 | KIT-WC05L3E5 | 5 | 1ph | HP - split L-series 3kW elec heating |
|53 | 42 D4 0B 83 71 32 D2 0C 44 55 | WH-ADC0309J3E5C | WH-UD03JE5 | KIT-ADC03JE5C-S | 3.2 | 1ph | HP - All-In-One Compact |
|54 | E2 CF 0C 74 09 12 D0 0E 94 05 | WH-ADC0916H9E8 | WH-UX09HE8 | KIT-AXC9HE8 | 9 | 3ph | T-CAP - All-In-One |
|55 | 12 D7 0D 98 11 33 94 0C 83 10 | WH-ADC0316M9E8AN2 | WH-WXG09ME8 | Monoblock | 9 | 2ph | T-CAP - M-series DHW 185l |
|56 | E2 D5 0B 08 95 02 D6 0F 67 95 | WH-SDC0309K3E5 | WH-UDZ07KE5 | KIT-SDC07KE5 | 7 | 1ph | HP - split K-series (sold in Poland) |
|57 | E2 D5 0D 36 99 02 D6 10 66 95 | WH-ADC0309K3E5AN | WH-UDZ05KE5 | KIT-ADC05K3E5AN | 5 | 1ph | HP - All-In-One K-series - AN |
|58 | E2 D5 0F 99 94 02 D6 10 68 95 | WH-ADC0309K3E5 | WH-UDZ09KE5 | KIT-ADC09K3E5 | 9 | 1ph | HP - split K-series 9KW |
|59 | E2 D5 0C 67 00 83 92 0C 28 98 | WH-ADC0509L3E5AN | WH-WDG07LE5 | KIT-ADC07L3E5AN | 7 | 1ph | HP - All-In-One L-series - AN |
|60 | E2 CF 0D 86 05 12 D0 0E 95 05 | WH-SXC12H9E8 | WH-UX12HE8 | KIT-WXC12H9E8 | 12 | 3ph | T-CAP |
|61 | 12 D7 0C 98 14 35 94 0D 83 10 | WH-SDC0316M9E8 | WH-WXG09ME8 | KIT-SDCWXG09 | 9 | 3ph | T-CAP - M-series | 
|62 | E2 D5 0C 08 95 02 D6 10 67 95 | WH-SDC0309K3E5 | WH-UDZ07KE5 | KIT-SDC07KE5 | 7 | 1ph | HP - split K-series 3kW elec heating |

All bytes are used for Heat Pump model identification in the code.

Note: These are the heat pump types that users have verified and reported back the model. HeishaMon should work with all H and J generation Aquarea heat pumps.

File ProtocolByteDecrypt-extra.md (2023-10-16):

## Protocol byte decrypt info for the new data block on newer models:

|  Topic# | Byte# | Possible Value | Value decrypt | Value Description |
| :---- | ---- | ---- | ----- | ----:|
| TOP | 0 | 71 | | Header|
| TOP | 1 | C8 | Data length ( Packet length = Data length + 3 )| Header|
| TOP | 2 | 01 | | Header|
| TOP | 3 | 21 | This is 0x21 for new data block | Header|
| TOP | 4 | 8A | | |
| TOP | 5 | EA | | |
| TOP | 6 | 01 | | |
| TOP | 7 | 00 | | |
| TOP | 8 | 00 | | |
| TOP | 9 | 00 | | |
| TOP | 10 | 00 | | |
| TOP | 11 | 00 | | |
| TOP | 12 | 00 | | |
| TOP | 13 | 00 | | |
| TOP | 14 | 30 | Little-endian uint_16 with next byte | Power usage for heat in Watt |
| TOP | 15 | 03 | Little-endian uint_16 with previous byte | Power usage for heat in Watt |
| TOP | 16 | 01 | Little-endian uint_16 with next byte | Power usage for cool in Watt |
| TOP | 17 | 00 | Little-endian uint_16 with previous byte | Power usage for cool in Watt |
| TOP | 18 | 01 | Little-endian uint_16 with next byte | Power usage for DHW in Watt |
| TOP | 19 | 00 | Little-endian uint_16 with previous byte | Power usage for DHW in Watt |
| TOP | 20 | 48 | Little-endian uint_16 with next byte | Power generated for heat in Watt  |
| TOP | 21 | 07 | Little-endian uint_16 with previous byte | Power generated for heat in Watt |
| TOP | 22 | 01 | Little-endian uint_16 with next byte | Power generated for cool in Watt  |
| TOP | 23 | 00 | Little-endian uint_16 with previous byte | Power generated for cool in Watt |
| TOP | 24 | 01 | Little-endian uint_16 with next byte | Power generated for DHW in Watt  |
| TOP | 25 | 00 | Little-endian uint_16 with previous byte | Power generated for DHW in Watt |
| TOP | 26 | 01 | | |
| TOP | 27 | 00 | | |
| TOP | 28 | 00 | | |
| TOP | 29 | 00 | | |
| TOP | 30 | 01 | | |
| TOP | 31 | 00 | | |
| TOP | 32 | 00 | | |
| TOP | 33 | 00 | | |
| TOP | 34 | 01 | | |
| TOP | 35 | 00 | | |
| TOP | 36 | 00 | | |
| TOP | 37 | 00 | | |
| TOP | 38 | 01 | | |
| TOP | 39 | 00 | | |
| TOP | 40 | 00 | | |
| TOP | 41 | 00 | | |
| TOP | 42 | 01 | | |
| TOP | 43 | 00 | | |
| TOP | 44 | 01 | | |
| TOP | 45 | 00 | | |
| TOP | 46 | 01 | | |
| TOP | 47 | 00 | | |
| TOP | 48 | 00 | | |
| TOP | 49 | 00 | | |
| TOP | 50 | 00 | | |
| TOP | 51 | 00 | | |
| TOP | 52 | 00 | | |
| TOP | 53 | 00 | | |
| TOP | 54 | 00 | | |
| TOP | 55 | 00 | | |
| TOP | 56 | 00 | | |
| TOP | 57 | 00 | | |
| TOP | 58 | 00 | | |
| TOP | 59 | 00 | | |
| TOP | 60 | 00 | | |
| TOP | 61 | 00 | | |
| TOP | 62 | 00 | | |
| TOP | 63 | 00 | | |
| TOP | 64 | 00 | | |
| TOP | 65 | 00 | | |
| TOP | 66 | 00 | | |
| TOP | 67 | 00 | | |
| TOP | 68 | 00 | | |
| TOP | 69 | 00 | | |
| TOP | 70 | 00 | | |
| TOP | 71 | 00 | | |
| TOP | 72 | 00 | | |
| TOP | 73 | 00 | | |
| TOP | 74 | 00 | | |
| TOP | 75 | 00 | | |
| TOP | 76 | 00 | | |
| TOP | 77 | 00 | | |
| TOP | 78 | 00 | | |
| TOP | 79 | 00 | | |
| TOP | 80 | 00 | | |
| TOP | 81 | 00 | | |
| TOP | 82 | 00 | | |
| TOP | 83 | 00 | | |
| TOP | 84 | 00 | | |
| TOP | 85 | 00 | | |
| TOP | 86 | 00 | | |
| TOP | 87 | 00 | | |
| TOP | 88 | 00 | | |
| TOP | 89 | 00 | | |
| TOP | 90 | 00 | | |
| TOP | 91 | 00 | | |
| TOP | 92 | 00 | | |
| TOP | 93 | 00 | | |
| TOP | 94 | 00 | | |
| TOP | 95 | 00 | | |
| TOP | 96 | 00 | | |
| TOP | 97 | 00 | | |
| TOP | 98 | 00 | | |
| TOP | 99 | 00 | | |
| TOP | 100 | 00 | | |
| TOP | 101 | 00 | | |
| TOP | 102 | 00 | | |
| TOP | 103 | 00 | | |
| TOP | 104 | 00 | | |
| TOP | 105 | 00 | | |
| TOP | 106 | 00 | | |
| TOP | 107 | 00 | | |
| TOP | 108 | 00 | | |
| TOP | 109 | 00 | | |
| TOP | 110 | 00 | | |
| TOP | 111 | 00 | | |
| TOP | 112 | 00 | | |
| TOP | 113 | 00 | | |
| TOP | 114 | 00 | | |
| TOP | 115 | 00 | | |
| TOP | 116 | 00 | | |
| TOP | 117 | 00 | | |
| TOP | 118 | 00 | | |
| TOP | 119 | 00 | | |
| TOP | 120 | 00 | | |
| TOP | 121 | 00 | | |
| TOP | 122 | 00 | | |
| TOP | 123 | 00 | | |
| TOP | 124 | 00 | | |
| TOP | 125 | 00 | | |
| TOP | 126 | 00 | | |
| TOP | 127 | 00 | | |
| TOP | 128 | 00 | | |
| TOP | 129 | 00 | | |
| TOP | 130 | 00 | | |
| TOP | 131 | 00 | | |
| TOP | 132 | 00 | | |
| TOP | 133 | 00 | | |
| TOP | 134 | 00 | | |
| TOP | 135 | 00 | | |
| TOP | 136 | 00 | | |
| TOP | 137 | 00 | | |
| TOP | 138 | 00 | | |
| TOP | 139 | 00 | | |
| TOP | 140 | 00 | | |
| TOP | 141 | 00 | | |
| TOP | 142 | 00 | | |
| TOP | 143 | 00 | | |
| TOP | 144 | 00 | | |
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

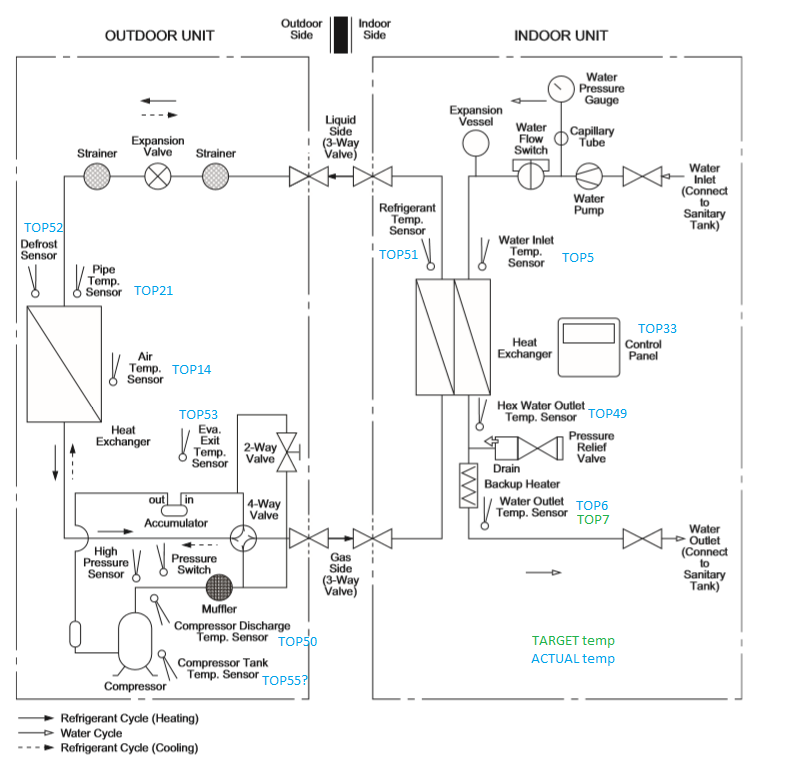
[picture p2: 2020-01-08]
heatpump-internal-temperatures.png

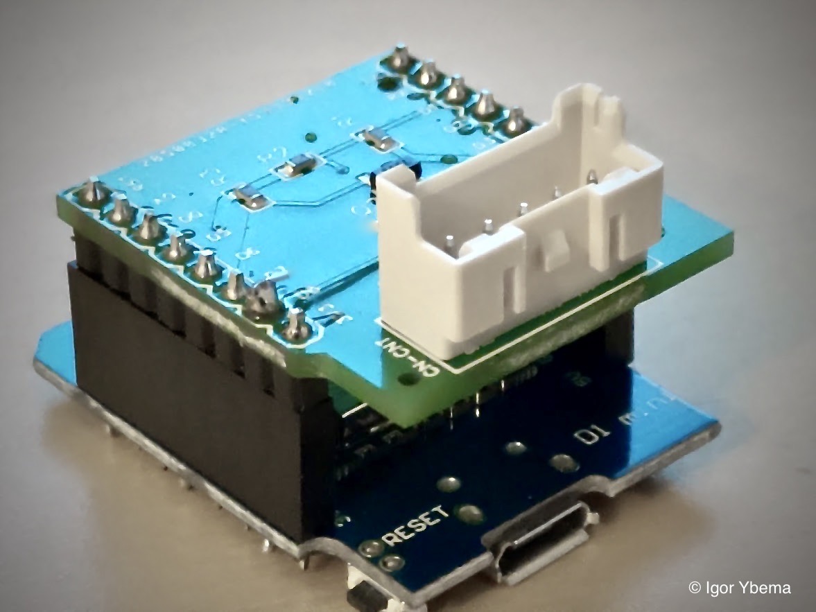
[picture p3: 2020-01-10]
WEMOSD1.JPG

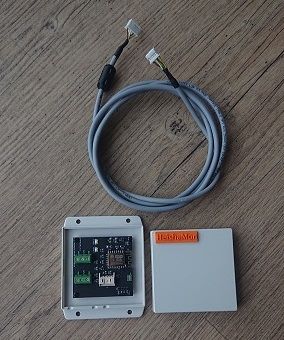
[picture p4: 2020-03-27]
NewHeishamon.JPG

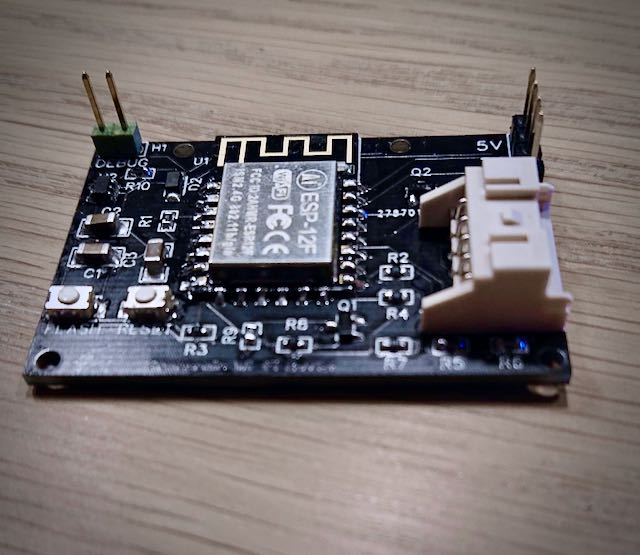
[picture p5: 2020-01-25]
New_PCB.jpeg

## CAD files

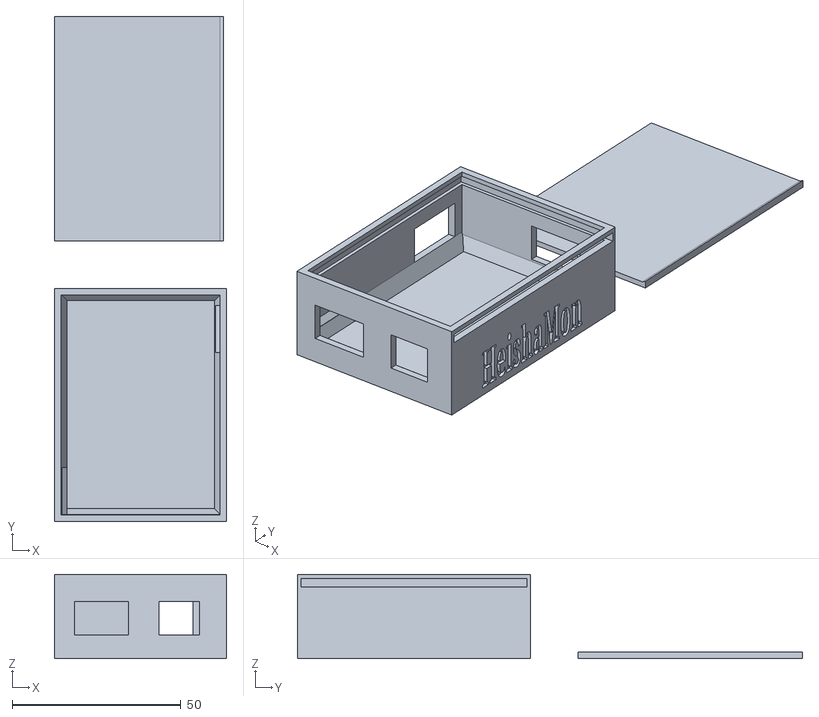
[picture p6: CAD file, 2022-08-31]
Heishamon-case-small-version-with-opentherm.stl
51.0 x 149.5 x 25.0

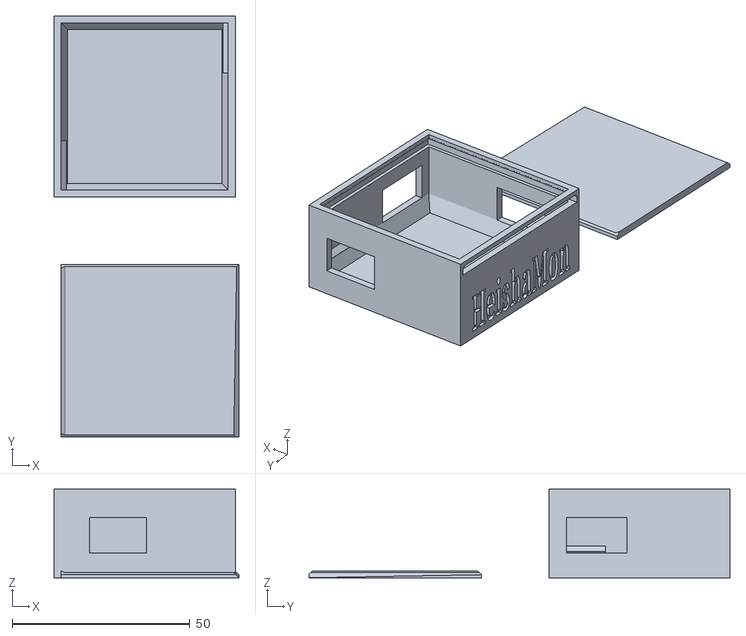
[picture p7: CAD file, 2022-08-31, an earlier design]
Heishamon-case-not-used-old-version.stl
52.0 x 118.5 x 25.0

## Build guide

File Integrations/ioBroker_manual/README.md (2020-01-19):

## Manual integration in ioBroker

# General

With this manual, you can manually integrate the heishamon into iobroker via mqtt. 

# mqtt in iobroker

## Installation
1. Install the mqtt adapter for iobroker. Go to *Adapters* and search for `mqtt`.  
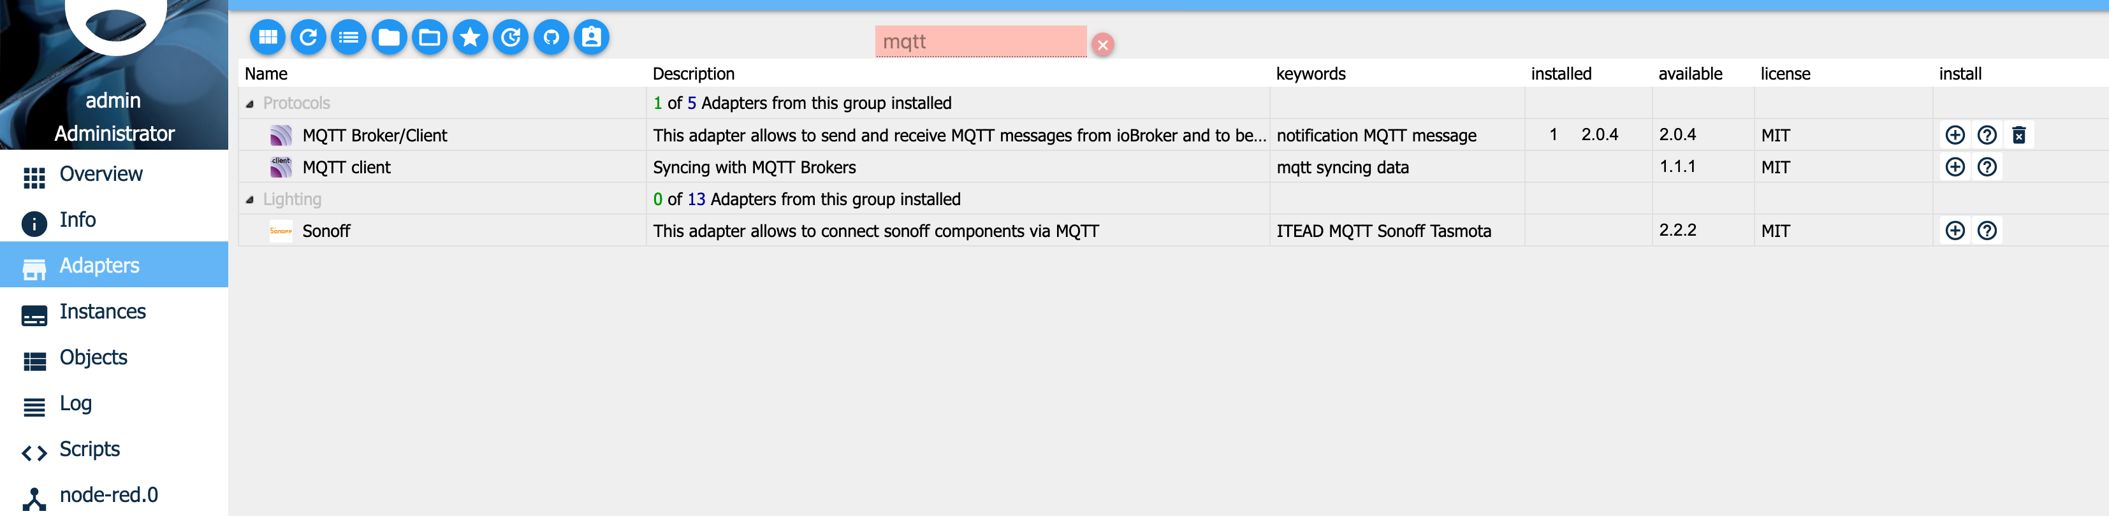
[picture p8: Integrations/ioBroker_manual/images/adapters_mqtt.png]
adapters_mqtt

2. Install the `MQTT Broker/Client` adapter with clicking the plus-symbol in the correspinding line. Wait for it to finish.

## Configuration

1. Navigate to the iobroker `Instances` menu and click on the wrench symbol for the mqtt-instance. It will most likely be called `mqtt.0`

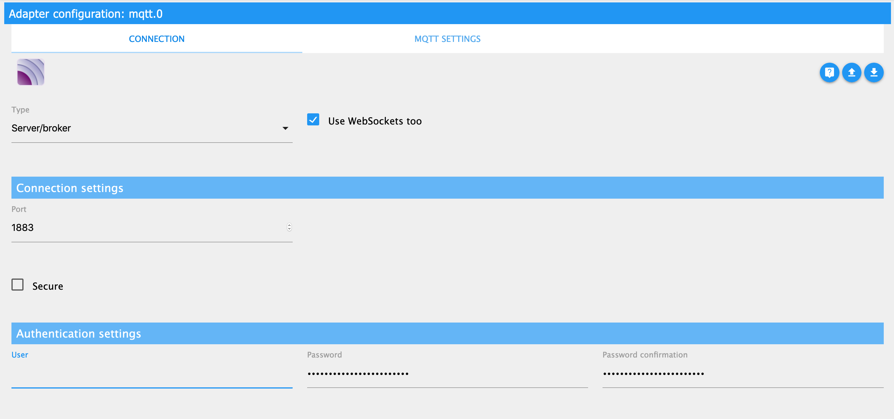
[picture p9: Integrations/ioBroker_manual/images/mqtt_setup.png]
mqtt_setup


2. Configure the Connection settings as follows:

Type: Server/Broker
Port: 1883 (default port, or chose your own)
Secure: Leave it unchecked for now until everything is set up and tested. You can activate it later.
User: Username you want your mqtt clients to authenticate with
Password: Password you want your mqtt clients to authenticate with

3. Save and close
4. At the instances menu, check if you need to activate the mqtt-instance with the play button.
5. Check if the light at the instances menu is green for mqtt. You can hover over it for more information. 

# mqtt in heishaMon

1. Log into heishamon and configure the mqtt settings at http://<<IPTOHEISHAMON>>/settings or at the setup page of the heishamon Accespoint when you install the heishamon from scratch.
2. Save and reboot

# Test
1. Go back to iobroker
2. Navigate to `objects`
3. Wait. (seriously: wait, grab a coffee or something. iobroker sometimes needs minutes to detect all incoming messages and propagate them correctly)

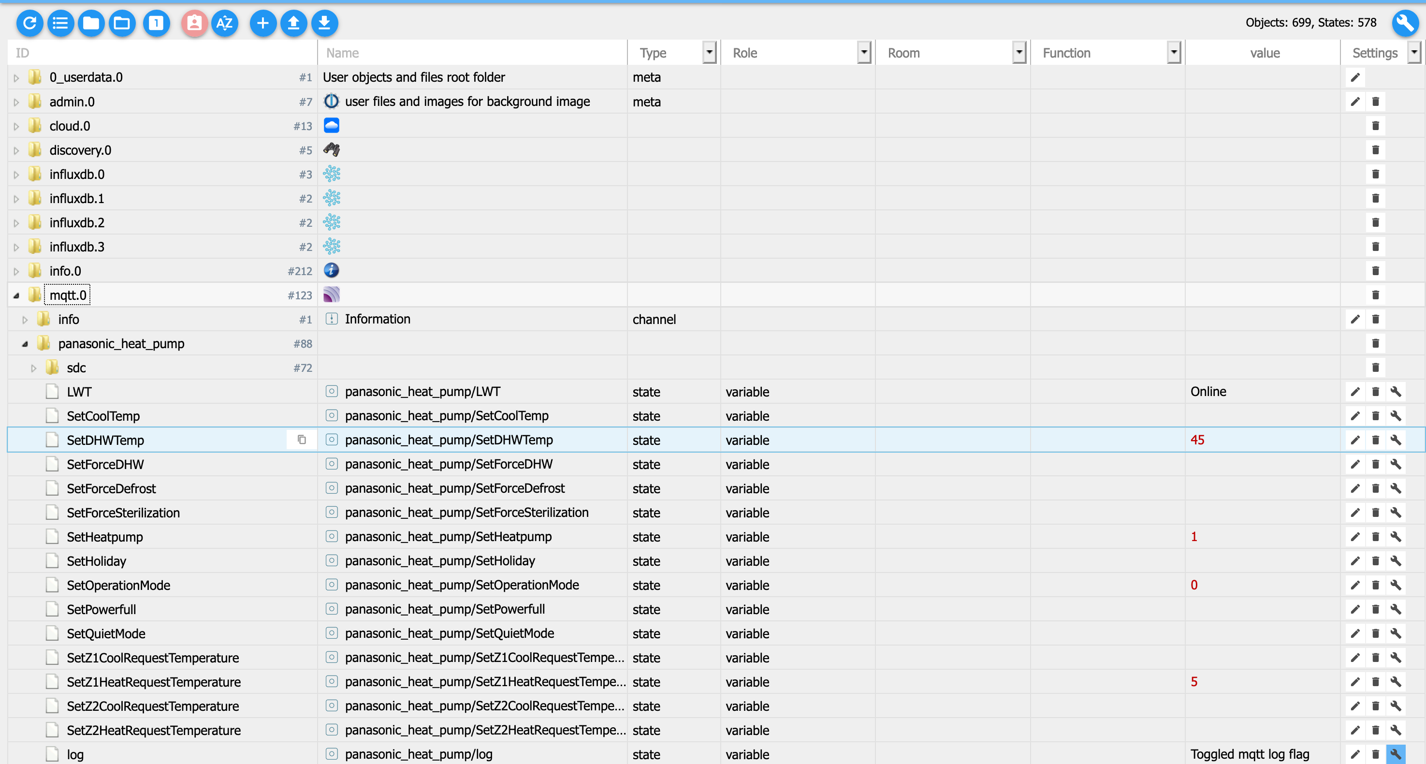
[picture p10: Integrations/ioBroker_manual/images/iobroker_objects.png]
iobroker_objects


4. When everything is setup correctly, a new group `panasonic_heat_pump` will be displayed. Under the subgroup `sdc` there already should be values coming in. They flash green when updated

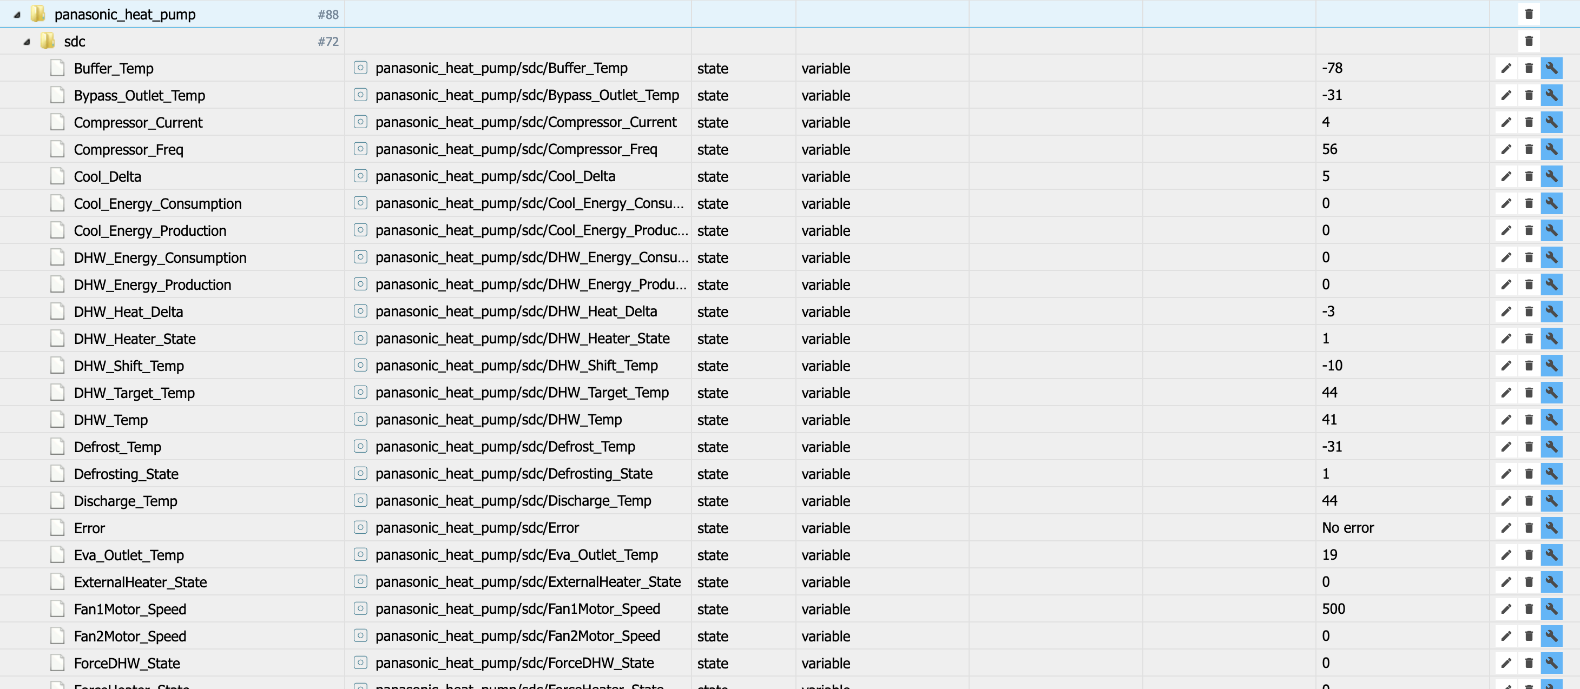
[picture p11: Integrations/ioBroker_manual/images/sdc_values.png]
sdc values


# Setting values

There are setter-topics (direct children of the `panasonic_heat_pump`). When you change the value in the `value` column, they will instantly be send to the heatpump. 
**Important: If you want to use nodered automation using the iobroker outlets for the heatpump, you need to manually set the values you want to automate manually in iobroker once. Otherwise
they will not be transmitted**

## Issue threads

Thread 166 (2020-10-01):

Service Mode

serav993, 2020-10-01:
Hey guys,

very nice project. I worked a lot with Panasonic & other Ac- oder ventilationdevices, but almost on mechanical site.
My company was one of the biggest main supporter of panasonic in northern germany. I have a lot of "hardware" knowledge, but my programming skills are only a very little bit better then my english language skills :D

Is it possible to set HP in servicemode with your programm ?
For example. Put the waterpump  "On" in service mode and set flow to a selectable value. Like you do on normal wired remote for testing or bleeding. I think with the normal panasonic cloud modul it is possible.
I build a system with Panasonic Heatpump and water-bearing wood stove as bivalent heating system.
When the stove isn't buring, the Heatpump work as a single Device.
When the wood stove burns the "indoor"modul of HP just works as a normal circulation pump. Water bearing wood stove is primary circuit and HP is secondary. system is hydraulic cuted by big buffer tank. Don't worry flow temps are limited by seperated 3-way valves.
The Problem is, the HP waterpump tries to modulate flow by pipe resitance and heat demand. For my special system it is
counterproductive and inaugural parents always turn around the thermostats.
For now i solved that, like to often, with hydraulic tricks and some self-sufficient 3 way values.
Befor I build that system, i thought the additional board solve my problem. It doen't, there was a translation mistake in the german service technican manual.
This heating system is not a normal one, but it works very efficent and cost much less then a normal bivalent heating setup.
If you can help me, i would present a pipediagram and try to explain the hole setup and its working method.
If this problem is solvable with your technics, it will be very great. That updates real "smart" home a lot.
Did you found out the byte queue commands. I don't find anything in your data.
Sorry, my english is not so good....

best regards

MiG-41, 2020-10-02:
Generaly service mode is normaly not needed to use remotly , you just set it from controller and it is enough for normal user.
Second thing ,is that is you change anything there ,HP have to be switched off - stand by ( controller also don't let you in there ,if HP is on). Service Cloud via CZ-TAW1 is doing it in this way ,that first is sending switch off command ( i belive even twice , and also wait for confirmation) and then sends the service changing command.
Generally it is possible to send it now by HeishaMon ,since there where implemented SETCommand topic ,where it was possible to put anything ,and Heishamon just send it to HP.
Also a command it self is a question of making logs from CZ-TAW1 when sending this command from SmartCloud.( the easiest way).
So yes , something is possible, you have to publish first SetHeatpump=0 ,to be sure that HP is off , and then logged command.

IgorYbema, 2020-10-02:
Yes I think this is possible.
In the controller you can select service mode, max pump speed and then select the pump speed and turn the pump on or off.
I guess this is possible from the heishamon also. Just need to find out the correct commands now. I'll take a look into this today.

But isn't your setup easier to just have a small buffer (hydraulic neutral) between your installation and the heatpump and have a second pump which you can control yourself after this buffer to pump at your desired speed?

And yes please share your pipediagram.

MiG-41, 2020-10-02:
Just checked Servicecloud , and it is not possible to change the speed of circulating pomp , and turn it on/off from there....
There is only status ,but not active action.... ( i was pretty sure that you can. Maybe it was possible before some actualization ? ).
 So it is not possible to log the command from CZ-TAW1.... Any ideas how to find the command ?

IgorYbema, 2020-10-02:
I hope to find the commands by setting the service mode and pump speed on the controller. Probably the hexdump will show the values needed for this.

MiG-41, 2020-10-02:
Hope this works , but i belive controller have another way of communications , so in hexdump you will see only the result in answers, not the steering command it self.
Maybe a blind shoot to send something to Byte #45...

IgorYbema, 2020-10-02:
> Hope this works , but i belive controller have another way of communications , so in hexdump you will see only the result in answers, not the steering command it self.
> Maybe a blind shoot to send something to Byte 45...

I think it is indeed byte 45 together with some bits on byte 4.

serav993, 2020-10-02:
Thanks a lot. I'm going to report my progress on this.
In the next week I get some cracked boards from Panasonic Aquarea, they should work. Only optically damaged, I hope.
With resistances and some controllers I try to simulate a normal Device and try your Tipps.

IgorYbema, 2020-10-02:
I got it working!
Setting the correct bits on byte 4 allows to enter pump on in service control (you even see the controller switch to that screen :)). It even allows to do this with the pump still on ...
And changing byte 45 does indeed change the pump speed then :)

Soon in the new firmware! Already working in my system now :)

Dylantje, 2020-10-02:
Perhaps more install settings possible? [ change pumpspeed etc ]

MiG-41, 2020-10-02:
I'm not sure , if turning on/off waterflow pomp during HP is on is a good idea in real life.( for test is ok , since you are not doing it for longer time ).
Perhaps that is why this options disapear from Smartcloud...

IgorYbema, 2020-10-02:
That is why you should turn off the heatpump first I think. So the logic for the heating is disabled.

MiG-41, 2020-10-02:
Yes , but  leaving this to user can be dangerous. So maybe with on and especially off function also in byte 04 a bit to turn off HP...

IgorYbema, 2020-10-02:
Turning off the pump in service menu does not turn the pump off if it is running under normal conditions.
And I can't find a situation when turning the pump on can break anything.

Changing the max pump speed while the pump is running under normal conditions will only give a error and the system will turn off if you put the speed to low. So I don't see a reason to hide this or the block the user from doing bad stuff (which I think is impossible).

serav993, 2020-10-02:
If u turn off waterpump in normal mode, high pressure alert of cooling circuit goes on.
The systems are build very safety

MiG-41, 2020-10-03:
Yes , in Tschernobyl they also thought , that when they press the button whole reaction will stop :)

But looks like it is possible only to start waterpump , It will not stop when system will need it.

serav993, 2020-10-04:
Important is to start pump with static flow.

MiG-41, 2020-10-04:
Just tested newest @IgorYbema test version , and that works very well. In his repository it is aslo how this SET command works.
If you wont to test it just go to https://github.com/IgorYbema/HeishaMon
Sooner or later pullrequest will be made .

gregor-samosir, 2020-10-04:
Tested the set topics from @IgorYbema this evening.

- SetPump 0 / 1
If you change to 1 the service menu opens (on remconn) The Water Pump ist running with max speed. Thats what we expected. But if I change back to 0, the heat pump stays in the service menu und does go back to normal operations. Only press the left-top button (back) on the remconn, the HP operates in normal mode.

- SetPumpSpeed ??-200
It looks like we can change the max speed on the running heat pump without an stop of the HP, That's fine

What I am missing is the point to come back from SetPump from 1 -> 0 to start normal operation without need of the button press on the remconn.

But it looks like an very nice feature, very usefull on my serial system.

MiG-41, 2020-10-05:
@gregor-samosir did you tried to work "normally" after SetPump from 1 -> 0 ,even that on controller display is this config window ? I believe this inconvenience is not blocking this, and you can operate normally,  only it exist on display all the time.
Off course it will be good to find a way to quit from that,but till now it is ok . And if you want to see the disply you have to press go back button first...
Regarding SetPumpSpeed ,lowest possible value is 65 (with corresponse to 0x41 ) ,highest 255 (0xFE), and default is 151 (0x96).

gregor-samosir, 2020-10-05:
@MiG-41 Will do more tests on the point SetPump 1 -> 0 to check the normal funktion.

serav993, 2021-05-31:
Your device works like it should!!
Very Nice work thanks a lot

Closed 2020-11-27.

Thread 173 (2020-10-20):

Is 3.3V enough TX level for the Panasonic Heatpump ?

Happyboy0980, 2020-10-20:
In the schematic there is no level converter for the TX part.
This means that the heatpump only gets 3.3V as TX level.
Most proberly due to voltage drops, the heatpump get only 2.7V as TX level

Is this in all cases high enough for a stable connection ?

Egyras, 2020-10-20:
@Happyboy0980

You have issues with stable connection? When we connect device to cn-cnt its fine to have ~3.3V on TX level.

MiG-41, 2020-10-21:
Also CZ-TAW1 (at least one i have) use PL2303SA chip ,with acc to Datashet:

"Flexible signal level requirement on the RS232-like
serial port side also allows PL2303SA to connect directly to any 3.3V~1.8V range devices."

And Panasonic connected CZ-TAW1 directly to CN-CNT with 5V level....

IgorYbema, 2020-10-21:
Which schematic are you talking about? The mostly used heishamon v2 and v3 do have level shifting on rx and tx

IgorYbema, 2020-10-21:
All the schematic match level shifting design of page 12 of https://www.espressif.com/sites/default/files/documentation/esp8266_hardware_design_guidelines_en.pdf

You probably are missing the 5v pullup on the panasonic side but that is on the panasonic board already. See the schematic of the panasonic in the service manual.

Happyboy0980, 2020-10-21:
This schematic was my rev:
https://easyeda.com/igor_6537/heishamon-esp8266ex

Looking to the schematic and the picture of the pcba, and the text in the schematic, the CNT connector goes to the heatpump.
The level converter is at the extra IO lines (?)
I check the heatpump manual but couldn't find the pull up resistor but already expected it to be there.

Egyras, 2020-10-21:
@Happyboy0980 here is heatpump schematic - https://github.com/Egyras/HeishaMon/issues/1#issuecomment-562920493

Happyboy0980, 2020-10-21:
did a short deep dive, level converting is there, but it is depening on the pull up resistor and C of the heatpump if it works or not.

Text in the schematic should be different (now it is 2 times the same/incorrect..)

**TX towards the panasonic** propose **TX HeishaMon -> RX Panasonic**
**RX from the panasonic** propose **RX HeishaMon <- TX Panasonic**

Closed 2020-10-21.

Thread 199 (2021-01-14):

HeishaMon via Ethernet?

michalwoz, 2021-01-14:
I would like to talk to my Aquarea via Ethernot, not WIFI.
Is there any ready to use solution?

MiG-41, 2021-01-15:
You could try GoHeishaMon :https://github.com/lsochanowski/GoHeishaMon
Forseen to run on orginal Panasonic CZ-TAW1 module ,but you can start it on any machine (like RaspberryPi , OpenWrt router , PC with linux or Windows...), you have to made only serial conection to HP.

markuspulch, 2022-11-18:
Is it possible to run the code on esp32? Then it would be possible to use an WT32-ETH0 which has on board ethernet. I have the same issue and would like to avoid wireless connection.

IgorYbema, 2022-11-18:
Not without some code changes

markuspulch, 2022-11-18:
I was somehow expecting this ;-(
Are there many ESP8266 specific quirks in there, or should it be straightforward to adapt it to ESP32? I guess, libraries needs to be exchanged, ports needs to be adapted... But otherwise it should work, right?
Is there anything planned in this direction? Depending on wifi is somehow sub optimal if you have wifi issues. I already added an external antenna to your board, installed an access-point in the same room (ubiquiti) but still fighting with re-connect issues. A simple LAN connection would just solve the issue...

geduxas, 2022-11-18:
It's writen in arduino.. i think it should run fine on different hardware.. and yes ethernet part will be missing..  just try to compile in arduino for esp32 and you will find out :)

ddokupil, 2023-01-23:
Has anyone tried it already? ESP8266 is very unreliable, at least in my network infrastructure. I always had connectivity problems regardless of if it was ESPHome, Adrduino project or HeishaMon. Can't tell if it's due to AiMesh, Asus WRT or something else. My mesh node is like 1m away from my ESP8266 and still breaks connection every once in a while. I have no such problems with ESP32, it doesn't even need to be connected via ethernet.

ddokupil, 2023-01-26:
First of all it needs esp8266wifi.h  changed to wifi.h everywhere (would need to use directives), than there is DoubleResetDetect which may not work as expected on esp32, #include ESP8266WiFiGratuitous.h needs to be taken care of (not sure what it does and is it needed on ESP32) and that's just a beggining. I ended up with a wall of errors for now. Porting it to ESPHome would be awesome and it might turn out to be euqally troublesome. There is also a GoHeishaMon project that does the same but it's abandoned and lacking some of less common functionalities.

geduxas, 2023-01-26:
Also there is code which modifies Panasonic taw adapter to run heishamon.. so it's possible to have wired Heishamon..

ddokupil, 2023-01-26:
> Also there is code which modifies Panasonic taw adapter to run heishamon.. so it's possible to have wired Heishamon..

GoHeishaMon

MiG-41, 2023-01-27:
@ddokupil  ,you can ty fork of GOHeishaMon by rondoval : https://github.com/rondoval/GoHeishaMon
He is doing update frequently following Heishamon project , since @lsochanowski don't have Aquarea anymore , and is lest interested to make updates...

eldrik, 2023-10-20:
I fiddled the last days getting a w5100 Ethernet shield connected to an esp8266 and after some code changes (mostly on changing the serial switch to gpio 13 & 15 because Ethernet shield needs 12 13 14 & 16 for spi communication), it is running fine with Ethernet connected the Webserver is reachable and Mqtt connections working.

The wifi ap is also working thus I did not tested it if both interfaces connected to the home network will cause any trouble or high cpu.

There are already the needed lwip expansions in esp 3.02 included for w5500, w5100 & encj.. Ethernet interfaces) so the changes are not really that big and mostly done in Heishamon.ino

on the other side because of the needed extra gpios some Heishamon features can‘t be used openthern for example.

SirIcy, 2023-11-09:
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

Could you please share your solution. Do you have a fork?

eldrik, 2023-11-09:
yeah I created a fork https://github.com/eldrik/HeishaMonEth with binaries for W5100 & W5500 Shields.

Regard the readme when it comes to available gpios & functions.

HighlyCompressedAir, 2024-09-11:
Implemented in #501
This issue can be closed.

Closed 2024-09-12.

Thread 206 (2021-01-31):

GPIO15 - Wemos D1 unable to boot

DamianBroj, 2021-01-31:
Hi, i have just flashed heishamon on my wemos D1, plugged a level shifting to match voltages with heat pump and got a problem with GPIO15. Having it connected to level shifting part making boot not possible because of its state. Is there any way how to force GPIO15 not active on boot and after a while to turn it on? Any ideas, workarounds?

gregor-samosir, 2021-01-31:
Have you looked at the pcb design page?
https://github.com/Egyras/HeishaMon/blob/master/PCB_Designs.md

DamianBroj, 2021-01-31:
Yes, i did. However I built my own using external level shifting module like that: https://wiki.liutyi.info/plugins/servlet/mobile?contentId=30507610#content/view/30507610

5v, 3.3v and gnd are taken from Wemos. LV side to Wemos GPIO15/13, HV to cnt socket TX/RX.

Any idea how to make it working?

By the way- why the built in TX/RX Wemos pins are not used but there is a serial switch done?

MiG-41, 2021-01-31:
GPIO15 during boot have to be low. Otherwise it searching for SD card.  So GPIO5  during boot gives low to GPIO5  ,and after starts up connect it to RX of HP.

IgorYbema, 2021-01-31:
Reason why original tx/rx isn't used is because that will put out some data on the tx during boot and that can 'break' the heatpump.
So after boot we swap to GPIO15 and GPIO13 and enable the levelshifters with GPIO5.

IgorYbema, 2021-01-31:
Another reason was because some wemos (cheap chinese ones) have the usb connector connected with wrong resitor causing errors on the tx/rx to panasonic.

IgorYbema, 2021-01-31:
Check https://www.espressif.com/sites/default/files/documentation/esp8266_hardware_design_guidelines_en.pdf at page 12 and see if you can change your levelshifter to match that configuration

IgorYbema, 2021-01-31:
And if you want, just remove the lines https://github.com/IgorYbema/HeishaMon/blob/main/HeishaMon/HeishaMon.ino#L409 line 409 to 412. Check if it works for you with the normal tx/rx

DamianBroj, 2021-01-31:
> GPIO15 during boot have to be low. Otherwise it searching for SD card. So GPIO5 during boot gives low to GPIO15 ,and after starts up connect GPIO15 to RX of HP.

Looking at your reply and the esp documentation i understand that it would be the solution to connect GND-GPIO5-GPIO15 and that would pass gnd line for boot giving GPIO15 low state and after boot will close connection of GPIO15 to gnd letting it to work normally? If so then is that a built in behaviour of GPIO5 or need to be coded?

IgorYbema, 2021-01-31:
I am not sure if I understand your explanation. But the GPIO5 solution must be in the code (and it is in the heishamon code, see https://github.com/IgorYbema/HeishaMon/blob/main/HeishaMon/HeishaMon.ino#L418).
Before/during boot GPIO5 is low and that blocks the mosfet/levelshifter. So GPIO15 stays low. After boot GPIO5 is pulled high, which closes the mosfet and allowing GPIO15 to talk to the heatpump (which pulls it high).

You can see a simple wemos shield design for this: https://easyeda.com/igor_6537/panasonic-cn-cnt-to-wemos

supersjimmie, 2021-02-01:
Are you sure those schematich are correct?
I see that for both directions, the Source is connected to the ESP-GPIO and the Drain is connected to the HP?
I mean, since they communicate in different direction, shouldn't one be in the other direction?

IgorYbema, 2021-02-01:
Correct :)

IgorYbema, 2021-02-01:
See a nice video about it https://www.youtube.com/watch?v=FwdwzMTmcsU

DamianBroj, 2021-02-01:
@IgorYbema - i missed the circuit between GPIO5 that controlls mosfet . Basically i have followed the first PCB design (the one with through-hole soldering) and changed the external lever shifter with the whole part of the board designed by you there.

@supersjimmie - the shifter is bi directional so no issue here. it just would need one additional circuit that would not let GPIO15 to go high on boot, as @IgorYbema described well in his schemas.

Is there any particular order of moves to connect HM to HP? should the pump be switched off -> connecting HM -> switching  HP on -> switching HM on?

Another thing is that when i tried to trigger the HomeAssistant switches it prompted me that the command is not correct, any experience with the similar?

IgorYbema, 2021-02-01:
Heishamon can be plug in at any time. Actually I almost do that daily on new heishamon tests while heatpump is running :)

About HomeAssisant, I got no clue for you. I am not a HA user myself. But you can always join our slack channel and ask it there. See slack channel details on top of readme of github page.

supersjimmie, 2021-02-01:
I'm currently running heishamon on a breadboard and plugging it in/out many times while the HP is running.
The only thing to keep in mind is that there might be some setting waiting in your mqtt that is sent to the HP as soon as you connect heishamon (gave me some strange behaviour last time).

I am using Home Assistant and used many fixes from this https://pastecode.io/s/96F1nsvMj4

DamianBroj, 2021-02-01:
Great! will report here effect once i'll find few mins to test it then. Thanks guys for your support!

@IgorYbema as you are here the main designer of different PCBs- here's an idea for all of those who would like to build HM even easier not going into too much soldering: based on my case the only one missing element to complete HM even on the prototype breadboard is a circuit between GPIO5, NPN and GPIO15. the rest can be just bought for few $ and plugged with pin cables. So that would be a nice additional way of building HM without even a soldering iron :)

IgorYbema, 2021-02-01:
@DamianBroj How do you think I got started :-) But eventually running on a breadboard still gave me too much errors (due to breadboard resistance/capacitance buildup etc).
I still have some wemos shields (with extra connectors for s0 and 1wire) laying around. But I noticed people just wanted the complete new board so I am not selling them anymore. They where damn cheap (only shipping price was higher) so people didn't want to make it themselves.

DamianBroj, 2021-02-01:
the case is that 20$/EUR is about nothing and that is the price for the complete build up. But shipping even across europe makes it doubled and this becomes nearly 50% of the original Panasonic device- not attractive at least for me :) if i would not build the PCB i would go for the Panasonic TAW

IgorYbema, 2021-02-01:
And that's why it is open source so you can make it yourself :)

MiG-41, 2021-02-01:
Still this one is the simplest way : Wemos Panasonic Aquarea CN-CNT shield through whole.png
Worked some months on spider soldered directly on NodeMCU

gregor-samosir, 2021-02-01:
Ordering and buying the finished circuit board from one of the developers is also something of a recognition of the work done on this project.

IgorYbema, 2021-02-05:
Can you close the issue?

Closed 2021-02-06.

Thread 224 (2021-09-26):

Feature request: Provide signal for deicing active

trsqr, 2021-09-26:
The J-generation pumps have support for providing a signal when the deicing is active. This is handy if you have to implement extra heating cables for keeping the drain pipes unfrozen. With the deicing signal it's possible to heat the drain pipes only during and a bit after when deicing is active instead of keeping the heating on constantly when it's cold.

H-generation pumps do not have this. Would it be possible to implement such functionality in HeishaMon? For example, if one of the S0 interfaces is not used, maybe one could be configured for this purpose?

PGnl, 2021-09-26:
Why include it. If you notice a deicing, use a smart switch via domoticz/HA or any other to activate the heating element/cables.
This can easily be scripted. Myself would prefer not to include it in heisha. That is what HA/Domoticz is for.

MiG-41, 2021-09-26:
@trsqr in regards of heating cable ,in booth H an J series there is a function Base Pan Heater , and corelated with this connector on Outdoor unit PCB , with switches 230V acc to function Type A or B.
Next thing ,as @PGnl mention , there is a TOP26 Defrosting State , with can be easly inplement for devices as Sonoff or Shelly 1 to turn on/off.

trsqr, 2021-09-26:
@MiG-41 I'm aware of the base pan heater and I have one in my unit (it's more or less mandatory here in the north). However, to lead out the water from the unit to the sewer that's well below the ground (frost depth is something like 1.2 meters here) I need to use a pipe that has some heating - otherwise it freezes. Panasonic specifically says not to connect anything more than the base pan heater to the connector (risk of pulling too much current). In J generation units the Boiler Contact serves also as Deice Signal (if configured in the menus), in H generation this does not exist (I own both a H and J gen units).

J-gen install manual:
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

I know that I could implement that using a wifi socket and HA. The issue is that then my system will require that HeishaMon is up and running, my home server is up and running, that the WiFi actually works and that the WiFi socket is up and running. 4 devices and failure of any of them will result in no defrosting. If HeishaMon would provide the signal to a simple relay/contactor I would only have 2 devices and the relays I consider very reliable.

I know that another option is to feed the relay from the base pan heater connector inside the outside unit, but I'd prefer not to touch the insides of the machine while it's still under warranty...

PGnl, 2021-09-26:
Connecting a relay to the base pan heater connector should not void the warranty.
That would be far cleaner than the heisha doing it. Then only one failure point.
Much cleaner.

Closed 2023-11-28.

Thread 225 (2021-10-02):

Question: Knowledge about which parameters end up in lifetime-limited non-volatile storage in heatpump?

NerdyProjects, 2021-10-02:
Hey there,

thanks a lot for HeishaMon! I am considering using this or at least the decoded protocol information for my own aquarea automation/monitoring solution.

Thinking about automation, especially maximising solar usage, I wonder which parameters are safe to be controlled every few minutes?

A lot of the parameters should be stored in non-volatile storage in the heatpump (e.g. EEPROM or flash) that has limited write cycles (for example 10000 to 100000 for an EEPROM) - If I do one write every hour, the eeprom cell would be broken after a bit more than 10 years (for 100000 writes - if it only lasts 10k, it's just over 1 year).

I am wondering especially about everything that changes heating curves (as is done in the "smart controller" every few minutes) or temperature offsets - I wonder if not the SG signals should be used for that instead.

I guess there is also no long-term experience, e.g. somebody who already did more than 10000 writes to any of those parameters?

IgorYbema, 2021-10-03:
I guess no one can give you an answer about this. Interesting question. Would make a special support case at panasonic as long you have warranty :)

michalwoz, 2021-10-03:
@NerdyProjects I'm at the same point as you are. Have you considered using demand control? Originally it is 0-10V, but everything says it can be emulated. I think that it should be designed to allow changing demand with not limited frequency. At least from potential flash/EEPROM point of view. Of course changing demand 0%,100%,0%,100% etc, doesn't make any sense and will be very bad for compressor, but I can imagine some algorithm which makes +5%,-3%, +2% adjustments every 15 minutes.

MiG-41, 2021-10-04:
@michalwoz ,Demand Control only sounds good , but in reality you will be not able to conrol anything . It work in special way , what we find out ,it has influence on Compressor current. In my case minimum set 5% limiting it to 3A. But 3A it is a lot in normal conditions ( let say around 0) , something like 40Hz in my case.  In many situations you will find , that this Demand Control do nothing....  Limiting Demand Control to 5% behaving more/less like to set Quiet Mode 3.

NerdyProjects, 2021-10-04:
In addition to demand control there is the SG signals. As I don't have the heatpump yet, I don't know exactly how they will behave and how quick the heatpump will react - I understood it so you can set two temperature factors (SG1 and SG2) from 0.5 .. 1.5 that will be multiplied with the currently requested temperatures. This _should_ be enough to minimize/maximize power consumption, no? In my opinion, this should be a good enough start to e.g. maximize heating power from lunch till afternoon while there is enough power or minimize power in summer for hot water operation while there is peaks of other demand.

Maybe even the (limited, I know) demand control is good enough for that. Very nice that the parameter set is known to heishamon now. I wonder, if I should cancel my optional PCB/buffer sensor order as I think it is much more useful to do it with the optional PCB emulation :-)

MiG-41, 2021-10-04:
Correct ,SG works in this way. But having Heishamon it is easier to set temperatures in direct way , not puting signals and let the HP to do the mathematic recalculation .
Ofcourse writting a lot of changing temperatures can influence on eeprom , if you do it to often...

NerdyProjects, 2021-10-04:
Well, you can set SG with the optional pcb emulation, so it stays all digital :-)

NerdyProjects, 2021-10-11:
Although this is not an issue, I think it is something users should be aware about. Would be sad to have the heatpump fail due to irresponsible writes by some home automation software... Where would it fit better? I guess by default only everything that happens through the optional PCB can be seen as "safe"...

CurlyMoo, 2021-12-11:
I don't quite see what controller values should be stored in an EEPROM or Flash. The statistics of the device itself maybe, and the settings are probably stored in an EEPROM or Flash, but why should the controlling parameters be stored there?

There is absolutely no use for it. Every decision of the heatpump is based on a sensor measurement. These sensor values can be measured in realtime when the device turns back on after being shutdown. The same counts for all decisions based on those measurements. So, i really don't think there is an issue here.

MiG-41, 2021-12-14:
By Set Commands users can change parameters like:
-Max Water pump flow
-Parameters each of 4 Heating and Cooling Curves
- Mode
- Temperatures for zones
- temperature for DHW
- And generally all parameters with can be presset/changes.
Personally i hae automaions for two first parameters , with automation sets when some conitions apear.
Having in mind limit of operations for EEPROM , it is good to amount of writes  would be not higher then 50 per day ( HP for lifetime 20 years).
That is why ,from one side good to be responsible and know ,that there is a limit in set commands , from other it woul be greatto find out how this parameters are being storaged ( becouse they are no changed after energy failure).
Maybe Panasonic have protection for it ,and there is nothing to worry , but how to be sure ?

Celphor, 2023-12-09:
I once noticed a strange behavior, when operating cycles and hours went back to older values. I don't rememer what I've done, maybe a reset because of frequent cyling. So it seems not every set value is written to the eeprom immediately. Maybe only after a few minutes from RAM to EEPROM. Look at the graph
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

MiG-41, 2023-12-09:
...or first sympthoms of broken EEPROM ...

Celphor, 2023-12-09:
I don't think so, this happened 2 months ago and never showed up again

Celphor, 2023-12-09:
Does anybody know the model of the used flash chip? On my indoor unit i can't locate one on the frontside. Don't know if the board is double sided. If the model is known the spec should provide info about number of writes per cell.

MiG-41, 2023-12-09:
Had a picture of my PCB on back side ( yes it is doublesided) , main CPU and surrounded chip (could be EEPROM) is wihout markings , and also glued with some siliconlike thing.

Celphor, 2023-12-09:
If it really fails: The boards are not that expensive, <400€. Maybe I should keep one in stock ^^

edterbak, 2024-09-03:
I just read an issue report that my node red flow will in fact as a certainty kill the eeprom on the panasonics...   _(nice report)_

I have developed the node red flow, and in the beginning I probably flooded my pump with set commands. (Imagine 1 cmd per minute for weeks)

Is there a way to get some sort of reading on the health state of the EEPROM?

Typically the node red flow produces the following amount of set commands per day:
low: 0-10
normal: 20-40
high: 80-150*
*The high scenario only applies when a user has enabled all my custom functions and have set it up that it reacts a bit nervous / jumpy.

FYI.
I personally do not have an issue so far. I have no indication of a problem yet.
My pump is installed in jan-2021.
If I were to make an estimate on how many commands have been sent to my pump, I would guess 250k+ at least.
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
edterbak, 2024-09-21:
Finally had time to do some testing. This is the result

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

IgorYbema, 2024-09-21:
So yeah, these will have been written to eeprom somehow. Could be smart (only writing when power is down, using some rest over condensator power) but probably not.
Should I builtin a limit of about 100 commands per day (which will be way enough for normal practice and will probably never cause any eeprom issue)? And ofcourse an option to change/disable this limit.

HighlyCompressedAir, 2024-09-21:
> So yeah, these will have been written to eeprom somehow. Could be smart (only writing when power is down, using some rest over condensator power) but probably not. Should I builtin a limit of about 100 commands per day (which will be way enough for normal practice and will probably never cause any eeprom issue)? And ofcourse an option to change/disable this limit.

I think a warning is enough.
But I remembered something, maybe you can explain it. I have set Pool Temp to 27 a few days ago when I tested optional pcb commands. In the mean time I powered off my pump a few times and the value is still 27. When I connect just the CZ-TAW1, it reads -78. And then when I disconnect it and connect Heishamon again, the reading goes back to 27 which suggests that it is stored somewhere in Heishamon's memory. How is that possible? After an hour without power?

geduxas, 2024-09-21:
@HighlyCompressedAir it's depends how you set commands to heishamon, if it's over mqtt it could be that it has retained flag (which stores value in mqtt server)
Also heishamon stores it while it's running.. if you somehow not disconnected it from power supply, it could be left in memory

geduxas, 2024-09-21:
> So yeah, these will have been written to eeprom somehow. Could be smart (only writing when power is down, using some rest over condensator power) but probably not. Should I builtin a limit of about 100 commands per day (which will be way enough for normal practice and will probably never cause any eeprom issue)? And ofcourse an option to change/disable this limit.

How about other communication methods? It has knx and Modbus interface, and didn't see anywhere about limit's in documentation, or naturally from them will not be any flood?

edterbak, 2024-09-21:
Yeah, review the method how I did this might be wise.
Is the result trustworthy.

I do see retain flag when I open MQTT explorer on these values. So I dont know what happens when power is restored to the pump. Does Heishamon do anything at that moment, or the broker.. Truly I dont know.

HighlyCompressedAir, 2024-09-21:
With mqtt server powered off it's the same thing. I just switched the breaker to power off my pump, waited 5 minutes and powered it up again - Pool Temp is still 27. Heishamon doesn't have external power connected so it has to hold charge somehow.

geduxas, 2024-09-21:
> With mqtt server powered off it's the same thing. I just switched the breaker to power off my pump, waited 5 minutes and powered it up again - Pool Temp is still 27. Heishamon doesn't have external power connected so it has to hold charge somehow.

Indeed optional PCB stores it's data once in 5min. I have missed that :)

edterbak, 2024-09-21:
> So yeah, these will have been written to eeprom somehow. Could be smart (only writing when power is down, using some rest over condensator power) but probably not. Should I builtin a limit of about 100 commands per day (which will be way enough for normal practice and will probably never cause any eeprom issue)? And ofcourse an option to change/disable this limit.

In the node red dashboard, I have a setting like this:
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

In the code, I have the default limit to 500 a day.
This is only reached in case of an programming error. looping stuff. Then the failsafe kicks in.

Maybe you can use this as inspiration

geduxas, 2024-10-26:
Ik we have one user who have cascade controller with Modbus, and he claims that cascade controller updates/changes registers every 20-30 sec. So if it works in official setup, maybe there is not so much problems?

edterbak, 2024-11-02:
> Ik we have one user who have cascade controller with Modbus, and he claims that cascade controller updates/changes registers every 20-30 sec. So if it works in official setup, maybe there is not so much problems?

I hope this is true. That would take away our worry and we can release any restrictions. :)
For now we dont know for sure yet. So caution should apply of course.

geduxas, 2024-11-02:
https://github.com/Egyras/HeishaMon/discussions/565#discussioncomment-11062501

Closed 2024-09-12.

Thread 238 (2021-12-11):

How much correct received data should i expect?

kr0815, 2021-12-11:
I installed a WH-MDC07J3E5 the last days - now trying to get heishamon working

I received some values the last days, but correct received data was always low - about 2-4%

Today i played with some settings in the heat pump - now heishamon stopped working completely

Should the correct received data be in a range from 1-5% or in a range of 98 - 100%?
Did Panasonic change something in the protocol

I use a premade PCB from TheHog

This is what i get:

`Received 194 bytes data
Received bad header. Ignoring this data!
Received more data than header suggests! Ignoring this as this is bad data.
data: 71 71 97 99 00 00 80 00 00 00 00 00 00 00 00 80 85 15 8A 85 85 D0 7B F8 7E 1F 1F 79 79 8D 8D B0
data: A3 7B BE DD FD F7 95 85 80 8F C5 94 9E 8F 8A 94 9E 85 8F 8A 11 3D 78 C1 0B 7E 7C 1F 7C 7E 00 00
data: 00 B9 E5 95 21 87 15 59 05 23 12 65 00 00 00 00 00 00 00 00 C2 D3 0B 34 65 B2 D3 0B 95 65 AD 00
data: 00 83 A8 AD 32 32 B0 A3 32 32 32 B0 B0 AD D3 96 A8 7A 61 7C 37 9A 96 01 3B 44 00 00 31 19 93 97
data: 48 01 3C 79 01 01 2C 00 00 15 00 00 01 00
Received bad header. Ignoring this data!
data: 00
Received bad header. Ignoring this data`

trsqr, 2021-12-11:
Should be close to 100%. I've got a J-gen 5kW split unit here and "Correct received data: 99.83%".

kr0815, 2021-12-11:
It is totally strange - now i received this, so wiring is correct

I can´t imagine that at 9600Baud running the data cable next to the power cable for 25 centimeters makes such problems?

`received 203 bytes data
data: 71 C8 01 10 56 55 52 49 00 55 00 01 00 00 00 00 00 00 00 00 59 15 11 55 55 15 55 55 56 19 00 00
data: 00 00 00 00 00 00 B0 80 A3 80 B4 71 71 97 99 00 00 00 00 00 00 00 00 00 00 00 80 85 15 8A 85 85
data: D0 7B 78 1F 7E 1F 1F 79 79 8D 8D B0 A3 7B 8F A3 A3 7B 8F 95 85 80 8F 8A 94 9E 8F 8A 94 9E 85 8F
data: 8A 11 3D 78 C1 0B 7E 7C 1F 7C 7E 00 00 00 55 55 55 21 87 15 59 05 24 12 65 00 00 00 00 00 00 00
data: 00 C2 D3 0B 34 65 B2 D3 0B 95 65 AB 00 00 83 A5 AB 32 32 B0 A3 32 32 32 B0 B0 AB CB 96 A6 7D 61
data: 7E 37 9A 8D 01 3A 45 00 00 1F 18 4A 93 49 01 41 79 01 01 2E 00 00 15 00 00 01 00 00 01 00 00 08
data: 01 0E 32 01 01 01 01 02 00 00 F5
Checksum and header received ok!
received TOP1 Pump_Flow: 24.12
received TOP6 Main_Outlet_Temp: 43
received TOP8 Compressor_Freq: 68`

MiG-41, 2021-12-11:
If you have monoblock , and using 25cm cable i assume that HeishaMon is outside inside the metal cover of HP... What is your wifi signal strength? And if it is not above 65 try to improve it.

kr0815, 2021-12-11:
The Heishamon PCB is inside the House - but the Data Cable runs trough the same hole as the Power Cable

If i look at the "wrong" data - without understanding which Byte is what - it´s always the same - so i think it can´t be a distortion from the power cable?

MiG-41, 2021-12-11:
Ok , 25cm is the distance from power cable , not th length it self...

You can try modbus in the middle connection as here:
https://github.com/IgorYbema/HeishaMon

Should be more resistant for intereferences on longer distances.

kr0815, 2021-12-11:
no, sorry, the cable is about 2,5 meters long
Heishamon PCB sits inside the house
Only where the cable goes trough the wall it runs in the same hole as the power cable

Even more strange - now i get fancy Power / S0 Readings - up to 40 KWh which is impossible at a 16A Fuse

i think something is wrong with the PCB...

kr0815, 2021-12-12:
in the end i build a new PCB- works like expected now

IgorYbema, 2022-01-02:
> in the end i build a new PCB- works like expected now

Can you contact me on the order confirm email I have sent you from the Tindie shop?

eigthyeight, 2022-01-30:
Instead of opening a new issue, I have the same issue.
Installed my Heishamon today with a 5m cable (from the tindy shop) (it is now in an enclosure next to the HP so 2m would also have been enough)

I get a Correct received data rate from 1 - 15%....
wifi is in the range of 100-66%, does not seem to make a difference

updated fw to 'HeishaMon.ino.d1-v2.2-iy-1' but no effect

data looks like

```
data: B4
Received 116 bytes data
data: 71 71 97 99 00 00 00 00 00 00 00 00 00 00 00 80 85 15 8A 85 85 D0 7B 78 1F 7E 1F 1F 79 79 8D 8D
data: 99 A3 7B 8F A3 A3 7B 8F 98 85 7C 8F 8A 94 9E 8F 8A 94 9E 85 8F 8A 11 3D 78 C1 0B 7E 7C 0B 7B 7E
data: 00 00 00 55 55 55 21 87 15 55 05 14 12 65 00 00 00 00 00 00 00 00 C2 D3 0B 35 65 B2 D3 0B 96 65
data: 91 00 00 87 91 91 32 32 99 A3 32 32 32 99 99 91 88 88 8A 85
Checksum received false!
Requesting new 1wire temperatures

```

any ideas to a solution?

IgorYbema, 2022-01-30:
Can you test with this development binary? https://github.com/IgorYbema/HeishaMon/actions/runs/1730932765 see artifacts
The bad data was calculated wrong. 1% was actually like 10-20%.

Do you use s0 kWh meter? I had some customers with a specific kWh meter which caused a lot of noise on the GND of the heishamon causing these errors. They connected the negative side (GND side on S0 heishamon connector) to the metal chassis of the heatpump creating extra grounding. That helped a lot with these issue's.

If this all doesn't help, contact me back using the tindie contact.

geduxas, 2022-01-30:
> Do you use s0 kWh meter? I had some customers with a specific kWh meter which caused a lot of noise on the GND of the heishamon causing these errors. They connected the negative side (GND side on S0 heishamon connector) to the metal chassis of the heatpump creating extra grounding. That helped a lot with these issue's.
>
> If this all doesn't help, contact me back using the tindie contact.

Hmm.. could you explain More about that? I still can't read S0 from my meater. If you remember me, i have successfully read S0 only while i have attached oscilloscope on heishamon contact's.. maybe it's same grounding problem's? Do i need to ground negative contact on meter side?

IgorYbema, 2022-01-30:
Yes that is what I was told by these customers. But probably grounding the GND of the S0 contact (same cable) should work also.
I believe that somehow there is a ground loop causing too much noise on the S0 connector.

But there are also some other kWh meters with different problems. It seems that not all kWh meters use same S0 logic and it is hard to make hardware for it that matches all brands.

mitchellengelage, 2022-03-29:
Having the same issue, 0-1% Correct data. Ran an extra wire from GND tot HP chassis, same result. Disconnected s0 meters altogether, ~30% correct data, I have  data in Home Assistant now, but is there any solution to use the s0 meters?  COP of 6 reported from the Pana is nice, but I would like some actual data ;)
Used meters: DDS353

IgorYbema, 2022-03-29:
@mitchellengelage i'll contact you directly to check if you might have a bad pcb

mitchellengelage, 2022-04-05:
PCB has been fixed and I ran a wire from Gnd on s0 meter to actual earth point within the HP, which gave me ~80% correct data 👍

DL4JY, 2022-11-17:
Hello,
I had a few 10.000 errors with bad headers per day. iI had the optional board emulation on
However after all I took my oscilloscope I found the 5v from the Pana was very bad. Adding 2 220uf caps from both ends of the diode to ground plus a 2.2k pullup to 5v to RX solved the problems.

Mabe its worth looking a bit into voltage filtering for the next version .

cheerio

IgorYbema, 2022-11-17:
Which pcb version do you have? newer versions already have some improvement for this

DL4JY, 2022-11-18:
hello Igor,
it seems I have V1.0
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

please take into consderation that this was the first shot. And it worked. no reason to make it nice.

naseweiss01, 2023-01-18:
Hi,
with the above changes, I had still occasionally CRC & Bad header errors again. But very few.
I increased the value of the Capacitor after the diode to 2200uF.

Pleas note my wonderful artwork :-)

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

with that i have using the optional board emulation, 10m shielded CAT 6 Kabel & 30s MQTT interval no issues anymore. For days.

MiG-41, 2023-01-19:
@naseweiss01 ,in my opinion you have problems on the connection to HP, it is not solid enough (like pins not tight enough) and you red it as a bad power supply. After you unplug and plug again for somtime it is ok ,and you read it as a succesful modification...

naseweiss01, 2023-01-20:
> @naseweiss01 ,in my opinion you have problems on the connection to HP, it is not solid enough (like pins not tight enough) and you red it as a bad power supply. After you unplug and plug again for somtime it is ok ,and you read it as a succesful modification...

I can assure you, I analyzed the issue in depth. I used a digital Storage Oscilloscope at both ends.
To that comes that a friend has the same issue at H-Tcap,, too.
I am not talking about a bad power supply, its about filtering,,support Capacitors  and data-line termination / pullup resistors .
And I am admitting, I am at the limit of cable length without RS485 transmitters.
However, my unit also creates errors when directly mounted within the heatpump cabinet with a different cable - and I see the glitches on the  supply voltage. I am having a J-T-Cap.

To make it clear - I like the Heishamon, this is to make it better.

IgorYbema, 2023-01-20:
The pullup of the RX (TX from heishamon) is ok, but should not be needed as this is already on the panasonic side. However if it helps, it is ok to do.
The extra caps will help always to make a more stable power supply and if it helps for you, good find! In most cases it is not necessary but it sure can help for some situations. I see you have the opentherm v1.0 which had some issue's with tx/rx and maybe you solution helps in this case.

Closed 2024-09-12.

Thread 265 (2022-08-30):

Questions about automating all this cool stuff

gust4vsson, 2022-08-30:
Heyo, I'm planning on buying the 12kW J heat pump.

Since the electricity prices are ridiculous, I'm paying by the hour now with different prices. I use Home Assistant.

The plan is to let the heat pump heat water in buffert tanks during cheap hours, which will be pumped out on a zone according to set roomp temp, with a separate zone water pump.

During expensive hours I want to completely block the heat pump from running. But I still need the zone water pump to be running, and also the main water pump should be running after anti-freeze  conditions.

Is this possible? What command do I send to the heat pump to block it from running?

Or am I better off controlling it with the SG-Ready pins on the external pcb?

str3000, 2022-08-30:
Hello gust4vsson,
since a few weeks I have a 12kw T-CAP Super Silent heat pump.
Nearly same requirements like you, but I want to use my own solar energy.
I have a 3-way valve connected and 2 * 850l for hot water and heating. Optional pcb is installed.
Only one zone and using the embedded pump

I start with the cloud adapter and change it last week with the HeishaMon adapter and I'm absolute happy with it.

For stopping the heat pump, it exists more than one possibility.
Switching off the heat pump, hot water works fine, heater water will not work in case of water flow pump is off.
You're right.
I'm using the sg-ready and it works well. In the documentation is a max. time limit defined, but it works also longer :-)

And I can request heat pump remotely (most together with sg-ready) to user power and go over the regular set temperature.
With the heat pump I will reach 57°C in the buffer tank.
For heating water, I have an additional heating rod installed, but not used up to now.

I'm using ioBroker, but that certainly doesn't matter

Gettings

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

IgorYbema, 2022-08-30:
There is a slack link in the readme of heishamon github page. You can put your questions about this there. This issue list is for posting bugs/issues about heishamon. Can you close thise issue please?

gust4vsson, 2022-08-30:
Ah sorry for the inconvenience. Thanks.

Closed 2022-08-30.

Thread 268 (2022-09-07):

V3.0 - S0 metering stops working

Bucky2k, 2022-09-07:
Hey,

no matter what I try - enlarge the accepted pulse length range, etc - I do not get any S0 metering signals shown. With V2.0 it shows the power consumption as intended, but not with V3.0. Any hint of a possible cause? PCB is from Igor inkl. OpenTherm (but not used)

S0 meter types: 2x DRS255BC

BR

Sascha

IgorYbema, 2022-09-07:
What are your settings (screenshot please)? And if you revert to v2.0 does it work again?

Bucky2k, 2022-09-07:
Settings 2.0:
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
Settings 3.0:
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

Back to V2.0 the S0 are counting mostly fine, however some peaking of the detected watts from time to time.
DRS255BC is rated with 90ms pulse length

Bucky2k, 2022-09-07:
After a while, at 3.0, pulse quality is shown to be 0 on the active S0 (i.e. S0 2):
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

IgorYbema, 2022-09-07:
Thanks. I don't know why it isn't working. Maybe you can send some text log from the console. But you must be sure that during the log there must have been some pulses.

Maybe try swapping the two wires from the s0. But that should not change anything as it already works in v2.0. But doesn't hurt to try :-)

IgorYbema, 2022-09-07:
Got another idea. Maybe there is just too much noise received. V2.0 has other logic to filter noise. V3.0 is working differently. This is too remove those high peaks you see in v2.0 but if the noise is too much every pulse is counted as bad.
Some people reported that when grounding the meter to the chassis of the heatpump (the wire which is also connected to the gnd side of the s0 port of heishamon) fixes the noise. Others fix it by using proper shielded cable.

Bucky2k, 2022-09-07:
3.0: Noting related to S0 in the console / pulses not detected at all

2.0 (swapping S1 S2 done):

`Measured Watthour on S0 port 1: 4.00
Measured total Watthour on S0 port 1: 2542.00
Calculated Watt on S0 port 1: 1998
Measured Watthour on S0 port 1: 5.00
Measured total Watthour on S0 port 1: 2547.00
Calculated Watt on S0 port 1: 3662
Requesting new 1wire temperatures
Heishamon stats: Uptime: 0 days 0 hours 2 minutes 40 seconds ## Free memory: 74% 26920 bytes ## Wifi: 100% ## Mqtt reconnects: 1 ## Correct data: 100.00%
Requesting new panasonic data
sent bytes: 111 including checksum value: 18
Received 203 bytes data
Checksum and header received ok!
received TOP1 Pump_Flow: 15.53
received TOP8 Compressor_Freq: 41
received TOP40 DHW_Energy_Production: 5800
received TOP50 Discharge_Temp: 89
Measured Watthour on S0 port 1: 6.00
Measured total Watthour on S0 port 1: 2553.00
Calculated Watt on S0 port 1: 6091
Measured Watthour on S0 port 1: 5.00
Measured total Watthour on S0 port 1: 2558.00
Calculated Watt on S0 port 1: 17647
Requesting new 1wire temperatures
Received 1wire sensor temperature (28fae96a060000d0): 51.44
Received 1wire sensor temperature (28f3cb6a0600003d): 48.88
Heishamon stats: Uptime: 0 days 0 hours 2 minutes 50 seconds ## Free memory: 65% 23560 bytes ## Wifi: 100% ## Mqtt reconnects: 1 ## Correct data: 100.00%
Requesting new panasonic data
sent bytes: 111 including checksum value: 18
Received 203 bytes data
Checksum and header received ok!
received TOP8 Compressor_Freq: 40
received TOP49 Main_Hex_Outlet_Temp: 58
Measured Watthour on S0 port 1: 3.00
Measured total Watthour on S0 port 1: 2561.00
Calculated Watt on S0 port 1: 2224
Measured Watthour on S0 port 1: 3.00
Measured total Watthour on S0 port 1: 2564.00
Calculated Watt on S0 port 1: 2006
Requesting new 1wire temperatures
Received 1wire sensor temperature (28fae96a060000d0): 51.50
Heishamon stats: Uptime: 0 days 0 hours 3 minutes 0 seconds ## Free memory: 70% 25528 bytes ## Wifi: 100% ## Mqtt reconnects: 1 ## Correct data: 100.00%
Requesting new panasonic data
sent bytes: 111 including checksum value: 18
Received 203 bytes data
Checksum and header received ok!
received TOP1 Pump_Flow: 15.17
received TOP40 DHW_Energy_Production: 5600
Measured Watthour on S0 port 1: 4.00
Measured total Watthour on S0 port 1: 2568.00
Calculated Watt on S0 port 1: 2010
`

Bucky2k, 2022-09-07:
Cable Aquarea/Heishamon is 8m, extended with ethernet Cat6 shielded. Cable S0 to heishamon is 5m shielded telephone cable. Pulse length measured by precision Multimeter: 78 to 82 ms

Bucky2k, 2022-09-07:
There we have one of the mentioned peaks in 2.0. Are those normal in V2.0 or do they indicate a problem with noise?

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

IgorYbema, 2022-09-07:
I'll check if I can add some more debug. Weird it isn't showing anything now. I'll do that tomorrow

Bucky2k, 2022-09-07:
That would be great, thx! However, the 3.0 console shows S0 messages if I trigger the S0 manually by bridgeing the S0 connectors to GND. Due to undefined pulse length with bad pulses / low pulse quality indication. So I guess the extended cable to the aquarea could be the reason. Although it is only 8-max 10m, the cat 7 ethernet cable used for the extension does not follow your recommendation of being at least AWG24... I used a normal patch cable. So your theory of noise/bad power supply of the heishamon remains a candidate

Bucky2k, 2022-09-07:
I added a small elco / tantal to the gnd/5V pins for stabilizing the supply. While it did not solve the problem, I now get some reporting of bad pulses:

Wed Sep  7 23:00:52 2022 (376774): Pulses seen on S0 port 1: Good: 0 Bad: 72 Average good pulse width: 0
Wed Sep  7 23:00:52 2022 (376775): Measured Watthour on S0 port 1: 0.00
Wed Sep  7 23:00:52 2022 (376781): Measured total Watthour on S0 port 1: 3136.00
Wed Sep  7 23:00:52 2022 (376787): Calculated Watt on S0 port 1: 0
Wed Sep  7 23:00:52 2022 (376792): Pulses seen on S0 port 2: Good: 0 Bad: 0 Average good pulse width: 0
Wed Sep  7 23:00:52 2022 (376802): Measured Watthour on S0 port 2: 0.00
Wed Sep  7 23:00:52 2022 (376810): Measured total Watthour on S0 port 2: 399.00
Wed Sep  7 23:00:52 2022 (376815): Calculated Watt on S0 port 2: 0

So I guess before you spend more time, I will exchange the extension wire to the aquarea by an AWG24. Also, I only measure 4,7V supply voltage. Either the Aquarea is not delivering more or I have indeed a voltage drop of 0,3V due to the cable

IgorYbema, 2022-09-08:
Maybe the distance for the 5v supply is too much. You can remove the 5v
supply pin and power the heishamon externally (usb power cable), just
connect it to the gnd/5v of the dallas/temp sensor connector.

Op wo 7 sep. 2022 om 23:05 schreef Bucky2k ***@***.***>:

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

Bucky2k, 2022-09-08:
Yes, before I pull out the cable from the pipes I should try this first. However, I would use 5V/GND pins of the programming 10-pin connector. Isn't the Dallas 3.3V regulated? At least your picture on tindie suggests it:

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

IgorYbema, 2022-09-08:
Hi,
Old picture :) v3 board.
The newer (also the opentherm version you have) is 5v on the dallas pin.
Should be printed there also. But you can also use the header pins indeed

Op do 8 sep. 2022 om 09:02 schreef Bucky2k ***@***.***>:

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

Bucky2k, 2022-09-08:
Ok, separated the 5V pin from Aquarea, supplied separately via the header pins (tested both power supply + power bank incl. smoothening via elco - even more bad /no good reads. So cable should not be the primary issue...

Hmm - I guess I just order a replacement board just to be sure it's not hardware related. Shall I use tindie or can you sent me a replacement board directly (open therm) against PayPal payment?

IgorYbema, 2022-09-08:
Pretty sure it is not the board. It is working in v2.

It must be the cable which is delevering too much noise (picking up electrostatic noise). Can you try the grounding trick?

Bucky2k, 2022-09-08:
Nope, not working Aquarea is grounded by PE directly to the e-cabinet. Wired S0 GND to PE but no change.

A pity I do not have an oscilloscope. Not sure if the meters are pulling the S0 fully down. If I fake impulses by just bridging the S0 pins on the meter, the heishamons starts detecting good impulses

Bucky2k, 2022-09-08:
Maybe I try another type of meters, although I think many are using the DRS255BC. But potentially still all on 2.0

IgorYbema, 2022-09-08:
Can you try to connect the heishamon with a short cable directly to the meter? So power it again with a powerbank. Not connected to the heatpump ofcourse. But just check if it works directly with the meter.

geduxas, 2022-09-08:
Sorry for interruption, but after upgrading to V3, I have noticed that my power meter started to work :D till then I unable to get correct data.. if you remember me @IgorYbema .. also could you clarify some details for S0 configuration? And what should pulse quality be? I have 50-70%

IgorYbema, 2022-09-08:
@Bucky2k so you have reading but all bad? What are the fault messages? (maybe I do need to add more debug for that, too long ago I created that)
@geduxas I have pulse quality 99% :) .. the higher the better. If you have lower, then it is picking up noise.

Bucky2k, 2022-09-08:
The problem is, it's very different depending on the meter attached, if direct supply or from Aquarea, etc.

With independent 5V supply, no aquarea and only 20cm cable to the meters, I still have poor pulse quality:

Sep  8 14:03:55 2022 (4615660): Pulses seen on S0 port 1: Good: 9 Bad: 75 Average good pulse width: 80

On the other meter, I have more than 10000 bad pulses only after some minutes.

On the first day of use I choose wrong polarization of the S0, but this should not have hurt the GPIOs I think. But something is heavily unstable, which is why I also question the hardware just to rule this out.

Bucky2k, 2022-09-08:
I ordered the normal PCB on tindie just to be exclude it as a possible cause. And some small revenue for you considering your support time on this 😉

IgorYbema, 2022-09-08:
Noticed the order. I'll ship it tomorrow.

Bucky2k, 2022-09-12:
Hi Igor, any chance you missed flashing the new heishamon board? Received it today, comes up with AT-Thinker-... AP name instead of Heishamon after startup and no webpage accessible under 192.168.4.1...

IgorYbema, 2022-09-13:
Seems like it. Do you have cable to load it yourself?

Op ma 12 sep. 2022 23:27 schreef Bucky2k ***@***.***>:

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

Bucky2k, 2022-09-15:
End of Thread - it was indeed a hardware issue. New heishamon runs fine

Closed 2022-09-15.

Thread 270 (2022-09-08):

Feature request: Provide MQTT command for Set_Heat_State

str3000, 2022-09-08:
Hello,
I'm using SetForceDHW and it works well. I use it together with the sg-ready signals, because I have a solar roof.
The command SetForceHeater is missing.

Now the winter season is coming and I want to use the overage power from the solar panels.
I see that a parameter exist with the name:  "main/Force_Heater_State"

Is there any possibility to set heater force also ?

MiG-41, 2022-09-12:
Heater mode is somehow used as emergency mode ,when compressor fail ( and there is also option in HP to set it in this mode automatically).
This Mode can be nly turn on ,when HP is off , and when you turn on HP it disapear.
Till now no one ask to use HP in Heater mode...

str3000, 2022-09-13:
Your right,
my mistake. I will manually control the Heat mode. controlling DHW works fine with sg-ready.
But I can‘t find a way to switch Heat Pump for Heat/Room on.
I try a lot of parameter today, but no one starts heat pump.
I test with sg-ready, max power 90 min, bigger base temp
Any Idea?
Also I missing a flag if heat pump is running or not.
only indirect over power consumption.

MiG-41, 2022-09-14:
Ok , so you have CZ-NS4P , and you are using two Digital Imputs ?
Or you are doing this via Heishamon and Optional PCB Emulation ?
Anyway , HP starts heat ,when there is some requirements meet. One of them is ,that target temperature have to be higher then actual inlet temperature , and (especially at low temperatures on heatflor ) it is hard to set , becouse this difference have to be 3 or 4 degrees. Setting SG changes this target temperatures by multipling setted value.
When HP is not starting , first thing what you do is comparing target with inlet :)

str3000, 2022-09-16:
Hello yes,
I have installed the option board.
good tip with the inlet temp, I will check it.
sg signals are hardware wires.
(in future i will add power control wires 0-10V)

perhaps  Heating_Off_Outdoor_Temp
may be a problem if its sunny.

possible parameter to test:
- inlet /target
- SetPowerfulMode
- SetZ1HeatRequestTemperature

Closed 2024-09-12.

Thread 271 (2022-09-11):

V3 serial interface issues

geduxas, 2022-09-11:
I have noticed strange issue with V3.
Sometimes it's seams Panasonic is locking out from serial communication. I have 2 random issues for now, and both are after rebooting heishamon.
I have V3 PCB, , i think i am using heishamon from v1, and didn't have any issues with it. Couple days ago tried S0 settings, and rebooted heishamon from menu, after that communication with heat pump gone, from console log i got only records about reading timeout, after that tried reboot couple times, also tried factory reset and downgrade firmware (v2, v1) nothing helped. After i came home and power cycled whole heat pump unit, communication have been back. After that tried to reboot heishamon couple of times, and couldn't reproduce.. but yesterday just by accident pushed reboot button in menu, and again,  got read timeout..
I have 12kW T-CAP h series model, with additional extension card.

IgorYbema, 2022-09-11:
Do you have CZ-TAW1 in parallel (so heishamon should be in listen only mode)?
Or did you by accident turn on the optional pcb emulation mode? (as you have the extra board already you should not do this)

geduxas, 2022-09-11:
No I don't, didn't touch emulation, and Don't have cz-taw1. Panasonic just stopped responding after restarting heishamon.. i have also tried physically disconnect heishamon while that happened..

IgorYbema, 2022-09-11:
Heatpump still works and the panasonic controller also? Or do they stop also? This would be a new one for me then.

geduxas, 2022-09-11:
Everything seams works fine, truly didn't noticed that, latest issue i noticed after 9h, and dhw didn't cool down..

geduxas, 2022-09-11:
Oh yes! LCD kept responsive, i switch unit off and then i have disconnect circuit breaker

IgorYbema, 2022-09-11:
So everything on Panasonic works fine but heishamon not and you need to turn off and on the Panasonic to fix heishamon again. Weird.

geduxas, 2022-09-11:
It's happened again! I tried reboot 3 times, nothing happened, and in forth time i went in to settings menu, saved configuration, and after that hit reboot.

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

IgorYbema, 2022-09-11:
Can't understand why. If a hard reset of the heatpump is necessary to fix this it looks like an issue on the heatpump side. But proper debugging is hard for this

geduxas, 2022-09-11:
I am running heishamon >2y, didn't have any issues till this thursday.

It's seams that Panasonic lookups serial interface on reboot.. and yes only hard reset of pump solves problem

IgorYbema, 2022-09-11:
Older heishamons can have easier comms problems than the most recent design (electrical design difference on the board). Maybe you are on an edge case and due to other external reason (extra noise?) it is now only visible.
If you can reproduce it often and it really bothers you, I can send you a new one and check if it works better with the new design. At least if you got the heishamon from me (the tindie shop), then what was your order number?

geduxas, 2022-09-11:
Yes, bought cable + board. Rebooted once again without changing anything, and it's lost comuncation again..

geduxas, 2022-09-11:
Found order no in email

Tindie Order [#207935]
Aug. 5, 2020, 1:37 p.m.

Also i think I'll try downloading to v2 and try

IgorYbema, 2022-09-11:
Ok just let me know if you want me to send you a new one to test

geduxas, 2022-09-11:
Downgraded to v2, after factory reset and connect to wifi phone finds strange AP.. and it's dissapperes then i disconnect heishamon.. hashemon seams works fine.. do i need somhow special clean procedures of esp?

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

IgorYbema, 2022-09-11:
Do you have special wifi characters in your ssid or password? Seeing this with others also. A upgrade to V3 solves it. But try factory reset please. Double click on reset with 0.5 sec pause until blue led goes in steady on/off. Then reset again to start

geduxas, 2022-09-11:
Nothing special..  ok I'll stick to v2 for couple days, now reboot'ed 4 times no issues with serial.

MiG-41, 2022-09-12:
> I have 12kW T-CAP h series model, with additional extension card.

I belive her is the key , that there is CZ-NS4P in beetwen.
@geduxas ,by accident did you have enabled "Emulate optional PCB" ?

geduxas, 2022-09-12:
No I didn't enable emulation. With V2 seams no issues after reboot, will continue to test.

geduxas, 2022-09-26:
@IgorYbema still no issues with V2... could it be related to V3? or it could be board issues?

mabek, 2022-09-26:
I also have heavy issues with V3 but its hard to specify.
Overall the UI seems slow. Sometimes values do not update at all. Without factory reset no values were shown. So I think I will go back to V2 as well.

geduxas, 2022-09-26:
> I also have heavy issues with V3 but its hard to specify. Overall the UI seems slow. Sometimes values do not update at all. Without factory reset no values were shown. So I think I will go back to V2 as well.

on my case interface works ok, just after reboot panasonic lock out from serial communication..

maybe you have Wifi issues? do you get good reception?

mabek, 2022-09-26:
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

Wifi is at 100%. Can you describe what you mean with "reboot panasonic lock out from serial communication" ?

geduxas, 2022-09-26:
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

After rebooting heishamon, Panasonic heatpump stops responding to request. Disconnect heishamon Don't help.. i needed to powercycle whole heatpump unit..

mabek, 2022-09-26:
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

Thank you! After turning the power off and on again now it is as follows:

MQTT Topics working again except Heat_Energy_Production which is now always 0
Webinterface does not show any values on the main page. 1-Wire and s0 works
Webinterface still 2-3x slower than with v2

mabek, 2022-09-28:
I went back to V2 and now all my Issues are gone. Hopefully someone finds a fix for a V3.1

drschrick12, 2022-12-03:
Dears, I’ve exactly the same issue.
My board is v3 PCB and only firmware v2 is function correctly.

In firmware v3 the webinterface is very laggy and slow and over mqtt it shows online and short time later offline and then again online.

Tindie order #192596 from May 2nd, 2020.

Thank you.

geduxas, 2022-12-03:
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

How strong is your wifi? What numbers do you see in heishamon?

drschrick12, 2022-12-04:
My wifi is 76%

geduxas, 2022-12-12:
I am here again.. everything seams to work great for couple of months. Today after couple reboots heishamon stucked again.

Mon Dec 12 10:54:22 2022 (1428540): Heishamon stats: Uptime: 0 days 0 hours 23 minutes 48 seconds ## Free memory: 70% ## Heap fragmentation: 23% ## Max free block: 21112 bytes ## Free heap: 28016 bytes ## Wifi: 92% (RSSI: -54) ## Mqtt reconnects: 1 ## Correct data: 0.00%
Mon Dec 12 10:54:22 2022 (1428544): Requesting new panasonic data
Mon Dec 12 10:54:22 2022 (1428544): sent bytes: 111 including checksum value: 18
Mon Dec 12 10:54:24 2022 (1430547): Previous read data attempt failed due to timeout!
Mon Dec 12 10:54:24 2022 (1430547): Received 0 bytes data

Closed 2024-09-12.

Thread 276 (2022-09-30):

Energy Meter reset / configure signal

Revo7, 2022-09-30:
Hello, i want to ask, how to reset / delete the meter value ? from S0_1 and S0_2 sensor ? Hope it is posible ?

And i don't know but i think it's not right measure, i don't know how to configure it. I have WZE-3 energy meter. There are possible to connect Signal.

Pulse output SO + SO- open collector
Connection voltage SO + SO- max. 27 V DC
Connection current SO + SO- max. 27 mA
Pulse time SO + SO- 35 ms
Pulse: (1 Wh/imp) 1000 imp/kWh

And in the HeishaMon settings:
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
and i get PulseQuality very poor, and the Watt meter are abstract:
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

What i make wrong ? :/

Bender2k, 2022-11-18:
Hi,

i have no answer but the same question.

I installed Heishmon later than my Jeisha und therefore the energy meter already counted some hundret kWh.
I want to update the values in Heishamon so the MQTT value for the total consumption is correct.

Are there (MQTT?) commands i can send to Heishamon to change the values? Or is something like a Putty connection possible? Or an update for the Console so its possible to enter simple commands?

IgorYbema, 2022-11-18:
Heishamon picks up the last value sent to mqtt after reboot. So to reset them, turn off heishamon and send a new value to the mqtt topic (for example use mqtt explorer). Then start up heishamon, it will then pick up this new value as a start value.

Bender2k, 2022-11-18:
Oh wow. This means the Total Watthour is not saved on the Heishamon PCB?

Therefore when the MQTT connection is interruppted, even only some minutes per month, the total Watthour will be wrong again according to the energy meter?

Your project and your work ist FANTASTIC, but if this is like i understood, this feature is not very reliable. :(

MiG-41, 2022-11-18:
It is storaging in ESP memory , but if in mqtt is value ,it uses this one as actual.

Bender2k, 2022-11-18:
Yes i understood, but one example:

If the MQTT wifi connection is interrupted at TotalWatthour 3000, the Heishamon board continues counting to 3100.
After that there is a power interruption to the Heishamon PCB and everthing is connecting again, the Heishamon Value will be reset from 3100 to 3000?

IgorYbema, 2022-11-18:
Indeed, it stores in ESP flash also. But then again, it can never be always correct as it has only S0 to count pulses. It is more an indication about how much Watthour it uses. Not a high reliable solution. That is also not what it is designed for. It should use modbus then for that.
You can always sync the kWm meter value with the internal heishamon value (using the mqtt trick). But as said, it can't be correct always.

Bender2k, 2022-11-18:
Got you! Thanks.

I just dont trust Wifi and for me Wired signals (Even if it is only S0) is ten times more reliable for me.

I think i can work with your proposal and will test it!

But just take it as a improvement suggestion to make the value editable on the web interface instead of MQTT. ;)

Revo7, 2022-11-18:
Ok, so we can change or reset the value, but what with signal quality ? Could you show your config and what kind of device you use ?

Closed 2024-09-12.

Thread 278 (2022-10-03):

Set command for TOP106 Pump_Flowrate_Mode

Maarten69, 2022-10-03:
Hi, is there a set command for TOP106 Pump_Flowrate_Mode?
I can't find it on the list.

IgorYbema, 2022-10-03:
There isn't a set command yet as there isn't anyone who asked for it :) It is not something you would like to set from automation I think. But if you really want it (I can't test it, don't have J series) please test if it works.
There is a SendRawValue option which you can use to change every setting you like. For TOP106 you need to switch bit 3 and bit 4  from (binary) 01 to (binary) 10 and vice versa on byte address 29.

There is a linux command you can use. Change the 30th (byte 29) value from \x10 to \x20 and it should change it and vice versa.

echo -ne "\xf1\x6c\x01\x10\x00\x00\x00\x00\x00\x00\x00\x00\x00\x00\x00\x00\x00\x00\x00\x00\x00\x00\x00\x00\x00\x00\x00\x00\x00\x10\x00\x00\x00\x00\x00\x00\x00\x00\x00\x00\x00\x00\x00\x00\x00\x00\x00\x00\x00\x00\x00\x00\x00\x00\x00\x00\x00\x00\x00\x00\x00\x00\x00\x00\x00\x00\x00\x00\x00\x00\x00\x00\x00\x00\x00\x00\x00\x00\x00\x00\x00\x00\x00\x00\x00\x00\x00\x00\x00\x00\x00\x00\x00\x00\x00\x00\x00\x00\x00\x00\x00\x00\x00\x00\x00\x00\x00\x00\x00\x00" | mosquitto_pub -t "panasonic_heat_pump/SendRawValue" -s

MiG-41, 2022-10-03:
@boutermw ,can you explain why you need this Setfcommand ?
For me such mode is set once , and no need to change remotly , especially when the HP is running.... Or am i wrong ?
It is possible to add as many setcommands as possible , but they have to be usefull  ,not just to be becouse you can.... (ope you know what i mean). I.e. you don't need a SetCommand with sets configuration with DHW on , or off. DHW either exit and you turn it on on configuration once , or not exist and also once is off....

bluberly, 2022-11-24:
Would it technically be possible to change the pump flow rate while the heatpump is running? On the remote control it only is possible when the heatpump is off. Yes, it would be very helpful to have the ability to change it, especially in the first time after installation: control the noise different flow rates cause in the water system in the house, observe impact on efficiency.

OT: Can the heat curves be changed? How did Panasonic implement the week timers? It's so annoying they cannot be managed remotely...
Is there a mailing list to discuss such topics? Or is the issue tracker the right way?

IgorYbema, 2022-11-24:
Yes you can change it while running but it seems not to work always.
Heat curves can be changed using the setcurves (json payload) command, see readme in github. In the readme (top) you can find a link to the slack chat channel for discussions.

hacki11, 2023-03-26:
I came around also asking for this feature.
When outside temperature is getting higher (> 10°C) and the modulation gets down to 19Hz flow will also get down to 10l/min which is too less to get the heat out of the heat pump. My idea is to configure the flow mode to maximum for temperatures over 10°C dynamically. Currently I use SetPump = 1 but idk if it will make a difference.

MiG-41, 2023-03-27:
Unfortunalty HP adjust flow to its on forumla....
You can try to decrease delta , that is also one of factor.

Adusting Maximum flow speed via SetMaxPumpDuty (or in menu) will set only maximum , and HP still can have lower values.
And what is for you active ? When compressor is running , or when water pump is running ? ( Can be situation like this as well ,that compressor not run , but water pump runs , and also Heaters are on).

hacki11, 2023-03-27:
With active I mean, after setting SetPump to 1 (forcing to run at maxpumpduty) I can not afterwards read out if SetPump was set to 1 or 0 as there is no state available to read that out. This will make external control difficult.
What i want to achieve is having delta T Mode in Case of t<10°C and fix speed at t>=10°C. I want the HP to run in longer intervals but only one or two a day and the low flow rate will cause a stop as the lower Modulation is too high starting from this temperature.

MiG-41, 2023-03-27:
Please don't use SetPump when HP works !
This function is rather to check ,if water pump work ( same puropse ,like in installer menu).

You can check how SetPump works , when you turn off HP ( no green LED) , and then SetPump=1 , o to controller and see what is on display !

hacki11, 2023-03-27:
Oh, why is that? Inward using it quite a while now, ups.

hacki11, 2023-03-27:
Yeah, I thought so, too but you can't. You can not distinguish between the case where you SetPump to 1 and the case where the HP is using it at max. In both cases pump_duty is max_duty.

geduxas, 2023-03-27:
HP drives pump to keep ∆t. Yes in warm times it's pain in ... To keep pump working in efficient way... I spent whole autumn trying to graph and analyse what could i change.. but without success.. if you m find best recipe for that please share :)

MiG-41, 2023-03-27:
@hacki11 ,perhaps @IgorYbema could add a TOP for you , but in meantime you have panasonic_heat_pump/raw/data topic in mqtt , from witch you could try to get out bit 4 and 5 from byte 4 ,and you have SetPump state....

bluberly, 2023-03-27:
Hmm, my Jeisha does not reduce pump flow rate at high outside temperatures. Outlet temperature in my config is d-t controlled. My pump flow at 2400rpm is around 19.11 l/min.

What is extremely annoying for me is though I meanwhile have delta-t set to 1° for heating (was 2° and 3° before) after the heatpump turned off it doesn't turn on even when outlet/inlet temperatures is 4.5°-5° below target outlet temperature, even after many hours? Is that something I can influence?

hacki11, 2023-03-27:
With delta-t @ 1°C i doubt you will see a ramp down of the pump, for that you need to increase dT to 3K or 4K
Mine is ramping down from 16l/min (at max) to 9,8l/min (at min) with dT 5K.

This is the condition to turn it on again. It will be calculated based on the inlet temperature at the time when the heatpump turned off. Some people also say it is not -3 but 4 or 5 degree. Depending on the required heat, it could be that it will never start again. If you have a inlet temp of 25°C and you need to wait until it gets 21°C it would take pretty long i think. For such cases there exists custom solutions to do a little kickstart with heishamon rules.
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

@MiG-41 I will try decreasing dT as i already made the experience that then it will not ramp it down like @bluberly also mentioned. That should work and it is also what i want to achieve. Get more heat inside the system (lower dT) but keep the outlet temperature the same. Let's see how my hydraulics will do.

Closed 2024-09-12.

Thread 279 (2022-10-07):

Serious problem with flickering of the values with integration with HA

michalwoz, 2022-10-07:
I experienced serious issue with integration with HA on version 3.0.
I'm running default HA configuration. Tried to change heat mode and target temp. The problem is fast switching (once per second) of the value after trying to set the value. Haven't confirmed yet, but problem may occur only when value is changed fast from HA GUI. Example:

1. wanted to change target temp from 20 to 25
2. you missclicked and dropped value at 24
3. you corrected and set 25 - here the flickering begins:

There is 0 seconds or 1 second between points on X axis:
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

I'm attaching console log. As we can see we receive "set z1 heat requests" HeishaMon may actually do what it is requested for. And the problem may be HA configuration.

The same situation with setting heat mode. Actually I noticed the problem with that, when I heard 1 per second relay clicking in heat pump. I consider the issue dangerous because of 2 things: exhausting HP memory write cycles limit and frequent powering on/off hp or its components.

> Fri Oct  7 08:53:34 2022 (1278532): set z1 heat request temperature to 25
Fri Oct  7 08:53:34 2022 (1278533): sent bytes: 111 including checksum value: 249
Fri Oct  7 08:53:35 2022 (1278959): Received 203 bytes data
Fri Oct  7 08:53:35 2022 (1278960): Checksum and header received ok!
Fri Oct  7 08:53:35 2022 (1278962): received TOP7 Main_Target_Temp: 24
Fri Oct  7 08:53:35 2022 (1278967): received TOP27 Z1_Heat_Request_Temp: 24
Fri Oct  7 08:53:35 2022 (1278971): received TOP42 Z1_Water_Target_Temp: 24
Fri Oct  7 08:53:35 2022 (1279051): set z1 heat request temperature to 24
Fri Oct  7 08:53:35 2022 (1279052): sent bytes: 111 including checksum value: 250
Fri Oct  7 08:53:35 2022 (1279558): Received 203 bytes data
Fri Oct  7 08:53:35 2022 (1279559): Checksum and header received ok!
Fri Oct  7 08:53:35 2022 (1279561): received TOP7 Main_Target_Temp: 25
Fri Oct  7 08:53:35 2022 (1279566): received TOP27 Z1_Heat_Request_Temp: 25
Fri Oct  7 08:53:35 2022 (1279570): received TOP42 Z1_Water_Target_Temp: 25
Fri Oct  7 08:53:36 2022 (1280133): set z1 heat request temperature to 25
Fri Oct  7 08:53:36 2022 (1280134): sent bytes: 111 including checksum value: 249
Fri Oct  7 08:53:36 2022 (1280307): Requesting new 1wire temperatures
Fri Oct  7 08:53:37 2022 (1281024): Received 203 bytes data
Fri Oct  7 08:53:37 2022 (1281024): Checksum and header received ok!
Fri Oct  7 08:53:37 2022 (1281027): received TOP7 Main_Target_Temp: 24
Fri Oct  7 08:53:37 2022 (1281032): received TOP27 Z1_Heat_Request_Temp: 24
Fri Oct  7 08:53:37 2022 (1281035): received TOP42 Z1_Water_Target_Temp: 24
Fri Oct  7 08:53:37 2022 (1281040): received TOP64 High_Pressure: 10.0
Fri Oct  7 08:53:37 2022 (1281089): set z1 heat request temperature to 24
Fri Oct  7 08:53:37 2022 (1281090): sent bytes: 111 including checksum value: 250
Fri Oct  7 08:53:37 2022 (1281555): Received 203 bytes data
Fri Oct  7 08:53:37 2022 (1281556): Checksum and header received ok!
Fri Oct  7 08:53:37 2022 (1281558): received TOP7 Main_Target_Temp: 25
Fri Oct  7 08:53:37 2022 (1281563): received TOP27 Z1_Heat_Request_Temp: 25
Fri Oct  7 08:53:37 2022 (1281567): received TOP42 Z1_Water_Target_Temp: 25
Fri Oct  7 08:53:38 2022 (1281656): set z1 heat request temperature to 25
Fri Oct  7 08:53:38 2022 (1281657): sent bytes: 111 including checksum value: 249
Fri Oct  7 08:53:38 2022 (1282154): Received 203 bytes data
Fri Oct  7 08:53:38 2022 (1282155): Checksum and header received ok!
Fri Oct  7 08:53:38 2022 (1282157): received TOP7 Main_Target_Temp: 24
Fri Oct  7 08:53:38 2022 (1282163): received TOP27 Z1_Heat_Request_Temp: 24
Fri Oct  7 08:53:38 2022 (1282166): received TOP42 Z1_Water_Target_Temp: 24
Fri Oct  7 08:53:38 2022 (1282171): received TOP64 High_Pressure: 10.2
Fri Oct  7 08:53:38 2022 (1282226): set z1 heat request temperature to 24
Fri Oct  7 08:53:38 2022 (1282227): sent bytes: 111 including checksum value: 250
Fri Oct  7 08:53:39 2022 (1282653): Received 203 bytes data
Fri Oct  7 08:53:39 2022 (1282654): Checksum and header received ok!
Fri Oct  7 08:53:39 2022 (1282656): received TOP7 Main_Target_Temp: 25
Fri Oct  7 08:53:39 2022 (1282661): received TOP27 Z1_Heat_Request_Temp: 25
Fri Oct  7 08:53:39 2022 (1282665): received TOP42 Z1_Water_Target_Temp: 25
Fri Oct  7 08:53:39 2022 (1282722): set z1 heat request temperature to 25
Fri Oct  7 08:53:39 2022 (1282723): sent bytes: 111 including checksum value: 249
Fri Oct  7 08:53:39 2022 (1283153): Received 203 bytes data
Fri Oct  7 08:53:39 2022 (1283153): Checksum and header received ok!
Fri Oct  7 08:53:39 2022 (1283156): received TOP7 Main_Target_Temp: 24
Fri Oct  7 08:53:39 2022 (1283161): received TOP27 Z1_Heat_Request_Temp: 24
Fri Oct  7 08:53:39 2022 (1283164): received TOP42 Z1_Water_Target_Temp: 24
Fri Oct  7 08:53:39 2022 (1283251): set z1 heat request temperature to 24
Fri Oct  7 08:53:39 2022 (1283251): sent bytes: 111 including checksum value: 250
Fri Oct  7 08:53:40 2022 (1283752): Received 203 bytes data
Fri Oct  7 08:53:40 2022 (1283753): Checksum and header received ok!
Fri Oct  7 08:53:40 2022 (1283755): received TOP7 Main_Target_Temp: 25
Fri Oct  7 08:53:40 2022 (1283760): received TOP27 Z1_Heat_Request_Temp: 25
Fri Oct  7 08:53:40 2022 (1283764): received TOP42 Z1_Water_Target_Temp: 25

geduxas, 2022-10-07:
Hi, it's not related to V3.. i have same issues and from first versions.. more it is related to HA itself.. or maybe with automation rules.

michalwoz, 2022-10-07:
@geduxas No relation to HeishaMon version is with that is what I expected. Is it possible that HeishaMon sends messages with topic `panasonic_heat_pump/commands/SetZ1HeatRequestTemperature`? Or this topic may be sent only from HA?

geduxas, 2022-10-07:
Automation scripts are in heishamon.yaml already..
they purpose to listen of heishamon heat shift, and change change heat shift selector in homeassistant side.. also another trigger  is watching homeassistant slide, and triggers topic to change heat shift.. and in rarely cases it will chats 2 values and starts to flickering.. personally I don't like this kind of implementation, and I have setup mqtt climate component for that..

> @geduxas No relation to HeishaMon version is with that is what I expected. Is it possible that HeishaMon sends messages with topic `panasonic_heat_pump/commands/SetZ1HeatRequestTemperature`? Or this topic may be sent only from HA?
>
> I don't have any automations yet.

PGnl, 2022-10-07:
@geduxas
I am also investigating the mqqt climate component at the moment (just started) as I do not like the slider. Could you share your climate integration?

michalwoz, 2022-10-07:
Changes made in GUI of HA with interval of ~30+ seconds seems to be OK. Maybe 15+or even 10+ seconds is also OK.

BTW my config:
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

geduxas, 2022-10-07:
> @geduxas I am also investigating the mqqt climate component at the moment (just started) as I do not like the slider. Could you share your climate integration?

For now it's need to fully rewrite because of mqtt changes in HA.. i am still not done that.. if i will finish it i will post it here

PGnl, 2022-10-07:
If you can share, I can see if I can find the time to update to the new mqqt format.
example typically saves quite some time.
As I was planning to do so anyway, we might be able to help each other.

geduxas, 2022-10-07:
@PGnl here is my config:
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
kamaradclimber, 2022-12-02:
I'm measuring the power consumption from an external point of view as well to have an completely trustable value.
But I don't use it for COP computation though.

geduxas, 2022-12-02:
> I'm measuring the power consumption from an external point of view as well to have an completely trustable value. But I don't use it for COP computation though.

Yes for total measurements it's ok :) but for cop mesurements it's different storry..

I just mentioned you that it would be nice to have counters which mentioned @bluberly .. about start/stop count.. defrost count.. also energy consumption :) i thought i could make it.. but didn't fell so good to implement it :)

Oekn5w, 2022-12-28:
Coming back to the flickering issue, while I didn't check the custom integration, I believe to have resolved this by ignoring mqtt topic updates immediately after the commands have been sent.

This was only present in the input_number stuff (DHW Target, Z1 and Z2 Delta), not the mode or boolean states.

From what I've seen in the MQTT Explorer after you send the command, the corresponding topic get immediately updated with the old value. This triggered the input_number to revert back to the previous temperature, retriggering the command to be updated (now with the old value). Then after 1-2 seconds the HP "confirms" the updated value and sends to new value to Heishamon.

From what I've seen in the source, there is no explicit readback of the affected values after the command, so this must be something the HP sends (I didn't dive that deep into the comm part).

As I had transitioned the Heishamon related automations to Appdaemon to not have them flood the Homeassistant logbook, I fixed the flickering by saving the timestamp of the command and prevent updates of its corresponding input_number until 1.5 seconds have passed.

michalwoz, 2022-12-28:
> This was only present in the input_number stuff (DHW Target, Z1 and Z2 Delta), not the mode or boolean states.

I'm 100% sure that it affects mode too.

michalwoz, 2022-12-28:
@Oekn5w
> This was only present in the input_number stuff (DHW Target, Z1 and Z2 Delta), not the mode or boolean states.

I'm 100% sure that it affects mode too.

Oekn5w, 2022-12-28:
@michalwoz should have been more clear - quiet and powerful mode are not affected, we do not change the general mode (yet)

geduxas, 2022-12-28:
Nice work @Oekn5w :) also as i remember, once i got flickering on HP operation button.. which turns on/off heatpump. I think there will be problems in all automation rules.

ankl00, 2023-01-01:
I think I have something similar happening with my setup. I change the quiet mode once via automation and after that there is never ending loop (or until HA restart):

Set quiet level triggered by state of Set Quiet Mode
05:59:59 - 7 hours ago
Set quiet level triggered by state of Set Quiet Mode
05:59:58 - 7 hours ago
Set quiet level triggered by state of Set Quiet Mode
05:59:58 - 7 hours ago
Set quiet level triggered by state of Set Quiet Mode
05:59:57 - 7 hours ago
Set quiet level triggered by state of Set Quiet Mode
05:59:56 - 7 hours ago

I do not have issue with Z1 setting which is also updated via my automation.

What is the latest recommended solution for this issue (novise user)? Switch to Kamarad integration? Add some delay somewhere? Stop using automated quiet mode setting?

geduxas, 2023-01-01:
For me is best solution to switch for integration mode.. and continue development in there..

geduxas, 2023-01-01:
Integration is the way how in HomeAssistant should work devices.. manual implementation is like temporary solution, or add on if something is missing in integration. But for first starters, or in low of understanding, best choice is integration.

Closed 2024-09-12.

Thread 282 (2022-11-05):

No Issue, just a question

Bogeyof, 2022-11-05:
Sorry for writing here but I have no clue how to send a simple question / message...

I programmed an extensive routine for setting the target temperature for the Panasonic HP, which sends a new setting for Z1_Heat_Request_Temp to the heat pump via Heishamon quite often (every few minutes).
Do you think this destroys the internal flash memory by frequent writing or are the registers kept in RAM and there is no problem?

geduxas, 2022-11-05:
No it will not be kept in ram. It will written.. becouse after power lose you have last set value..
Why you are setting it so often? Is there any point for that?

Bogeyof, 2022-11-05:
It´s a try for 9kW T-Cap to lower power of heating. I´m setting Z1_Heat_Request_Temp to a value, so that Main_Target_Temp = Main_Outlet_Temp - 1 (if possible, Z1_Heat_Request_Temp has only the range from -5 to 5). Everytime Main_Outlet_Temp is growing 1 up, I change Z1_Heat_Request_Temp also until Main_Target_Temp reached the real desired target value.
While Main_Outlet_Temp is > Main_Target_Temp, the HP goes to lowest possible power consumption. So I could extend the running time and lower power consumption, alltogether with a minimal better COP.
But I don´t want to destroy flash memory, so I will stop this test...

DL4JY, 2022-11-05:
Regarding flash, has somebody checked the circuits already, if the really use FLASH or RAM with battery backup?
I believe if they consistently write into flash they might end up like Tesla, where it "kills" the MCU (€3k+) because of logging to many data in /var/log.

Cheerio

michalwoz, 2022-11-05:
@Bogeyof I'm user of 9kW T-cap and HeishaMon. What you want to do was the first thing I thought about, even before I selected HP vendor. (I did equivalent with BAXI gas boiler and OpenTherm protocol.) HeishaMon was the easiest way for me to control HP. Actually, HeishaMon was the reason I've chosen Panasonic. I will also try to do some optimisations. I was really disappointed that 0-10V control don't work like we wish. I also want to take control over frequency of compressor. We cannot do it directly, so we have to make some workaround.

One thing that I've not investigated yet is the point where the COP is optimal vs frequency. First impressions after few weeks of looking on the graphs says that the lowest freq gets the best COP, but some charts say, that running on the lowest frequency don't give the best COP.

BTW, possibility of killing flash was also bad news for me. Maybe one of us will sacrifice a pump for the sake of science? Let's do a public fundraiser for a new motherboard for him 😄Anyway, if that is stored into flash, I've already lost few hundreds write cycles due to behaviour of default HA integration (described in issue recently).

MiG-41, 2022-11-06:
This "killing flash" is only speculations/assumptions , no one have it. And i also at beggining of Heishamon tests send a lot of SET commands at one time in a week , and even hear ,that there is something going inside PCB :)
But it still alive.

z4m0, 2022-11-25:
@Bogeyof Maybe you can try to set the silent mode to cap the max frequency.

geduxas, 2022-11-25:
> @michalwoz This "killing flash" is only speculations/assumptions , no one have it. And i also at beggining of Heishamon tests send a lot of SET commands at one time in a week , and even hear ,that there is something going inside PCB :) But it still alive.
>
> Also COP , can be individual HP , and in 9kW can be highest on lowest Hz , but on 7kW can be opposite :)

@michalwoz do you know what kind of cpu panasonic is using? Or maybe someone has detailed photo of pcb in both sides? Anyone read datasheets of cpu and/or flash memory?

MiG-41, 2022-11-26:
I had picture somwhere , generally no any descriptions on cpu and flash....

HighlyCompressedAir, 2024-09-11:
Duplicate https://github.com/Egyras/HeishaMon/issues/225

Closed 2024-09-12.

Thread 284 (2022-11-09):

Request: DHW Capacity

Donpepe23, 2022-11-09:
Hi,

ist it possible to add DHW Capacity to the commands?

THX

IgorYbema, 2022-11-09:
Can you explain more what you mean and why you need it?

Donpepe23, 2022-11-09:
Hi,

here the description from the service manual:

"To select tank heating capacity to variable or standard. Variable capacity heat up tank with fast mode and keep the tank temperature with effcient mode. While standard capacity heat up tank with rated heating capacity"

In the end "variable" only reduce the compressor frequency for DHW, which leads to higher efficency and lower power consumption, but reloading DHW will take longer.  I have two ideas:

- With the "rules" funkction this  can be changed automatically: low room heating demand: variable, higher efficency and better photovoltaic consumption  / high room heating demand: standard, to reduce DHW time (more heating time)

- For DHW the target temp is always 59°C and even you set the target DHW temp to 46°C you end up with water temp. above 50°C in the end of the DHW cycle.  I would like to switch towards the end of the DHW cycle to "variable" to finish the cycle with lower water temp -> higher efficency.

I have one of the Jeishas, where the demand control is not working...

Thanks

IgorYbema, 2022-11-09:
Hi. I can try to add that. Need to find the correct byte address. Can you post http://heishamon.local/debug outpost for when you set it to standard and again when you set it to variable? Please with a short time between both captures

michalwoz, 2022-11-09:
@Donpepe23

> * For DHW the target temp is always 59°C and even you set the target DHW temp to 46°C you end up with water temp. above 50°C in the end of the DHW cycle.  I would like to switch towards the end of the DHW cycle to "variable" to finish the cycle with lower water temp -> higher efficency.

In TCAP H 9kW target temperature goes to 57°C, almost the same as yours. I think that a lot of above depends how high your thermometer and snake are mounted in tank. Cannot you set lower target temp? There might be an issue to set delta to start heating properly with low target temp. How long after reaching target temp your HP turns off? How many °C actual temp is higher than target temp when HP turns off? in my case it is just 1°C as you can see on chart.
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

Donpepe23, 2022-11-09:
@

> Hi. I can try to add that. Need to find the correct byte address. Can you post http://heishamon.local/debug outpost for when you set it to standard and again when you set it to variable? Please with a short time between both captures

Will do... THX

@michalwoz :

I have  no heat exchanger... Have a 500L tank with "fresh water station" (proper englisch term?). The delta is arround 4-6K, as the temp sensor is in the middle of the tank. So the problem is, by the time the target temp at sensor level is reached, the water temp is already 4-6K above. But I can not change the spostion of the sensor or lower the target temp, as I need to have apprx 300l 46°C hot water to run the fresh waterstation with 43°C hot water output.

Closed 2024-09-12.

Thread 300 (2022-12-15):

Feature request: Set command for Top14 Outside Temperature

Tom54497, 2022-12-15:
The position of the outside temperature sensor is a pain. Icing causes a much lower value than it is in reality and forces a too high calculated outlet temperature which results in a permanent icing state of the heatpump.

Will be great to have an independant external sensor at a perfect position. The value could be written via a set command instead of the internal sensor.

Tom54497, 2022-12-15:
Sure. Deicing is not dependant of the outside temperature value. But that os not the point. Due to icing a lower outside temperature will be measured by the internal senor at the back of the heat pump. That causes a too high calculated outlet temperature on the heatcurve. That means more power and a quicker icing at higher humidities.

Right now I have three different outside temperatures:
-7 degrees by Jeisha due of permanent icing
-3 degrees by UVR16X2 sensor which controls the outlet temp of the heatcurve
-4 degrees by homematic outdoor sensor

Goalwill be to have only one value which controls all heat curves, the one at UVR16X2 and Jeisha.

 Homematic outdoor value can be send without any trouble to UVR16X2 via CMI but not to Jeisha.

geduxas, 2022-12-15:
And using external outside temperature sensor is not option? to keep it from icing?

PGnl, 2022-12-15:
In general, I do not get why your temp is 3 degrees below actual ambient and especially only when defrost is necessary. I have never seen that behaviour, nor with me or anyone else that I can remember.
Are you sure you are not “recycling “ your air. The temp of recycled air downward trend is typically “broken” during de-icing.
this as the fan is stopped and cool air is no longer added.
I have seen that at my place when I had that issue some years ago.

Tom54497, 2022-12-15:
For me the reason is that the internal sensor is mounted too close to the icing area of the cooling register. Furthermore it is mounted vertically on the metal housing if the pump.

Right now I have deicing cycles of 30 minutes. After deicing the pump powers that high that the next cycle is very close. It won't reach the optimum outlet temp any more. It is a devils cycle.

Tom54497, 2022-12-15:
Sure that occurs at high humidity only which right now is close to 90 percent. But under that circumstances it is impossible to heat my house consequently

PGnl, 2022-12-15:
As far as I remember, the sensor is clipped to the housing. Try to unsnap it and have it stick outward horizontally. Maybe some tape to have it stick out. This creating some distance to the ice.
First check if that solves the issue.

Tom54497, 2022-12-15:
THX. Had that idea as well

PGnl, 2022-12-15:
Note that all pana’s have it at the same place. Would be strange if you are the only one having this issue (haven’t heard of it before)

geduxas, 2022-12-15:
Strange, in my area also high humidity.. now with -15 it's 92-98%. Could you post some photos? Maybe there is too much ice/snow and unit isn't defrosting enough?

IgorYbema, 2022-12-15:
I had that once also. My 9kW unit doing a mode-2 defrost and after 30 mins it didn't clear all ice. This was easy solved by blocking the hard and cold wind which was supercooling the radiator. I just placed some wooden plate in front of it to deflect the wind and after the next mode-2 defrost all ice was gone.

HighlyCompressedAir, 2024-09-11:
That's not something to be implemented in Heishamon, Panasonic supports external outdoor sensor that can be used if the built-in one is inaccurate for some reason.
I believe this issue can be closed.

Closed 2024-09-12.

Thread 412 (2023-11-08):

Issues when room thermostat mode is selected in device

kgiedrius, 2023-11-08:
When room thermostat is used (not outdoor temperature curve) - Home assistant climate thermostat range is wrong. -5 .. +5, but it should be 5 .. 30
When + or - is clicked - thermostat resets to +5  and heatpump stops heating :)

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

geduxas, 2023-11-08:
Do you use integration or manual mqtt setup?

kgiedrius, 2023-11-08:
I use integration

geduxas, 2023-11-08:
Ok so issues should rised in integration repository, this is only for gateway.

https://github.com/kamaradclimber/heishamon-homeassistant

Please close it here.

Closed 2023-11-10.

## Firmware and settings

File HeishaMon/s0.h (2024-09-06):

#include <PubSubClient.h>
#include "src/common/webserver.h"

#define NUM_S0_COUNTERS 2
#if defined(ESP8266)
#define DEFAULT_S0_PIN_1 12 
#define DEFAULT_S0_PIN_2 14 
#elif defined(ESP32)
#define DEFAULT_S0_PIN_1 1
#define DEFAULT_S0_PIN_2 2 
#endif

struct s0SettingsStruct {
  byte gpiopin = 255;
  unsigned int ppkwh = 1000; //pulses per Wh of the connected meter
  unsigned int lowerPowerInterval = 60; //configurabel low power interval
  unsigned int minimalPulseWidth = 25; //configurabel minimal s0 pulse width
  unsigned int maximalPulseWidth = 100; //configurabel maximal s0 pulse width
};

struct s0DataStruct {
  unsigned int pulses = 0; //number of pulses since last report
  unsigned int pulsesTotal = 0; //total pulses measured from begin
  unsigned int watt = 0; //calculated average power
  unsigned long lastPulse = 0; //last pulse in millis
  unsigned long nextReport = 0; //next time we reported the s0 value in millis
  unsigned long goodPulses = 0;
  unsigned long badPulses = 0;
  unsigned int avgPulseWidth = 0;
};

void initS0Sensors(s0SettingsStruct s0Settings[]);
void restore_s0_Watthour(int s0Port, float watthour);
void s0Loop(PubSubClient &mqtt_client, void (*log_message)(char*), char* mqtt_topic_base, s0SettingsStruct s0Settings[]);
void s0JsonOutput(struct webserver_t *client);

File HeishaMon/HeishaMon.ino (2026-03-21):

#define LWIP_INTERNAL

#if defined(ESP8266)
#include <ESP8266WiFi.h>
#include <ESP8266mDNS.h>
  #define heatpumpSerial Serial
  #define loggingSerial Serial1
  #define ENABLEPIN 5
  #define LEDPIN 2
  #define BOOTPIN 0
#elif defined(ESP32)
  #define heatpumpSerial Serial1
  #define loggingSerial Serial //usb serial CDC
  #define uartSerial Serial0 //not used, 10x header pin
  #define proxySerial Serial2
  #define HEATPUMPRX 18
  #define HEATPUMPTX 17
  #define PROXYRX 9
  #define PROXYTX 8
  #define ENABLEPIN 5
  #define ENABLEOTPIN 4
  #define LEDPIN 42
  #define BOOTPIN 0
#include <WiFi.h>
#include <ESPmDNS.h>
#include <Adafruit_NeoPixel.h>
#endif


#include <DNSServer.h>
#include <WiFiUdp.h>
#include <ArduinoOTA.h>
#include <DNSServer.h>
#include <ArduinoJson.h>

#include "lwip/apps/sntp.h"
#include "src/common/timerqueue.h"
#include "src/common/stricmp.h"
#include "src/common/log.h"
#include "src/common/progmem.h"
#include "src/rules/rules.h"

#include "webfunctions.h"
#include "decode.h"
#include "commands.h"
#include "rules.h"
#include "version.h"

DNSServer dnsServer;

//to read bus voltage in stats
#ifdef ESP8266
ADC_MODE(ADC_VCC);
#endif

const byte DNS_PORT = 53;

#define SERIALTIMEOUT 2000 // wait until all 203 bytes are read, must not be too long to avoid blocking the code

settingsStruct heishamonSettings;

uint32_t neoPixelState = 0; //running neoPixelState
bool inSetup; //bool to check if still booting
volatile bool sending = false; // mutex for sending data
bool mqttcallbackinprogress = false; // mutex for processing mqtt callback

bool extraDataBlockAvailable = false; // this will be set to true if, during boot, heishamon detects this heatpump has extra data block (like K and L series do)

#define MQTTRECONNECTTIMER 30000 //it takes 30 secs for each mqtt server reconnect attempt
unsigned long lastMqttReconnectAttempt = 0;

unsigned long bootButtonNotPressed = 0;

#define WIFIRETRYTIMER 15000 // switch between hotspot and configured SSID each 10 secs if SSID is lost
unsigned long lastWifiRetryTimer = 0;
bool doInitialWifiScan = true; //we want an initial wifi scan to fill in the dropbox on the wifi settings page

unsigned long lastRunTime = 0;

#ifdef ESP8266
unsigned long lastOptionalPCBRunTime = 0;
unsigned long lastOptionalPCBSave = 0;
#endif
volatile unsigned long sendCommandReadTime = 0; //set to millis value during send, allow to wait millis for answer

unsigned long goodreads = 0;
unsigned long totalreads = 0;
unsigned long badcrcread = 0;
unsigned long badheaderread = 0;
unsigned long tooshortread = 0;
unsigned long toolongread = 0;
unsigned long timeoutread = 0;
float readpercentage = 0;
static int uploadpercentage = 0;

// instead of passing array pointers between functions we just define this in the global scope
#define MAXDATASIZE 255
char data[MAXDATASIZE] = { '\0' };
byte data_length = 0;

#ifdef ESP32
//for received proxied data
char proxydata[MAXDATASIZE] = { '\0' };
byte proxydata_length = 0;
//for the neopixel
Adafruit_NeoPixel pixels(1, LEDPIN);
//for the vTask
QueueHandle_t pcbQueue = NULL;
QueueHandle_t cmdQueue = NULL;
QueueHandle_t logQueue = NULL;
#endif

// store actual data
char actData[DATASIZE] = { '\0' };
char actDataExtra[DATASIZE] = { '\0' };
char actOptData[OPTDATASIZE]  = { '\0' };

// log message to sprintf to
#define LOG_MSG_SIZE 256
char log_msg[LOG_MSG_SIZE];

// mqtt topic to sprintf and then publish to
char mqtt_topic[256];

static int mqttReconnects = 0;

// can't have too much in buffer due to memory shortage
#define MAXCOMMANDSINBUFFER 10

// buffer for commands to send
struct cmdbuffer_t {
  uint8_t length;
  byte data[128];
} cmdbuffer[MAXCOMMANDSINBUFFER];

static uint8_t cmdstart = 0;
static uint8_t cmdend = 0;
static uint8_t cmdnrel = 0;



// mqtt
#ifdef TLS_SUPPORT
#include <WiFiClientSecure.h>
WiFiClientSecure *mqtt_tls_client = nullptr;
WiFiClient mqtt_wifi_client;
bool loadTlsCaFromFS(WiFiClientSecure *client);
static bool last_tls_enabled = false;
static bool new_ca_stored = false;
static std::unique_ptr<char[]> persistent_ca_pem;
PubSubClient mqtt_client;
#else
WiFiClient mqtt_wifi_client;
PubSubClient mqtt_client(mqtt_wifi_client);
#endif


bool firstConnectSinceBoot = true; //if this is true there is no first connection made yet

struct timerqueue_t **timerqueue = NULL;
int timerqueue_size = 0;

#ifdef ESP32
#define ETH_TYPE        ETH_PHY_W5500
#define ETH_ADDR         1
#define ETH_CS          10
#define ETH_IRQ          15
#define ETH_RST          14

// SPI pins
#define ETH_SPI_SCK     12
#define ETH_SPI_MISO    13
#define ETH_SPI_MOSI    11

void setupETH() {
  SPI.begin(ETH_SPI_SCK, ETH_SPI_MISO, ETH_SPI_MOSI);
  if (ETH.begin(ETH_TYPE, ETH_ADDR, ETH_CS, ETH_IRQ, ETH_RST, SPI)) {
    //sethostname on ESP32 after eth.begin (!! for wifi is most be before...!!)
    ETH.setHostname(heishamonSettings.wifi_hostname);
  } else {
    loggingSerial.println("Could not start ethernet. No ethernet module installed?");
  }
}
#endif



/*
    check_wifi will process wifi reconnecting managing
*/
#if defined(ESP8266)
void check_wifi() {
  int wifistatus = WiFi.status();
  if ((wifistatus != WL_CONNECTED) && (WiFi.localIP())) {
    // special case where it seems that we are not connect but we do have working IP (causing the -1% wifi signal), do a reset.
    log_message(_F("Weird case, WiFi seems disconnected but is not. Resetting WiFi!"));
    setupWifi(&heishamonSettings);
  } else if ((wifistatus != WL_CONNECTED) || (!WiFi.localIP())) {
    /*
        if we are not connected to an AP
        we must be in softAP so respond to DNS
    */
    if (heishamonSettings.hotspot) {
      dnsServer.processNextRequest();
    }

    /* we need to stop reconnecting to a configured wifi network if there is a hotspot user connected
        also, do not disconnect if wifi network scan is active
    */
    if ((heishamonSettings.wifi_ssid[0] != '\0') && (wifistatus != WL_DISCONNECTED) && (WiFi.scanComplete() != -1) && (WiFi.softAPgetStationNum() > 0)) {
      log_message(_F("WiFi lost, but softAP station connecting, so stop trying to connect to configured ssid..."));
      WiFi.disconnect(true);
    }

    /*  only start this routine if timeout on
        reconnecting to AP and SSID is set
    */
    if ((heishamonSettings.wifi_ssid[0] != '\0') && ((unsigned long)(millis() - lastWifiRetryTimer) > WIFIRETRYTIMER)) {
      lastWifiRetryTimer = millis();
      if ((WiFi.softAPSSID() == "") && (heishamonSettings.hotspot)) {
        log_message(_F("WiFi lost, starting setup hotspot..."));
        WiFi.softAPConfig(apIP, apIP, IPAddress(255, 255, 255, 0));
        WiFi.softAP(_F("HeishaMon-Setup"));
      }
      if ((wifistatus == WL_DISCONNECTED) && (WiFi.softAPgetStationNum() == 0)) {
        log_message(_F("Retrying configured WiFi, ..."));
        if (heishamonSettings.wifi_password[0] == '\0') {
          WiFi.begin(heishamonSettings.wifi_ssid);
        } else {
          WiFi.begin(heishamonSettings.wifi_ssid, heishamonSettings.wifi_password);
        }
      } else {
        log_message(_F("Reconnecting to WiFi failed. Waiting a few seconds before trying again."));
        WiFi.disconnect(true);
      }
    }
  }
  if (WiFi.localIP()) {  //WiFi connected
    if (WiFi.softAPSSID() != "") {
      log_message(_F("WiFi (re)connected, shutting down hotspot..."));
      WiFi.softAPdisconnect(true);
      MDNS.notifyAPChange();
    }

    if (firstConnectSinceBoot) {  // this should start only when softap is down or else it will not work properly so run after the routine to disable softap
      firstConnectSinceBoot = false;
      lastMqttReconnectAttempt = 0;  //initiate mqtt connection asap
      setupOTA();
      MDNS.begin(heishamonSettings.wifi_hostname);
      MDNS.addService("http", "tcp", 80);
      experimental::ESP8266WiFiGratuitous::stationKeepAliveSetIntervalMs(5000);  //necessary for some users with bad wifi routers

      if (heishamonSettings.wifi_ssid[0] == '\0') {
        log_message(_F("WiFi connected without SSID and password in settings. Must come from persistent memory. Storing in settings."));
        WiFi.SSID().toCharArray(heishamonSettings.wifi_ssid, 40);
        WiFi.psk().toCharArray(heishamonSettings.wifi_password, 40);
        JsonDocument jsonDoc;
        settingsToJson(jsonDoc, &heishamonSettings);  //stores current settings in a json document
        saveJsonToFile(jsonDoc, "config.json");     //save to config file
      }

      ntpReload(&heishamonSettings);
      logprintln_P(F("Try to syncing with ntp servers. Checking again in 5 minutes"));
      timerqueue_insert(300, 0, -6);
    }

    /*
       always update if wifi is working so next time on ssid failure
       it only starts the routine above after this timeout
    */
    lastWifiRetryTimer = millis();

    // Allow MDNS processing
    MDNS.update();
  }
  if (doInitialWifiScan && (millis() > 15000)) {  //do a wifi scan a boot after 15 seconds
    doInitialWifiScan = false;
    log_message(_F("Starting initial wifi scan ..."));
    WiFi.scanNetworksAsync(getWifiScanResults);
  }
}
#elif defined(ESP32)
void check_wifi() {
  wl_status_t wifistatus = WiFi.status();
  bool ethUp = ETH.hasIP();
  bool wifiUp = (wifistatus == WL_CONNECTED);

  /* ---------- Fast path: network is up ---------- */
  if (wifiUp || ethUp) {

    neoPixelState = pixels.Color(0, 0, 0); // normal operation
    lastWifiRetryTimer = millis();

    // Shut down hotspot if no longer needed
    if ((WiFi.getMode() & WIFI_MODE_AP) &&
        ((heishamonSettings.wifi_ssid[0] != '\0') || !heishamonSettings.hotspot)) {

      log_message(_F("WiFi or ETH connected, shutting down hotspot"));
      WiFi.softAPdisconnect(true);
      WiFi.mode(WIFI_STA);
      if (wifistatus != WL_CONNECTED) { //it must be that ETH reconnected, so keep trying WiFi in the background
        WiFi.setScanMethod(WIFI_ALL_CHANNEL_SCAN);
        if (heishamonSettings.wifi_password[0] == '\0') {
          WiFi.begin(heishamonSettings.wifi_ssid);
        } else {
          WiFi.begin(heishamonSettings.wifi_ssid, heishamonSettings.wifi_password);
        }
      }
    }

    if (firstConnectSinceBoot) {
      firstConnectSinceBoot = false;

      lastMqttReconnectAttempt = 0;
      setupOTA();

      MDNS.begin(heishamonSettings.wifi_hostname);
      MDNS.addService("http", "tcp", 80);

      if (heishamonSettings.wifi_ssid[0] == '\0') {
        log_message(_F("Storing WiFi credentials from persistent memory"));
        WiFi.SSID().toCharArray(heishamonSettings.wifi_ssid, 40);
        WiFi.psk().toCharArray(heishamonSettings.wifi_password, 40);
        JsonDocument jsonDoc;
        settingsToJson(jsonDoc, &heishamonSettings);
        saveJsonToFile(jsonDoc, "config.json");
      }

      ntpReload(&heishamonSettings);
      logprintln_P(F("NTP sync scheduled"));
      timerqueue_insert(300, 0, -6);
    }

    return;
  }

  /* ---------- Network is DOWN ---------- */

  neoPixelState = pixels.Color(16, 16, 0); // yellow: degraded

  if (heishamonSettings.hotspot) {
    dnsServer.processNextRequest();
  }

  // If AP client is connected, STA must back off
  if (WiFi.softAPgetStationNum() > 0) {
    if (WiFi.getMode() != WIFI_AP) {
      log_message(_F("SoftAP client active, suspending STA reconnect"));
	    WiFi.disconnect(true);
	    WiFi.mode(WIFI_AP);
    }
	  return; //always return if hotspot is used
  }

  // Periodic retry gate
  if ((unsigned long)(millis() - lastWifiRetryTimer) < WIFIRETRYTIMER) {
    return;
  }
  lastWifiRetryTimer = millis();

  // Ensure AP is running if allowed
  if (heishamonSettings.hotspot && !(WiFi.getMode() & WIFI_MODE_AP)) {
    log_message(_F("Starting setup hotspot"));
    WiFi.mode(WIFI_AP_STA);
    WiFi.softAPConfig(apIP, apIP, IPAddress(255, 255, 255, 0));
    WiFi.softAP(_F("HeishaMon-Setup"));
  }

  // Disable STA so next retry is clean and we wait WIFIRETRYTIMER so hotspot can do its thing
  if (WiFi.getMode() != WIFI_AP) {
    log_message(_F("Disabling WiFi STA for a while..."));	
	  WiFi.disconnect(true);
    WiFi.mode(WIFI_AP); 
    return;
  }

  // Retry STA connection
  if (heishamonSettings.wifi_ssid[0] != '\0') {
    // Repair STA if it is stopped
    if (!(WiFi.getMode() & WIFI_MODE_STA)) {
      log_message(_F("STA stopped, re-enabling STA"));
      WiFi.mode(WIFI_AP_STA);
      delay(50);
    }    
    log_message(_F("Retrying configured WiFi"));
    WiFi.setScanMethod(WIFI_ALL_CHANNEL_SCAN);
    if (heishamonSettings.wifi_password[0] == '\0') {
      WiFi.begin(heishamonSettings.wifi_ssid);
    } else {
      WiFi.begin(heishamonSettings.wifi_ssid, heishamonSettings.wifi_password);
    }
  }
}
#endif

#ifdef TLS_SUPPORT
bool loadTlsCaFromFS(WiFiClientSecure *client) {
  if (!LittleFS.exists("/ca.pem")) {
    log_message(_F("[TLS] /ca.pem not found"));
    return false;
  }
  File certFile = LittleFS.open("/ca.pem", "r");
  if (!certFile) {
    log_message(_F("[TLS] open(/ca.pem) failed"));
    return false;
  }
  size_t certSize = certFile.size();
  if (certSize == 0) {
    log_message(_F("[TLS] /ca.pem is empty"));
    certFile.close();
    return false;
  }
  persistent_ca_pem.reset(new char[certSize + 1]);
  size_t n = certFile.readBytes(persistent_ca_pem.get(), certSize);
  persistent_ca_pem[n] = '\0';
  certFile.close();
  client->setCACert(persistent_ca_pem.get());
  log_message(_F("[TLS] CA loaded into client"));
  return true;
}
#endif
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
void loop() {
  //check boot button state
  checkBootButton();

  //webserver function
  webserver_loop();

  // check wifi
  check_wifi();
  // Handle OTA first.s
  ArduinoOTA.handle();

  mqtt_client.loop();

  if (heishamonSettings.opentherm) {
    HeishaOTLoop(actData, mqtt_client, heishamonSettings.mqtt_topic_base);
  }

  readHeatpump();

#ifdef ESP32
  if (heishamonSettings.proxy) readProxy();

  if (logQueue != NULL) {
    if (xQueueReceive(logQueue, log_msg, 0) == pdTRUE) {
      log_message(log_msg);
    }
  }
#endif

#ifdef ESP8266
  if ((!sending) && (cmdnrel > 0)) { //check if there is a send command in the buffer
    log_message(_F("Sending command from buffer"));
    popCommandBuffer();
  }
#endif

  if (heishamonSettings.use_1wire) dallasLoop(mqtt_client, log_message, heishamonSettings.mqtt_topic_base);

  if (heishamonSettings.use_s0) s0Loop(mqtt_client, log_message, heishamonSettings.mqtt_topic_base, heishamonSettings.s0Settings);

#ifdef ESP8266
//this only runs on ESP8266, the ESP32 does this in vTask
  if ((!sending) && (!heishamonSettings.listenonly) && (heishamonSettings.optionalPCB) && ((unsigned long)(millis() - lastOptionalPCBRunTime) > OPTIONALPCBQUERYTIME) ) {
    lastOptionalPCBRunTime = millis();
    send_optionalpcb_query();
    if ((unsigned long)(millis() - lastOptionalPCBSave) > (1000 * OPTIONALPCBSAVETIME)) {  // only save each 5 minutes
      lastOptionalPCBSave = millis();
      if (saveOptionalPCB(optionalPCBQuery, OPTIONALPCBQUERYSIZE)) {
        log_message((char*)"Succesfully saved optional PCB data to flash!");
      } else {
        log_message((char*)"Failed to save optional PCB data to flash!");
      }
    }
  }
#endif

  // run the data query only each WAITTIME
  if ((unsigned long)(millis() - lastRunTime) > (1000 * heishamonSettings.waitTime)) {
    lastRunTime = millis();
    //check mqtt
  #ifdef ESP8266
    if ( WiFi.isConnected() && (!mqtt_client.connected()) )
  #else
    if ( (WiFi.isConnected() || ETH.connected()) && (!mqtt_client.connected()) )
  #endif
    {
      if (mqttReconnects > 0 ) log_message(_F("Lost MQTT connection!"));
      if (strlen(heishamonSettings.mqtt_server) > 0) mqtt_reconnect();
    }


    //log stats
    if (totalreads > 0 ) readpercentage = (((float)goodreads / (float)totalreads) * 100);
    String message;
#ifdef ESP8266
    message.reserve(384);
#endif
    message += F("Heishamon stats: Uptime: ");
    char *up = getUptime();
    message += up;
    free(up);
    message += F(" ## Free memory: ");
    message += getFreeMemory();
#if defined(ESP8266)
    message += F("% ## Heap fragmentation: ");
    message += ESP.getHeapFragmentation();
    message += F("% ## Max free block: ");
    message += ESP.getMaxFreeBlockSize();
    message += F(" bytes ## Free heap: ");
#elif defined(ESP32)
    message += F("% ## Free PSRAM: ");
    message += ESP.getFreePsram();
    message += F(" bytes ## Free heap: ");
#endif
    message += ESP.getFreeHeap();
    message += F(" bytes ## Wifi: ");
    message += getWifiQuality();
    message += F("% (RSSI: ");
    message += WiFi.RSSI();
#ifdef ESP32
    message += F(") ## Ethernet: ");
    if (ETH.phyAddr() != 0) {        
      if (ETH.connected()) {
        if (ETH.hasIP()) {
          message += F("connected (");
          message += ETH.localIP().toString();
          message += F(")");
        } else {
          message += F("connected (no IP)");
        }
      } 
      else {
        message += F("not connected");
      }
    } else {
      message += F("not installed");
    }
    message += F(" ## Mqtt reconnects: ");
#else
    message += F(") ## Mqtt reconnects: ");
#endif
    message += mqttReconnects;
    message += F(" ## Correct data: ");
    message += readpercentage;
    message += F("% Rules active: ");
    message += nrrules;
    log_message((char*)message.c_str());

    String stats;
#ifdef ESP8266
    stats.reserve(384);
#endif
    stats += F("{\"uptime\":");
    stats += String(millis());
    stats += F(",\"voltage\":");
#if defined(ESP8266)
    stats += ESP.getVcc() / 1024.0;
#else
    stats += "3.3";
#endif
    stats += F(",\"free memory\":");
    stats += getFreeMemory();
    stats += F(",\"free heap\":");
    stats += ESP.getFreeHeap();
    stats += F(",\"wifi\":");
    stats += getWifiQuality();
    stats += F(",\"mqtt reconnects\":");
    stats += mqttReconnects;
    stats += F(",\"total reads\":");
    stats += totalreads;
    stats += F(",\"good reads\":");
    stats += goodreads;
    stats += F(",\"bad crc reads\":");
    stats += badcrcread;
    stats += F(",\"bad header reads\":");
    stats += badheaderread;
    stats += F(",\"too short reads\":");
    stats += tooshortread;
    stats += F(",\"too long reads\":");
    stats += toolongread;
    stats += F(",\"timeout reads\":");
    stats += timeoutread;
    stats += F(",\"version\":\"");
    stats += heishamon_version;
    stats += F("\",\"board\":\"");
#ifdef ESP8266
    stats += F("ESP8266");
#else
    stats += F("ESP32");
#endif
    stats += F("\",\"rules active\":");
    stats += nrrules;
    stats += F("}");
    sprintf_P(mqtt_topic, PSTR("%s/stats"), heishamonSettings.mqtt_topic_base);
    mqtt_client.publish(mqtt_topic, stats.c_str(), MQTT_RETAIN_VALUES);

    //websocket stats
#ifdef ESP32
    String ethernetStat;
    if (ETH.phyAddr() != 0) {        
      if (ETH.connected()) {
        if (ETH.hasIP()) {
          ethernetStat = F("connected - IP: ");
          ethernetStat += ETH.localIP().toString();
        } else {
          ethernetStat = F("connected - no IP");
        }
      } 
      else {
        ethernetStat = F("not connected");
      }
    } else {
      ethernetStat = F("not installed");
    }
    char *getuptime = getUptime();
    sprintf_P(log_msg, PSTR("{\"data\": {\"stats\": {\"wifi\": %d, \"ethernet\": \"%s\", \"memory\": %d, \"correct\": %.0f,\"mqtt\": %d,\"rules\": %d,\"uptime\": \"%s\"}}}"), getWifiQuality(), ethernetStat.c_str(), getFreeMemory(), readpercentage, mqttReconnects, nrrules, getuptime);
    free(getuptime);    
#else
    char *getuptime = getUptime();
    sprintf_P(log_msg, PSTR("{\"data\": {\"stats\": {\"wifi\": %d, \"memory\": %d, \"correct\": %.0f,\"mqtt\": %d,\"rules\": %d,\"uptime\": \"%s\"}}}"), getWifiQuality(), getFreeMemory(), readpercentage, mqttReconnects, nrrules, getuptime);    
    free(getuptime);    
#endif
    
    websocket_write_all(log_msg, strlen(log_msg));        

#ifdef ESP8266
    //get new data
    if (!heishamonSettings.listenonly) send_panasonic_query();
#endif

    //Make sure the LWT is set to Online, even if the broker have marked it dead.
    sprintf_P(mqtt_topic, PSTR("%s/%s"), heishamonSettings.mqtt_topic_base, mqtt_willtopic);
    mqtt_client.publish(mqtt_topic, "Online");

#ifdef ESP8266
    if (WiFi.isConnected()) {
      MDNS.announce();
    }
#endif
  }

  timerqueue_update();
  #ifdef ESP32
  delay(1); // to keep watchdog happy
  #endif
}

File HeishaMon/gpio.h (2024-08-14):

#if defined(ESP8266)
#define NUMGPIO 3
#include <ESP8266WiFi.h>
#include <ESP8266WiFiGratuitous.h>
#elif defined(ESP32)
#define NUMGPIO 7
#include <WiFi.h>
#include <ESPmDNS.h>
#include <Update.h>
#define relayOnePin 21
#define relayTwoPin 47
#endif

extern const char* mqtt_topic_gpio;

struct gpioSettingsStruct {
#if defined(ESP8266)
  unsigned int gpioPin[NUMGPIO] = {1, 3, 16};
  unsigned int gpioMode[NUMGPIO] = {INPUT_PULLUP, INPUT_PULLUP, INPUT_PULLUP};
#elif defined(ESP32)
  unsigned int gpioPin[NUMGPIO] = {33, 34, 35, 36, 37, 21, 47};
  unsigned int gpioMode[NUMGPIO] = {INPUT_PULLUP, INPUT_PULLUP, INPUT_PULLUP, INPUT_PULLUP, INPUT_PULLUP, OUTPUT, OUTPUT};
#endif
};

void setupGPIO(gpioSettingsStruct gpioSettings);
void mqttGPIOCallback(char* topic, char* value);

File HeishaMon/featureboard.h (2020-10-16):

#include <PubSubClient.h>
#include <OneWire.h>
#include <DallasTemperature.h>

#define MAX_DALLAS_SENSORS 15
#define ONE_WIRE_BUS 4  // DS18B20 pin, for now a static config - should be in config menu later
#define NUM_S0_COUNTERS 2
#define DEFAULT_S0_PIN_1 12  // S0_1 pin, for now a static config - should be in config menu later
#define DEFAULT_S0_PIN_2 14  // S0_2 pin, for now a static config - should be in config menu later


struct dallasDataStruct {
  float temperature = -127.0;
  unsigned long lastgoodtime = 0;
  DeviceAddress sensor;
  char address[17];
};

struct s0SettingsStruct {
  byte gpiopin = 255; 
  unsigned int ppkwh = 1000; //pulses per Wh of the connected meter
  unsigned int lowerPowerInterval = 60; //configurabel low power interval
  bool sum_s0_watthour = false; //count watthour upwards, do not reset between messages
};

struct s0DataStruct {
  unsigned int pulses = 0; //number of pulses since last report
  unsigned int watt = 0; //calculated average power
  unsigned long lastPulse = 0; //last pulse in millis
  unsigned long nextReport = 0; //next time we reported the s0 value in millis
};


void dallasLoop(PubSubClient &mqtt_client, void (*log_message)(char*), char* mqtt_topic_base);
void initDallasSensors(void (*log_message)(char*), unsigned int updataAllDallasTimeSettings, unsigned int dallasTimerWaitSettings);
String dallasJsonOutput(void);
String dallasTableOutput(void);
void initS0Sensors(s0SettingsStruct s0Settings[], PubSubClient &mqtt_client, char* mqtt_topic_base);
void restore_s0_Watthour(int s0Port,float watthour);
void s0Loop(PubSubClient &mqtt_client, void (*log_message)(char*), char* mqtt_topic_base, s0SettingsStruct s0Settings[]);
String s0TableOutput(void);
String s0JsonOutput(void);

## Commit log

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2019-12-31 Fixed returned data from quiet_mode, added status for powerfull mode in quiet mode and for quiet mode in powerfull mode
    [webfunctions.cpp, webfunctions.h]
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2020-01-01 fix powerfull/quiet modes (looking at bit level)
2020-01-01 add reboot button html and binary on developer name for merge conflicts
    [webfunctions.cpp, webfunctions.h]
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2020-01-02 add hexdump and fix line indents
    [HeishaMon.ino]
2020-01-03 Update HeishaMon.ino
    - add the TOPxx ID from MQTT-Topics.md as comments
    - fix some topic names according MQTT-Topics.md
    pleas check, not compiled yet.
    [HeishaMon.ino]
2020-01-03 small web menu fix
    [webfunctions.cpp]
2020-01-03 fix typo in consumption topic
    [HeishaMon.ino]
2020-01-04 small fixes
    compiles and run
    [HeishaMon.ino]
2020-01-04 fix typo in set mode
    [HeishaMon.ino]
2020-01-04 typo fix
    typo fix Traget -> Target
    and fix of values for powerfull state
    [HeishaMon.ino]
2020-01-06 better bit functions, modify state file to match this and some fixes
    [HeishaMon.ino]
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2020-01-08 Moved factory reset to bottom of menu list and colored it red.
    [webfunctions.cpp]
2020-01-09 fix char overflows and switch serial only after succesful startup
    Switching serial after succesfull startup so all startup debug is on normal serial line.
    [HeishaMon.ino, webfunctions.cpp]
2020-01-09 confirm on factory reset
    [webfunctions.cpp]
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2020-01-12 fix pump flow calculation
2020-01-13 add info on MQTT-Topics
    If you operate your Heisha with direct temperature, the shift values correspond to the absolute temperature
2020-01-13 Set Commands and typo fix
    [HeishaMon.ino]
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2020-01-21 fix some minor compiler warnings
    [HeishaMon.ino]
2020-01-22 typo fixes of powerful
    [HeishaMon.ino]
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2020-01-25 release v0.4b due to bug in 0.3b
    [HeishaMon.ino]
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2020-02-08 maybe fix hexdump crash - start of s0 implementation
    [HeishaMon.ino, featureboard.h]
2020-02-09 fix the good reads percentage
    [HeishaMon.ino]
2020-02-09 Update README.md
    PIN's NO on CN-NMODE are from 4 to 1 !
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2020-03-29 small fix for iy-7
    [HeishaMon.ino, featureboard.h]
2020-04-08 mqtt topic base configurable, reboot after wifi failure, mqtt log default disabled
    [HeishaMon.ino, webfunctions.cpp, webfunctions.h]
2020-04-16 fix sendrawcommand bug, add S0 watthour
    [HeishaMon.ino, featureboard.h]
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2020-04-20 Delete States.md
    All this stages are in file MQTT-Topics.md . Here it is doubled and not actualizated as well.
    I thing this is not needed.
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2020-08-06 Correct model string
    For bi-block models the IDU contained the ODU product code and ODU contained
    the kit product code. Correct IDU and ODU values according to HeatPumpType.md.
2020-08-08 Fix Home Assistant integrations + add force DHW
    Some MQTT topics were incorrect in the HA integrations, fix them. Also
    provide a switch for forcing DHW heating - useful when many people need
    to take a shower.
2020-09-10 Update HeishaMon v3 case.stl
    [HeishaMon v3 case.stl]
2020-09-14 Home Assistant integration: shorten sensor names
2020-09-15 web bugfix refresh and s0 metering functionallity update
    [featureboard.h, webfunctions.cpp]
2020-09-30 Create HeishaMon v3.1 case.stl
    [HeishaMon v3.1 case.stl]
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2020-10-05 change cones to triangles for board place holders
    [HeishaMon v3.1 case.stl]
2020-10-06 move dallas and s0 data to featureboard.cpp and s0 data corrupt check reboot
    [HeishaMon.ino, featureboard.h, webfunctions.cpp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]
2020-10-06 fix webpage table hide for dallas and add gpio output for tx/rx for later use
    [HeishaMon.ino, featureboard.h, webfunctions.cpp]
2020-10-06 reintroduce cilinders for holding the pcb
    [HeishaMon v3.1 case.stl]
2020-10-06 put strings in progmem and add missinge opmodes
    [HeishaMon.ino, webfunctions.cpp]
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2020-10-26 fix OpMode for 2 zone operation
    [HeishaMon.ino]
2020-10-26 migrate to littlefs (config reset!)
    [webfunctions.cpp]
2020-10-29 Update Finnish readme and add a small note to HeatPumpType.md about pump types not listed in the file.
2020-10-30 Update HeatPumpType.md
    Add missing KIT number. Include the full KIT product code for all models. Monoblocks have no KIT as they're a single unit only.
2020-11-29 changed mqtt topics and add pump/valve commands from heatpump to optional pcb (opt0 .. opt6)
2020-11-29 fix for new commands mqtt structure
    [HeishaMon.ino]
2020-11-29 more quick coding fixes
    [HeishaMon.ino]
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2020-12-16 add delta commands and byte9 optpcb command plus ack optional pcb byte4and5
2020-12-17 DHWdelta set and mqtt broker timeout improvements for not blocking loop
    [HeishaMon.ino, s0.cpp]
2020-12-17 fix mqtt loop too much
    [HeishaMon.ino, s0.cpp]
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2021-01-03 start of gpio, command reset (not finished), factory reset debug led indication
    [HeishaMon.ino, gpio.cpp, gpio.h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]
2021-01-29 add stats topic and gratious arp to overcome issues with some routers
    [HeishaMon.ino, webfunctions.cpp]
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2021-02-13 Update ProtocolByteDecrypt.md
    TOP20 extended description , Change Energy to Power in description
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2021-03-14 add debug and fix mqtt reconnect at boot issue
    [HeishaMon.ino, gpio.cpp, webfunctions.cpp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]
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2021-03-23 fix identing and fix settings page bug
    [HeishaMon.ino, gpio.h, htmlcode.h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]
2021-05-03 identing and progmem fix
    [HeishaMon.ino, webfunctions.cpp]
2021-05-03 Replace FILO linked list with FIFO ringbuffer
    A linked list is (without additional measures) a first in last out data structure. That's not what we want for buffering commands. Therefor the linked list is replaced by a ringbuffer which is the most efficiënt first in first out data structure.
    This ringbuffer is also faster than the previous linked list and prevents unnecessary memory fragmentation.
    The only downside is that we need to claim (129 * buffersize) bytes of memory at front.
    ---
    This PR is the second PR of a series working towards implementing rules.
    [HeishaMon.ino]
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2021-05-04 fix error in mqtt stats
    [HeishaMon.ino]
2021-05-06 Replace wifiManager with lean AP logic
    The wifiManager is handy when that's all the logic
    necessary for handling wifi.
    However, the HeishaMon already has a pretty
    extensive webserver and webpage, including
    settings handling and such. When the rules
    functionality has been added, having wifi is not
    operation critical anymore. However, making sure
    the HeishaMon doesn't reboot and block is.
    The HeishaMon now just starts an AP when no
    WiFi settings have been set. When they are set
    the AP is only restarted after a certain period of
    time, until it can connect to the external AP
    again. Just as it currently works.
    WiFi connection now can be configured in the
    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
    [HeishaMon.ino, htmlcode.h, webfunctions.cpp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]
2021-05-06 Possible fix for first wifi connection
    [webfunctions.cpp]
2021-05-06 Indenting and log fixes
    [htmlcode.h, webfunctions.cpp]
2021-05-06 Fixed new javascript code
    [htmlcode.h]
2021-05-07 fix up reconnect to SSID on lost and webserver hang on android captive portal
    [HeishaMon.ino, htmlcode.h, webfunctions.cpp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]
2021-05-08 STA+AP and reconnecting to SSID now working correctly
    [HeishaMon.ino]
2021-05-08 switch between scanning and not scanning each timeout to allow hotspot to work
2021-05-08 mdns now working correctly also
    [HeishaMon.ino, webfunctions.cpp, webfunctions.h]
2021-05-11 move drd routine to setup fase only and replace some includes
    [HeishaMon.ino, webfunctions.cpp, webfunctions.h]
2021-05-14 re-add 08 binary, issue seems to be 'normal' - reboots fixes it
    https://github.com/esp8266/Arduino/issues/7432
    [HeishaMon.ino]
2021-05-24 reload other settings also without reboot
    [HeishaMon.ino, webfunctions.cpp, webfunctions.h]
2021-07-10 hopefully fix 50days timing issue
    [HeishaMon.ino, s0.cpp]
2021-08-27 added new model and small string fixes
    [webfunctions.cpp]
2021-08-29 fix 1wire resend bug and fix s0 pulse width setting
    [HeishaMon.ino, s0.cpp]
2021-10-01 fix json data
    [HeishaMon v3.1 case.stl]
2021-10-10 Generic timerqueue addition (#72)
    * Generic timerqueue addition
    * Added binary
    * Fixed typo
    * Remove unnecessary condition
    * test PR
    [HeishaMon.ino, timerqueue.cpp]
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2021-12-05 Async low memory webserver rewrite (#76)
    * Async low memory webserver rewrite
    * Fixed reading long header values
    * Improved previous commit
    * Fixed missing return statements
    * Some performance tries
    * Added synced version of webserver
    * Remove carriage returns EOL
    * move wifi scan result to callback
    * remove extra s0 tab on main page
    * prefill wifi scan json list at boot time
    * Synced webserver with latest version
    * Updated timerqueue and replace delays with it
    * Fixed missing include and header
    * Added firmware upload support
    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
    [HeishaMon.ino, htmlcode.h]
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2021-12-05 Revert "Better 404 message"
    This reverts commit 5974d891e6b1d151d57aab7ff1f9e76bc74ed70d.
    [HeishaMon.ino]
2021-12-09 Added attributes for support of long-term statistics. Added calculation in kWh for Energy Consumed for Heat and DHW Added force update of Power Consumption for smooth calculation of Energy Consumed.
2021-12-21 fix removing a line too many
    [webfunctions.cpp]
2021-12-30 Optimize usage of actdata and actoptdata (#87)
    * move from actdata string array to char array
    * small change in string usage
    * actoptdata improvement
    * some small fixes
    [HeishaMon.ino, webfunctions.cpp, webfunctions.h]
2021-12-30 Adding Pump_Flowrate_Mode for J series (#80)
    * Try adding Maximum_Pump_Speed for J series
    * change topic name and add documentation
2021-12-30 fix web table/json view when actdata empty
    [webfunctions.cpp]
2022-01-02 make ssid and password correct length
    [webfunctions.h]
2022-01-04 resend data on mqtt reconnect fix
    [HeishaMon.ino]
2022-01-08 fix websettings memory leak - use delete on new instead of free
    [webfunctions.cpp]
2022-01-08 fix memory leak on wifi reconfig
    When there is still client data to be transmitted during wifi reset a memory leak can occur. So introduce a timer wait for the wifi reconfig call
    [HeishaMon.ino, webfunctions.cpp]
2022-01-08 also destroy cached websettings at wrong password
    I could also clear the websetting in the if else but this seems nicer as it is following the same structure as the wifi ssid/pass check.
    [webfunctions.cpp]
2022-01-14 fix weird wifi -1% but online status
    [HeishaMon.ino]
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2022-01-21 fix bad header affecting bad reads
    [HeishaMon.ino]
2022-05-18 Test pr78 optionalpcb (#92)
    * Implement rules config page and add userdata webserver field
    * Better memory management
    * Initialize userdata
    * Remove obsolete variable
    * Also check FS:File boolean
    * Implementing rules
    * Allow ds18b20 sensors as rules event
    * Fix proper length of ds18b20 strcmp
    * Actually subscribe to opentherm topic
    * Allow opentherm vars as event triggers
    * Fix small edge case in webserver
    ```c
    -----------------------------354617515641648399072235817744\r\n
    Content-Disposition: form-data; name="rules"\r\n
    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
    [HeishaMon.ino]
2022-05-28 update STL files
    [HeishaMon normal case.stl, HeishaMon opentherm case.stl, HeishaMon v3 case.stl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]
2022-07-12 fix json output - pre v3.0 release
    [webfunctions.cpp]
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2022-10-17 Add heatpump type for WH-MXC09J3E8 (#94)
    * Convert mqtt format according to HA 2022.6 change
    * readme - information about compatibility
    * Update MQTT-Topics.md
    Correction of DHW delta temp.
    * Update webfunctions.h
    Extended length of MQTT topic base from 40 to 128, the 40 characters were not enough for me.
    * Update heishamon.yaml
    * Add WH-MXC09J3E8 to HeatPumpType.md
    * Add WH-MXC09J3E8 to decode.h
    * Add WH-ADC1216H6E5 model
    * add WH-MXC12J9E8
    Co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
    [webfunctions.h]
2022-11-11 sync fork (#96)
    * Update webfunctions.h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
    [webfunctions.h]
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2022-12-12 fix error in pad heater top/set
2023-01-03 Check length of vars for overlapping name matches (#104)
    * Check length of vars for overlapping name matches
    There are two topics with similar leading characters:
    - Pump_Flow
    - Pump_Flowrate_Mode
    We didn't check properly if the length of the variable matched the length of the topic. Therefor, in both cases `Pump_Flow` matched leaving `rate_Mode` as an unknown string.
    * A var has an identifying leading character
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2023-01-15 🗒 Document heishamon-homeassistant integration (#95)
    Fixes Egyras/HeishaMon#267
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2023-02-03 some fixes for dhw set and maxtset
    [HeishaOT.h]
2023-02-05 fixes for firmware upload failing
    [HeishaMon.ino]
2023-02-05 fixes for opentherm - mosfet enable should be on for opentherm version
    [HeishaMon.ino, webfunctions.cpp]
2023-02-12 Fix typos in HeatPumpType.md
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2023-10-14 Squashed commit of the following:
    commit d98b485e74455f863fc55c0bb97c01a2eb593a78
    Date: Sat Oct 14 09:37:30 2023 +0200
    add XTOP to web server table
    commit ff21d8e23f07b1507de635d4008b6d5e80a0415d
    Date: Thu Oct 12 07:50:33 2023 +0200
    fix wrong heatpump type
    commit c5375c6d52f83bcd886c674941a90b0ffe4c3038
    Date: Tue Oct 10 13:17:01 2023 +0200
    only run json data for extratopics when available
    commit 5d510acbe27d09df8ddf5d8b844952108b8af559
    Date: Tue Oct 10 13:13:23 2023 +0200
    extra data in json
    commit 60e4e3be36b31ca939537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
    [HeishaMon.ino, webfunctions.cpp, webfunctions.h]
2023-10-15 fix content counting for table and json runs
    [webfunctions.cpp]
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2023-10-18 integrations: Fix power templates when values not available
2023-10-20 disable opentherm by default and maybe fix for heatpump stopts responding to heishamon
    [HeishaMon.ino, webfunctions.h]
2023-10-27 sync up (#128)
    * integrations: Add cool modes in Home Assistant
    * integrations: Remove S0 energy calculations in Home Assistant
    * integrations: Add consumed and produced totals in Home Assistant
    * integrations: Add all modes COP calculations in Home Assistant
    * integrations: Improve naming consistency in Home Assistant
    * integrations: Fix power templates when values not available
    * Add version to stats
    ---------
    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
    [HeishaMon.ino]
2023-10-27 remove debug and fix showRules corner case
    [HeishaMon.ino, webfunctions.cpp]
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2023-12-30 fix breaking settings with last commit
    [webfunctions.cpp]
2024-02-02 Update HeatPumpType.md
    Added a number of heat pumps reported in issues
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2024-02-07 Fix capitalization on flowrate mode
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2024-05-13 Update rule library version (#121)
    * Update rule library version
    * Add ceil and event functions again
    * Some bugfixes
    * Keep rules in synced execution
    * Fix 2nd safe compilation
    * Fix more 2nd heap bugs
    * uint32_t to int32_t fix for vm_vinteger_t
    * Fix webserver for 2nd heap
    * Fix build after merge
    * Prevent crash on failed rules
    * Include all sources
    * fix OT callback crash
    * Give error when out of memory
    * Reclaim some memory in rule lib
    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
    [HeishaMon.ino]
2024-05-19 V3.5 release (#132)
    * add dalias alias option
    * add call to webserver
    * add save and load dallas alias
    * fix dallas json issue
    * another json fix
    * add visible hint to edit alias
    * fix length after last webcontent change
    * refresh visible table only
    * remove same function
    * json values not as string and add scandallas
    * test two variants of mqtt output for dallas with alias
    * fixing OT
    * adding more opentherm features
    * readme update
    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
    [HeishaMon.ino, HeishaOT.h]
2024-06-17 rename stl
    [Heishamon-case-not-used-old-version.stl, Heishamon-case-small-version-with-opentherm.stl]
2024-08-13 V3.6 release PR (#135)
    * add hotspot disable function
    * Squashed commit of the following:
    commit d2a65cc947ba0911c1035c654c2ad7efe1e6d8b2
    Date: Sun Jul 21 11:48:41 2024 +0200
    10s boot button factory reset
    * remove binaries
    * update version file to v3.6
    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
    [HeishaMon.ino, htmlcode.h, webfunctions.cpp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]
2024-08-20 fix rules variables console printing
2024-09-05 V3.7 release (#138)
    * Added concat description
    * Fix rule_by_name
    * Quick fix in case there are too many vars
    * Exclude strings from slot assigning logic
    * Rule triggers should contain up-to-date values
    * Better identify individual formulas
    * Even better identify individual formulas
    * Don't hardcode vm_top_t size
    * Ignore OP_GETVAL in slot assingments
    * Proper if condition
    commit 90f178330d48b6b0d8a2ebb1e988f81b14b5b60c
    Date: Mon Aug 26 16:18:47 2024 +0200
    remove table refresh functions
    commit afbca728f0c4c8a6ab8fce4bb403606c10337d10
    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
    [HeishaMon.ino, HeishaOT.h]
2024-09-07 fix error not saving settings
    [webfunctions.cpp]
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2024-11-24 add wifi all scan esp32 and revert log changes
    [HeishaMon.ino, webfunctions.cpp]
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2025-01-04 add correct byte value for Model combination 52 Update HeatPumpType.md
    E2 D5 0B 34 99 83 92 0C 27 98
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2025-01-10 Force rules on boot despite crash (#143)
    * Allow forcing rules on boot despite crash
    * Fix wrong condition
    * Replace arrow with dot
    * Update upload artifact version
    * Fix wrong condition
    * Fix string length
    [HeishaMon.ino, htmlcode.h, webfunctions.cpp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]
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2025-01-10 sync up (#148)
    * remove unused dependencies
    * remove unused dependencies
    * improve note
    * Delete platformio.ini
    * Update LIBSUSED.md
    * Update decode.h
    * Update OptionalPCB.md
    * Update OptionalPCB.md
    * add bivalent heating
    * add bivalent heating
    * add bivalent heating
    * Update decode.h
    * fix model count
    * added more switch options to bivalent settings because of homeassistant-aquara plugin
    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
2025-01-11 Asynchronous 1-wire reading
    Currently, 1-wire is read synchronously, which means the program is paused for up to 750ms. During this pause, a yield is called, ensuring that WiFi works correctly. However, other issues may arise, such as UART read buffer overflow.
    I have modified the code so that everything operates asynchronously.
    The previous solution to this problem contained a bug:
    if ((DALLASASYNC) && ((unsigned long)(millis() - dallasTimer) > ((1000 * dallasTimerWait) - 1000)) ) {
    DS18B20.requestTemperatures(); // get temperatures for next run 1 second before getting the temperatures (async)
    }
    The author assumed the code would execute only once, while in reality, it was executed m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
2025-01-13 Reverse two arguments order
    [gpio.cpp]
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2025-01-16 optdata GUI fix and import rules fix
    [webfunctions.cpp]
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2025-05-31 fix: set powerful mode without affecting quiet mode
    Ref: #678
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2025-06-02 Revert "integrations: Remove S0 energy calculations in Home Assistant"
    This reverts commit 32d3bc53a96ac1845dd29b8ea9f043edff41208a. S0 readings
    are interesting as they provide an external view to the energy usage. The
    inbuilt readings from the heat pump are not as reliable. Also, there might
    be other uses for the S0 as just monitoring the heat pump.
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2025-08-17 Update HeatPumpType.md
    Issue #702.
2025-09-13 sync up (#157)
    * Update Kit Type KIT-ADC05L3E5AN KIT-WC05L3E5 HeatPumpType.md
    * add KIT-ADC03JE5C-S
    * Added WH-MXC12H9E8 as value 50
    * add KIT-AXC9HE8
    * fix: set powerful mode without affecting quiet mode
    * Switched to custom image and added precommit
    * Revert "integrations: Remove S0 energy calculations in Home Assistant"
    inbuilt r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
2025-09-13 Fix related to WebSocket (#158)
    I'm connecting to HeishaMon via an SSH tunnel. I access the application on a port other than 80 — in my case, it's 81. Unfortunately, the software doesn't work correctly and throws the following error:
    `Uncaught SyntaxError: Failed to construct 'WebSocket': The URL 'ws://127.0.0.2:81:80/ws' is invalid.`
    In the `htmlcode.h` file, the WebSocket connection unnecessarily forces port 80. This is not needed, because the port is automatically added in `location.host` as long as it differs from the default one (80 for `ws` and 443 for `wss`).
    [htmlcode.h]
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2026-03-12 the default disabled for mqtt tls settings was missing
    [webfunctions.cpp]
2026-03-15 fix webserver on ESP32 skip the safe write
2026-03-20 add version to all menu items and reboot check
    [htmlcode.h]
2026-03-20 fix screensize on small devices
    [htmlcode.h]
2026-03-21 not init tls globally due to bug
    [HeishaMon.ino]
2026-10-11 Fix swapped IDU/ODU columns for KIT-WXC12K6E5 in HeatPumpType.md (#1014)
    The row added in #1002 listed the outdoor unit (WH-UXZ12KE5) under IDU
    and the indoor unit (WH-SXC12K6E5) under ODU.
    Claude-Session: https://claude.ai/code/session_01McZdUot5hJDtPXm64RbKzt
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2026-10-12 Jeisha rules: lock smart pause around DHW, restore state after reboot
    After every DHW run in mild weather the smart pause switched the heat
    pump off: right after DHW the heat request is deliberately high and heat
    power still reads 0 W, which is exactly the smart-pause signature.
    - #smartPauseLock is set on every DHW transition (dhw_start, every
    three-way valve flip, defrost during DHW, DHW end by power, timer=24)
    and released by the new timer=25 #smartPauseLockSeconds (300 s) after
    the last timer=24; timer=25 then re-runs smart_pause() once. All other
    lock points cancel a pending timer=25 so the lock cannot expire before
    the recovery chain's own timer=24.
    - One-shot boot check res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
2026-10-12 Jeisha rules: restore DHW holding curves after reboot or unit-off DHW end
    The narrow DHW holding curves (high == low == DHW target + 6) could stay
    active after DHW, leaving the heating curve far too high:
    - The valve -> room recovery chain (timer=22/23/24) was gated on
    @Heatpump_State == 1. When timer=24 restores an off unit
    (#stateBeforeDHW == 0) the Heatpump_State update can arrive before the
    valve flip, so the chain never ran and curves, pump duty and pump test
    mode were left behind. Only the tank branch is gated now.
    - A reboot inside the 240 s window before timer=22 loses the pending
    chain. The boot check now detects leftover holding curves (valve on
    room, high == low, abov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
2026-10-12 Jeisha rules: restore curves before heat request after DHW
    timer=22 sent heat request 5 before the pre-DHW curves. The pump then
    reported holding curve + 5 (e.g. 57) as target, throttle() reset the
    request to 0, and the restored curve put the target below the outlet
    temperature: thermo-off right after DHW in mild weather.
    Send setCurves() first, then the heat request. Add test 21 for this
    sequence and adjust the expected command order in the other tests.
    Also simplify the boot check in timer=10 into one isset guard (all
    topics come from the same datagram) and move it before the pre-DHW
    snapshot.
2026-10-12 Jeisha rules: hold throttle heat request for 30 s after DHW
    Restoring the curves before the heat request (bb82fa0) still let the
    target drop to the bare curve for one datagram, below the outlet.
    Go back to heat request 5 first, then the curves, so the target goes
    holding curve -> holding curve + 5 -> restored curve + 5. timer=22
    now sets #throttleHold for 30 s (cleared by the new timer=26), so
    throttle() does not reset the heat request to 0 on the holding
    curve + 5 target. Before, it sent heat request 0 once per changed
    target/outlet/inlet topic; on the ESP8266 these stale commands
    interleaved with newer ones from the command buffer and the
    compressor stopped.
    Replace test 21 with a replay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
2026-10-15 ESP32: add setting to skip W5500 ethernet probe
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
